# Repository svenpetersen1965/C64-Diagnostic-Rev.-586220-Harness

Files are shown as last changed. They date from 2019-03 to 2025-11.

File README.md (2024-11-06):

# C64-Diagnostic-Rev.-586220-Harness
The Diagnostic Rev. 586220 is a widely accepted test tool for the Commodore C64. It tests the RAM, ROMs and 
the peripheral chips (VIC, SID, CIA). To test all interfaces, a feedback is required. This is provided by this harness.

Find more information about the cable making involved <a href="http://tech.guitarsite.de/cable_making.html">on my website</a>

# Rev. 0
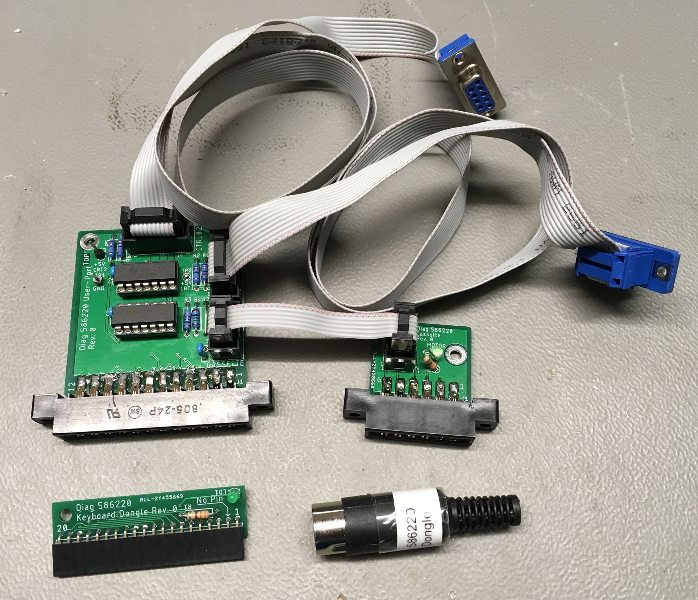
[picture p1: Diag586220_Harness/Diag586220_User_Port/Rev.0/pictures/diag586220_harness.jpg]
Diagnostic Harness

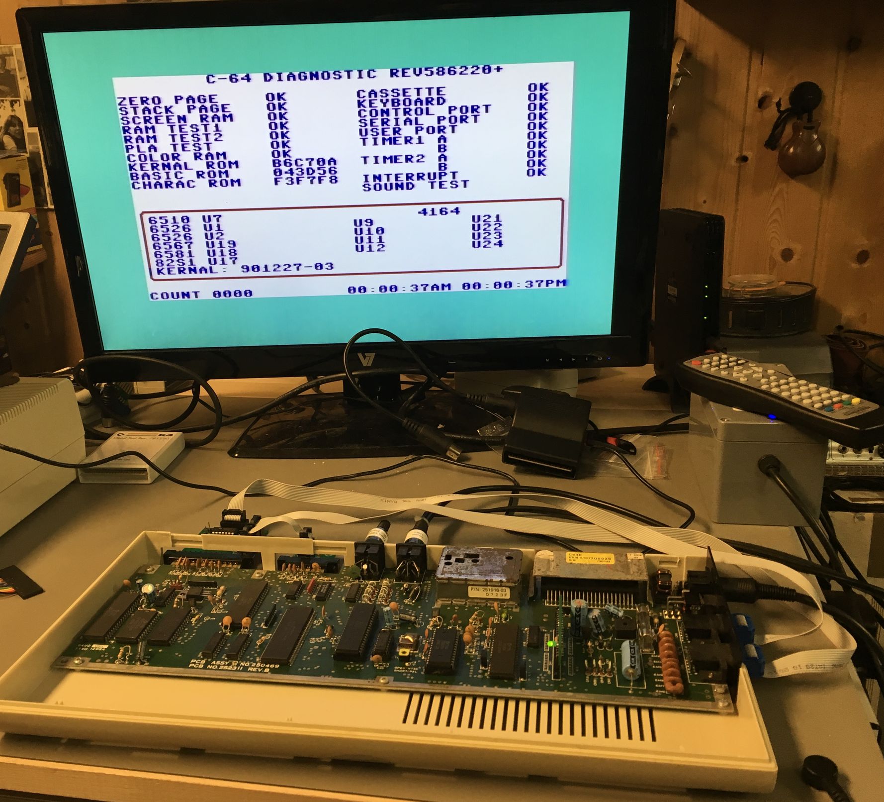
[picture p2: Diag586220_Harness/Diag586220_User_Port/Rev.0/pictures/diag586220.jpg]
Diagnostic 586220 running on a C64


This repository contains all eagle files, gerber files, BOM, descriptions and cable drawings. The main documentation is contained in the User Port section.

Depending on where the parts and pcbs are purchased, the price for the complete harness is less than 20€ (2019).

Now, a 3D printed case for the user port and the cassette donge is designed and the stl files etc. are available here. 

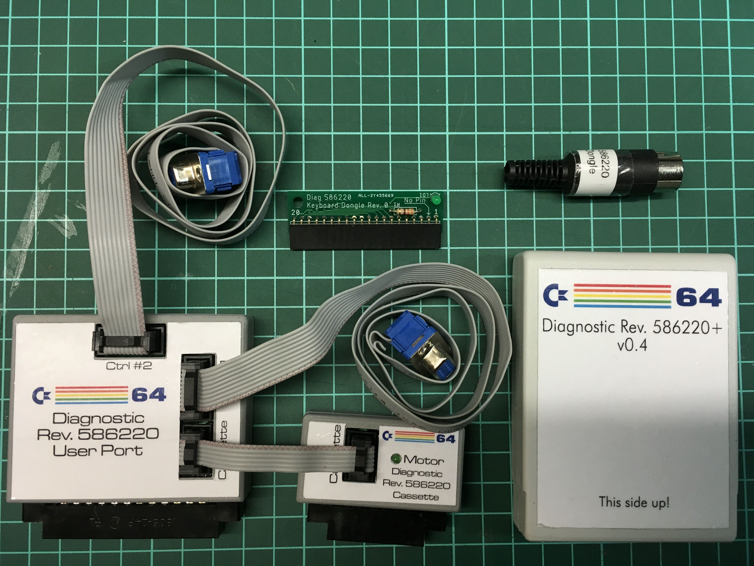
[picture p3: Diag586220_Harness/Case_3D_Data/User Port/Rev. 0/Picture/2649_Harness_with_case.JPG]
Diagnostic Harness with cases


# Rev. 1
Revision 1 is released now. It fixes the "False OK" of the Control Port test, while the keyboard dongle is inserted. This is a phenomenon, that applies to all sorts of harnesses for Diagnostic Rev. 586220. Please refer to <a src="http://tech.guitarsite.de/c64_diag_harness.html">my website</a>

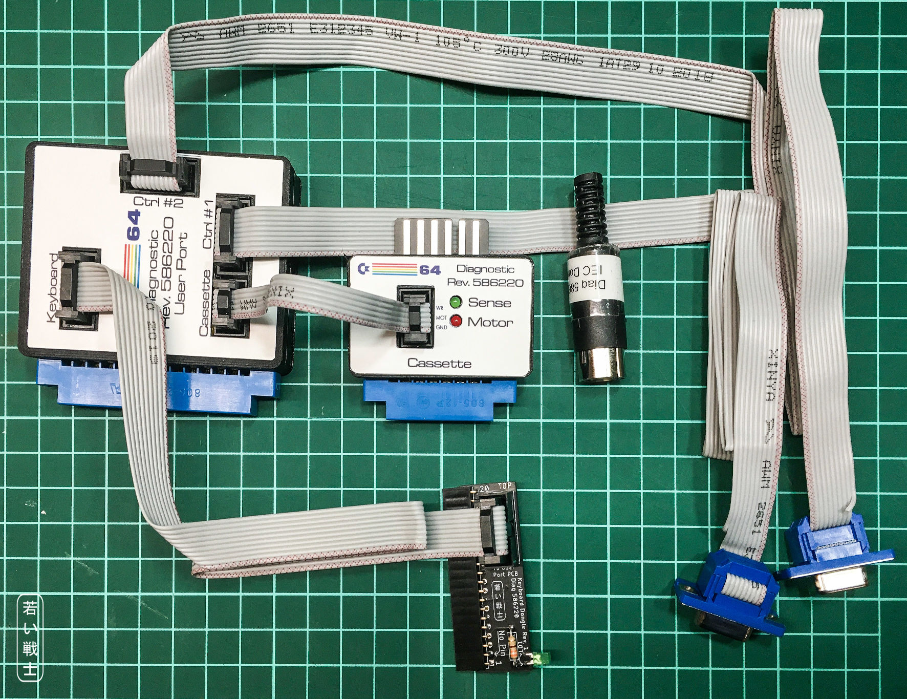
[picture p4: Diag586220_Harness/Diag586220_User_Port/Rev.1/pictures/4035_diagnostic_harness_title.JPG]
Diagnostic Harness Rev. 1


# Extended Keyboard Dongle (do not build, unless you are sure, what it is required for)
A fix for existing harnesses is the <b>extended</b> Keyboard Dongle. It can be combined with Rev. 0 of this harness and all other Harnesses. It only requires a connection to the Cassette Port Dongle. It is not required with Rev. 1 of the harness or later. 

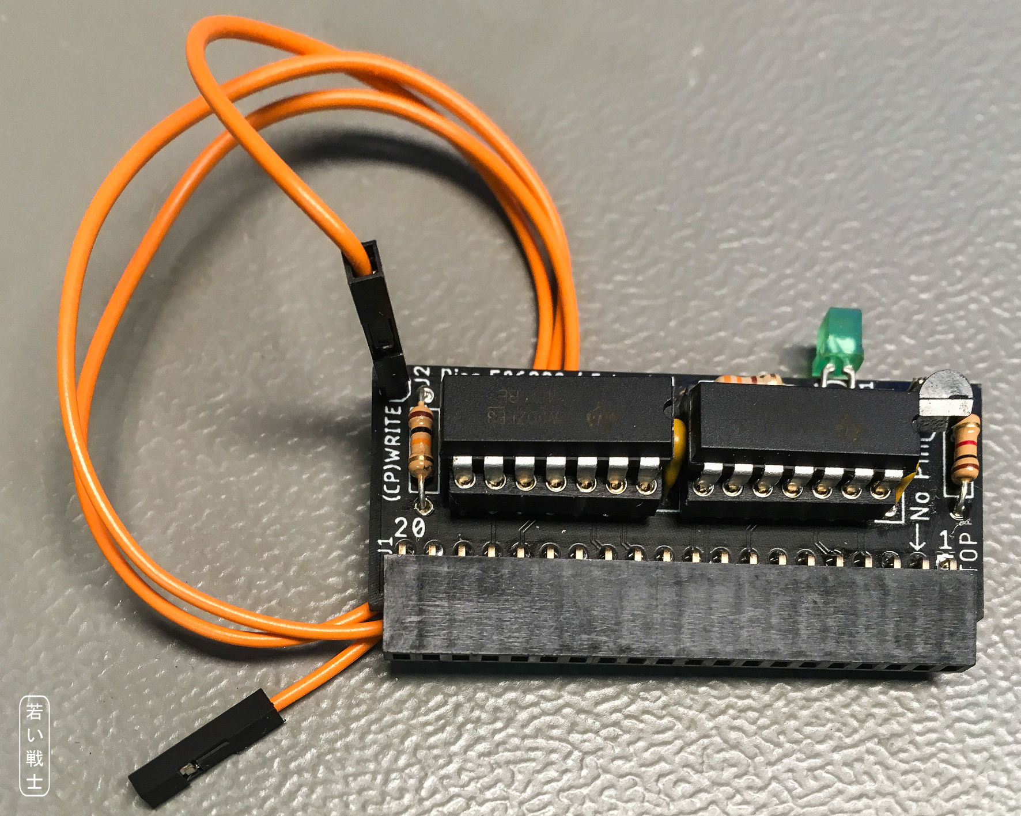
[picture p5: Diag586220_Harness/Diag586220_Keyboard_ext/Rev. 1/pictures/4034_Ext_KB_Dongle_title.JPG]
Extended keyboard Dongle


# Keyboard dongle with 90° header
Some people want to test the C64 mainboard while being mounted. The keyboard cable connector is conflicting here. Some leave out the strain relief. This is not a great solution. A 90° boc pin header can be used insted of the vertical one. This swapps the pins, due to a different orientation. Since the symmetrical pinning of the header and the non-directional properties of the analog switches, this does not matter and is working fine. I only build this kind of KB dongle now.

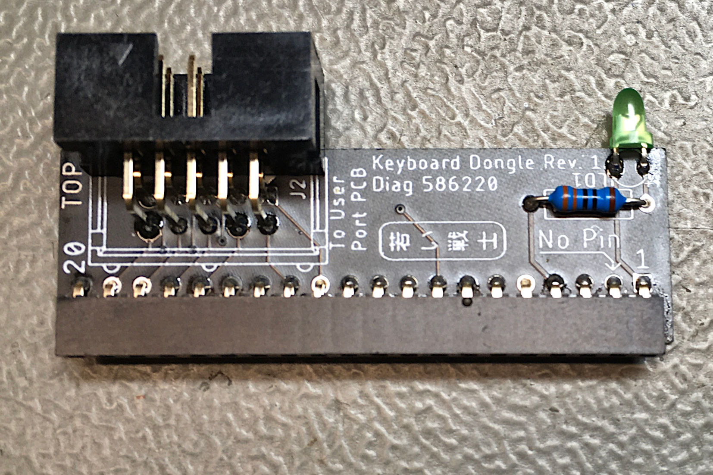
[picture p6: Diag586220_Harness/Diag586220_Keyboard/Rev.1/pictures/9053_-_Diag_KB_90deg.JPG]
Keyboard Dongle with 90° pin header


# The SMD Version
This version has no functional updates compared to Rev. 2 of the UP PCB and Rev. 1 of the Cassette SMD. Some prefer building SMD assemblies (me included). It is now fully tested.

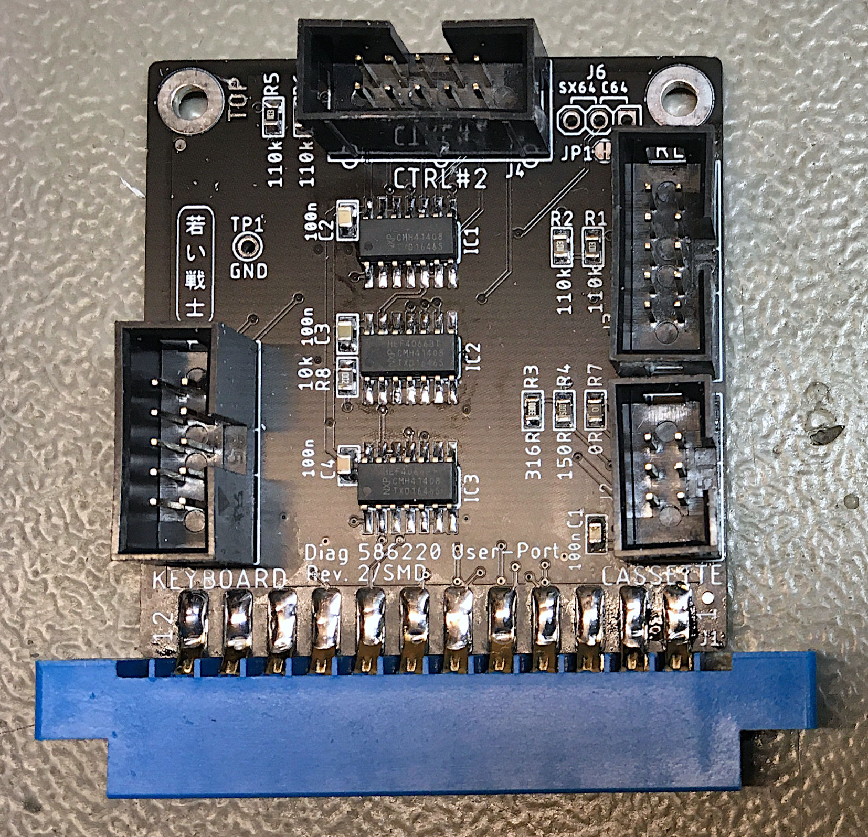
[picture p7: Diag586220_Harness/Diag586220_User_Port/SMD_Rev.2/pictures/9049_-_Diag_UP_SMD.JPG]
UP PCB R1v. 2/SMD
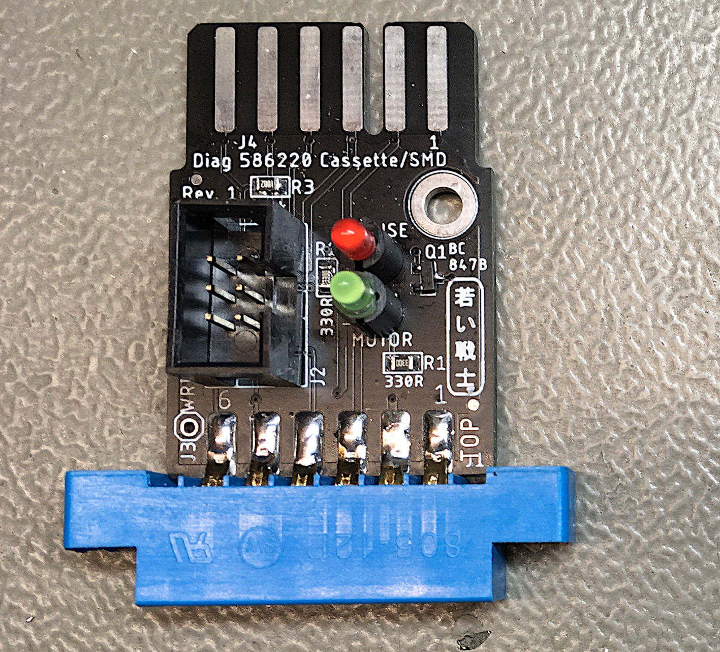
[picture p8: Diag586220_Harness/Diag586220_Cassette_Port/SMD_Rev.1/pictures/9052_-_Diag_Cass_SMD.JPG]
CP PCB Rev. 1/SMD
   

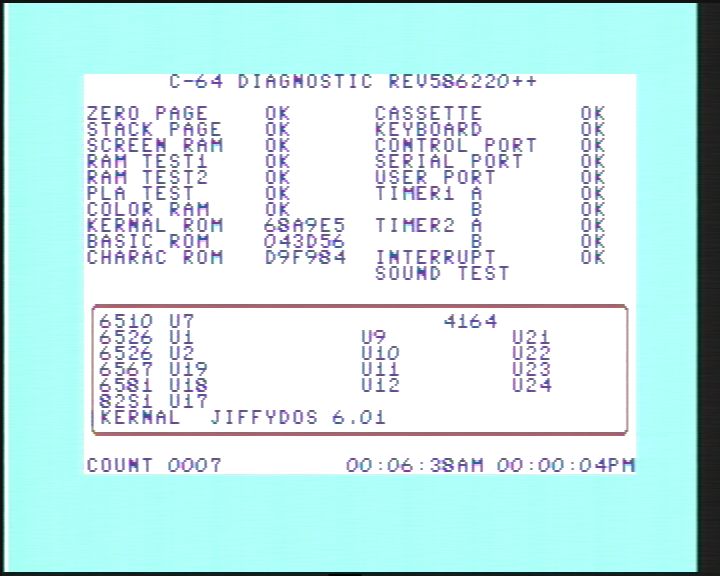
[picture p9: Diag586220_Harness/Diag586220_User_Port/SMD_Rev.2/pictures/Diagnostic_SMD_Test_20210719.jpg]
Diagnostic test


# Recommended Screws
* For the case, I have used 2.9mm x 9.5mm (self taping) screws for sheet metal (C 2,9x9,5H, DIN 7981).  
* For mounting the optional slide switch: DIN 7985, M2x6
* For mounting the optional voltmeter: 2.2mm x 4.5mm (self taping) screws for sheet metal (C 2,2x4,5H, DIN 7981). 

# C128 diagnostics
They keyboard PCB for the C128 is released now and included in this repository. 

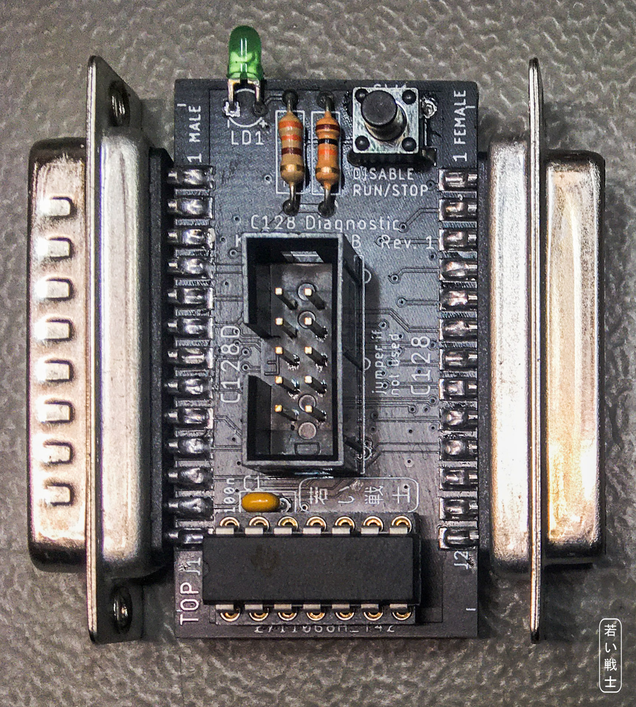
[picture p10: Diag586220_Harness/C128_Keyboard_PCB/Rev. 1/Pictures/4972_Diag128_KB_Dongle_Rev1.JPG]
C128 KB Dongle


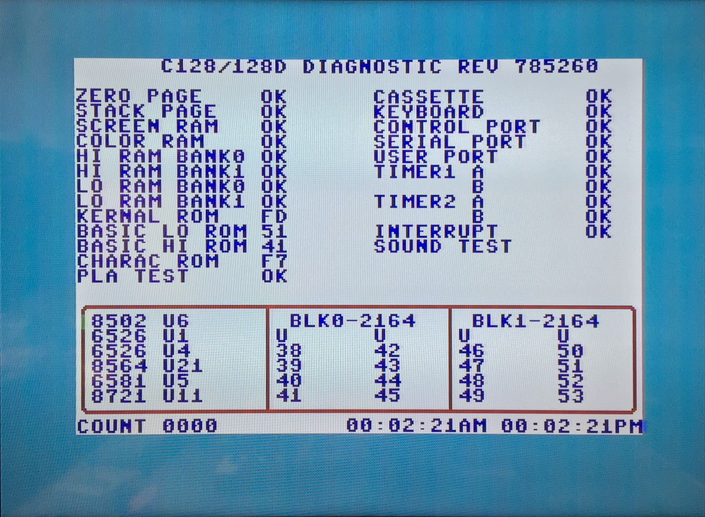
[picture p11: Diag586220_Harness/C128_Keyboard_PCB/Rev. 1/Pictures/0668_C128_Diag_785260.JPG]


A cartridge with the Diagnostic Rev. 785260 software is required. I recommend using the <a href="https://github.com/bwack/Versa64Cart">Versa64cart</a> for this purpose. Other 8k generic cartridges might also be working. /EXROM and /GAME have to be HIGH/open.

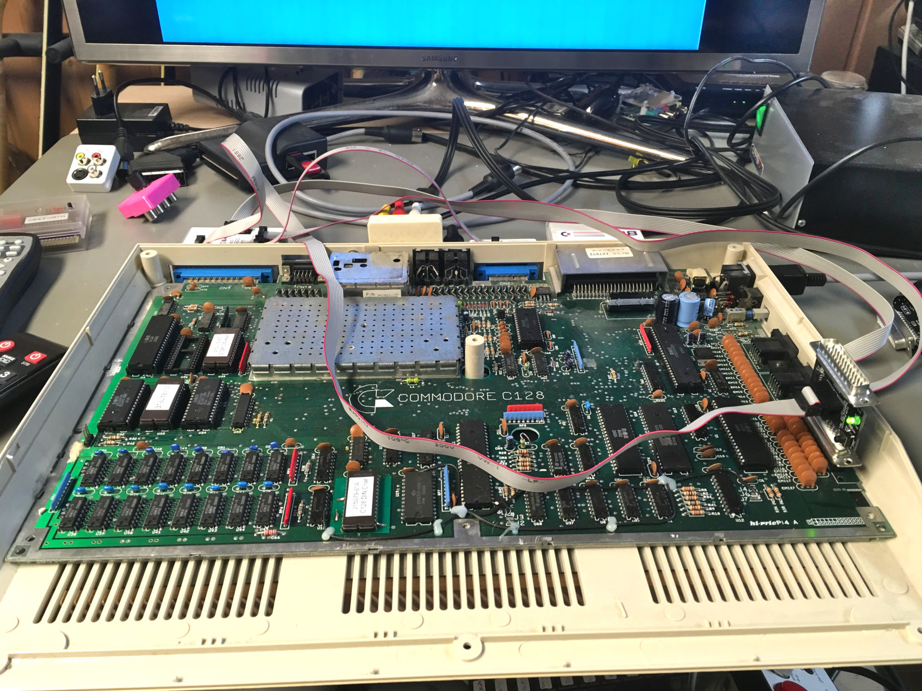
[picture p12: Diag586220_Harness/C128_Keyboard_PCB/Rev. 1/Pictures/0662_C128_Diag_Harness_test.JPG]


The <b>C128D and C128D-CR</b> require a longer cable (1m) between the user port PCB and the Cassette port dongle. Both work with the <b>C128D Diagnostic Rev. 785260</b>.  The keyboard ribbon cable should be 90cm for the C128D.

The cassette port ribbon cable requires to be 25cm long for the C128 and 70cm long for the C128D/DCR.

The <b>C128D-CR</b> does not provide +5V at the keyboard D-Sub jack. The keyboard dongle <b>does not work</b> here. A solution needs to be developed.  

I have noticed, that not all female D-Sub connectors provide a proper contact with the pin header on the C128 mainboard. Please keep this in mind. The recommended type is Amphenol/FCI DB25S064TLF (Digikey 609-1519-ND, more sources in the BOM v1.1 or later). 

You might want to check out the 3D printed dongle case from <a href="https://www.thingiverse.com/thing:4602956">retrorewind.ca</a>.

# SX-64 Diagnostics
Diagnosing an SX/64 requires disconnecting the internal disk drive. A cassette port dongle cannot be used, so the analog switches for testing the control ports need to be switched manually. This is an option with teh User Port PCB Rev. 2.

Also the Keyboard can be tested with the C128 KB dongle and a gender changer.

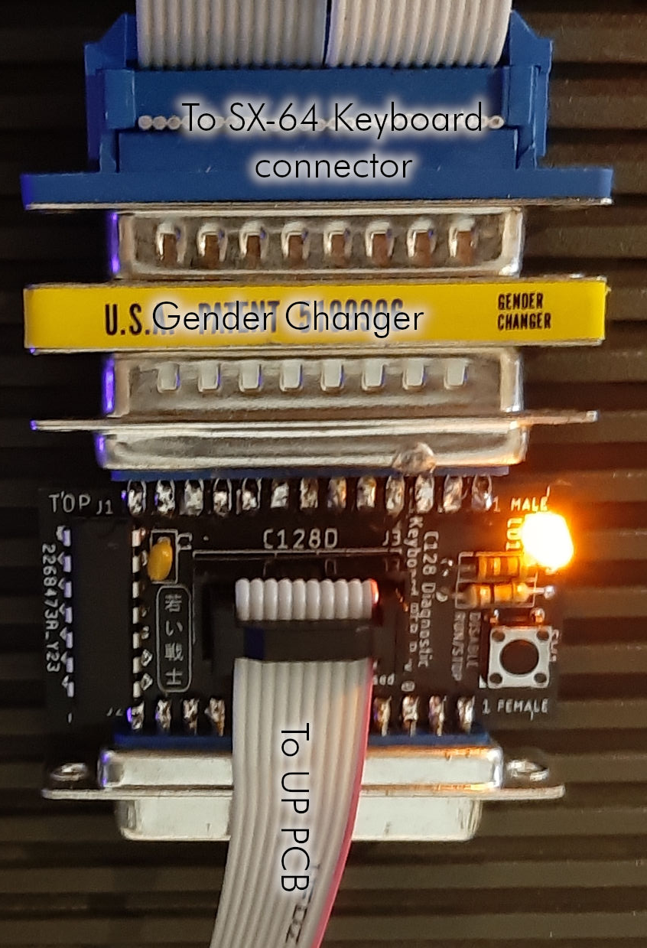
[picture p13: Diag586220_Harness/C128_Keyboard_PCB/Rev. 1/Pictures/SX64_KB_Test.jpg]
SX-64


The Diagnostic Rev. 586220++ is capable of detecting the SX-64 Kernal and then skip testing the cassette port.

# Other
you might want to check Jeff Birt's <a href="https://github.com/Jeff-Birt/COREi64_Dual_Diag_Cart_Case/tree/master">case</a> for the harness, too.

Find additional info about the harness on my <a href="http://tech.guitarsite.de/c64_diag_harness.html">website</a>.

Jeff Birt provided the information of the cable lengths for C128 diagnostics. This is part of the documentation now. 

# User Port PCB Rev. 2
The user Port PCB Rev. 2 fits into the User Port Case Rev. 1. It adds an option for the SX-64: Since the SX-64 has no
Cassette Port, the Feedbacks for the CVontrol Port are not switched automatically by the software. Rev. 2 allows to
switch on the feedbacks manually. A User Port Case for thei option has been made. It incorporates a cut out for a slide
switch (standard 19mm hole pitch). This switch can be connected top JP1. For this option the cutpad has to be cut open. 

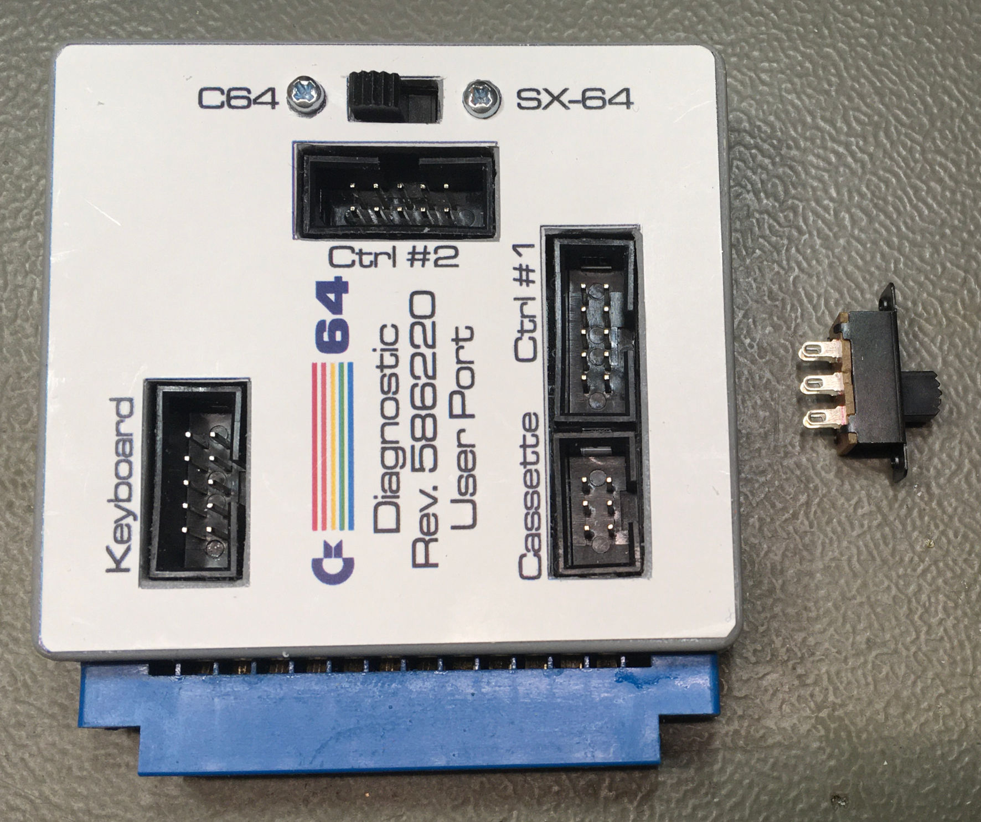
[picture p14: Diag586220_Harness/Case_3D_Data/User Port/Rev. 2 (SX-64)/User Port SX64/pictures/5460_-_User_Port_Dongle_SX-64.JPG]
User Port Case SX-64 option


# User Port PCB Rev. 3
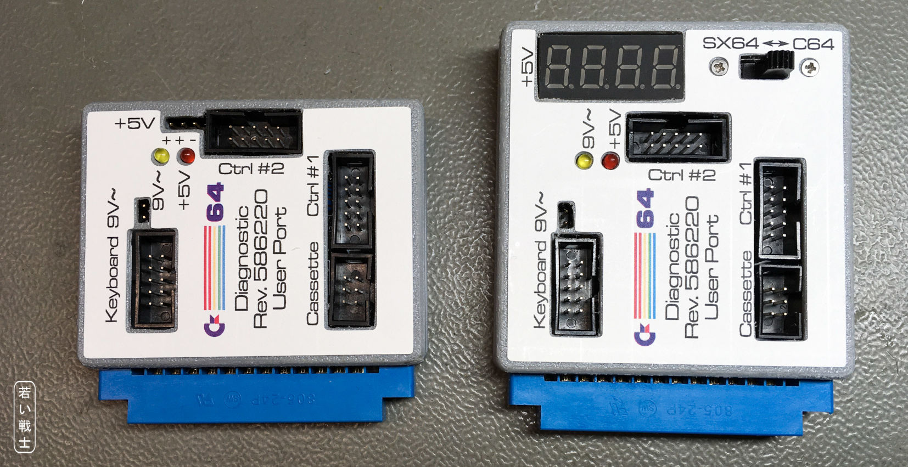
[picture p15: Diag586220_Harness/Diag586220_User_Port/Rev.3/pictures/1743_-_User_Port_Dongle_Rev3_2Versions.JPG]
User Port Rev. 3


The User Port Rev. 3 Dongle (THT and SMD versions in this repository) is providing two LED for voltage intocations (+5V and 9VAC). Further, there are pin headers for measuring those voltages at the user port. The +5V pin header allows connecting a 4 digit "precision" panel meter. I have some trust issues with those panel meters, but they are a nice light show.  

Nov. 2024: There is a new version of the case (the STLs are ending on "_noVM_SX.stl"). This version allows to measure the voltages at the pin headers with your multimeter and configure the SX64 or C64 option via jumper. That jumper should be the type with a "handle". 

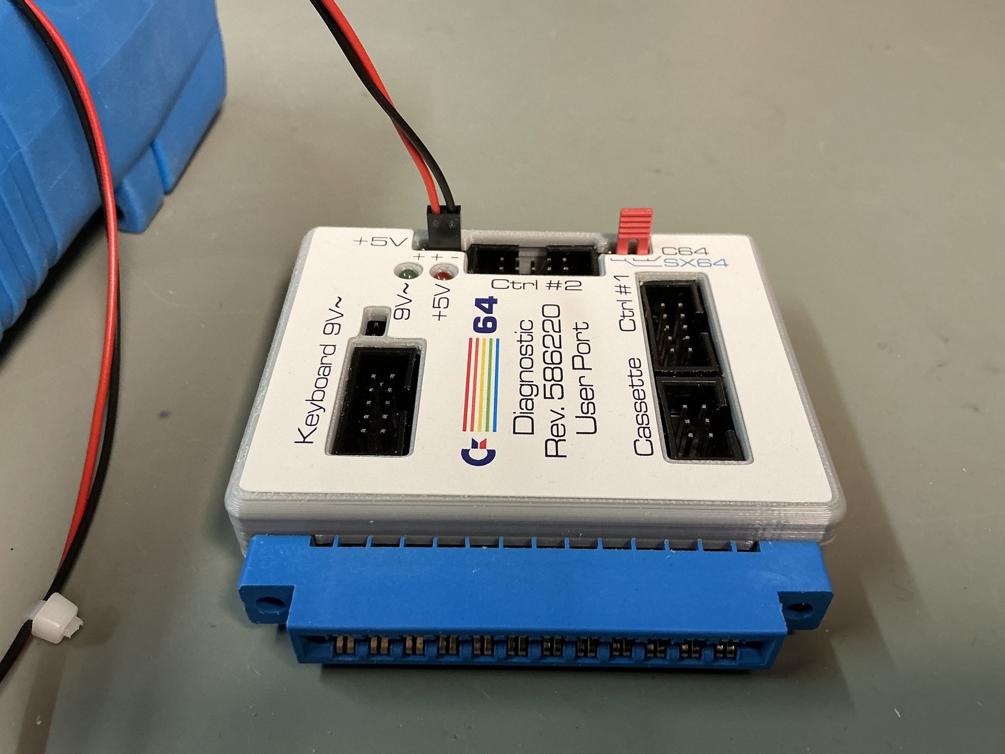
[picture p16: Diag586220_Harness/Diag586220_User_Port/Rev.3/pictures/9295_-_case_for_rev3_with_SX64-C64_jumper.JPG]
User Port Rev. 3/sx64-c64


<b>The solder bridge JP1 near the pin header J6 (which has to be placed) needs to be open!</b>

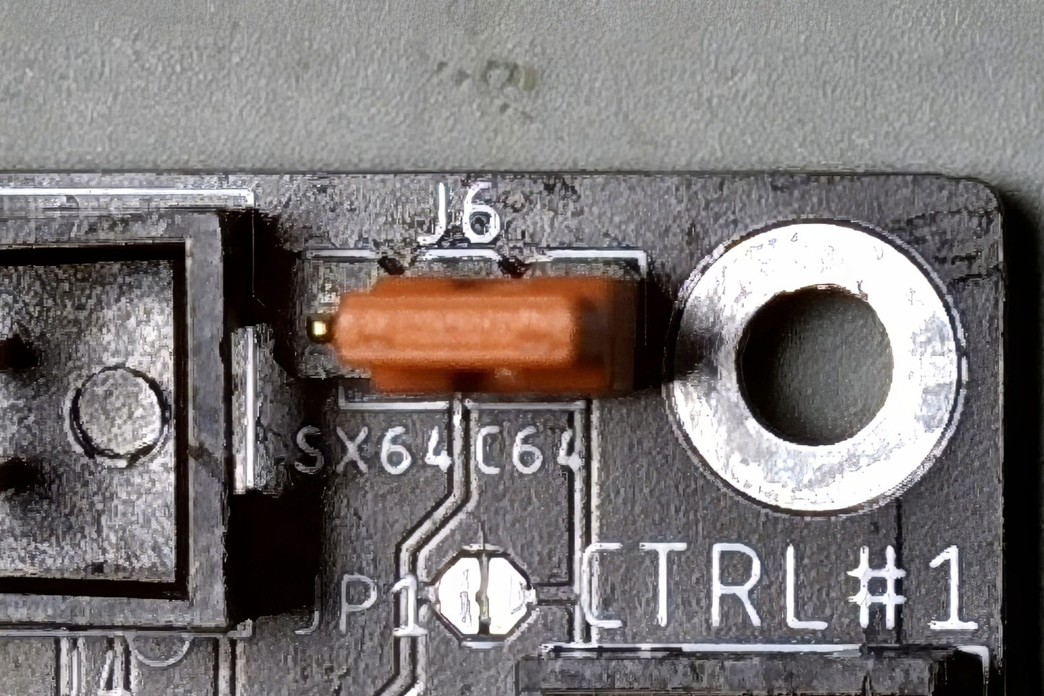
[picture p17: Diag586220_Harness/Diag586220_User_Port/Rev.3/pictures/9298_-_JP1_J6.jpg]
JP1 and J6


Therefore, it has to be cut along the gap with a scalpel or exacto knife. It is best to check the success with an ohmmeter/multimeter.

The cable for measuring the voltage (+5VDC and 9VAC) at the pin pin headers consists of two AWG24 wires, preferable in different colors, on one end is a two way Dupont connector, on the other end 4mm lab connectors. Holding them together with cable ties is maybe not such a bad idea.

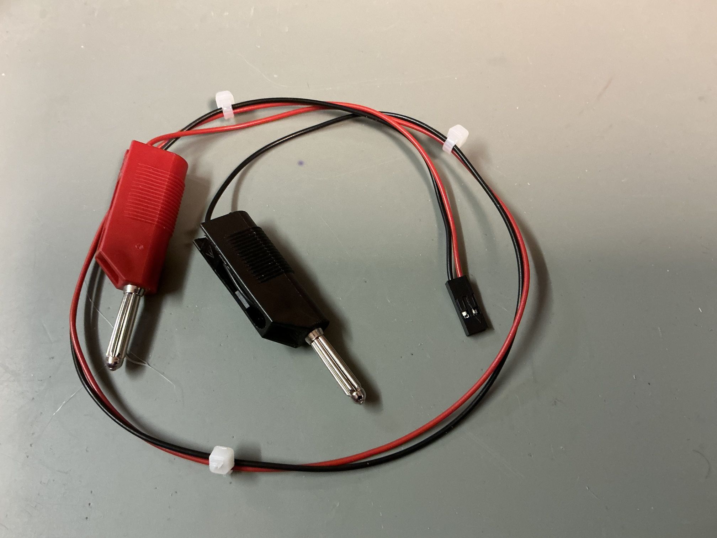
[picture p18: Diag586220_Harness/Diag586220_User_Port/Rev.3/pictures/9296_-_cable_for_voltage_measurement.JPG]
cable for multimeter


To prevent short circuit, you should plug the lab connectors in the multimeter first, there are some security multimeter connectors, too. 

# Analog Switch IC (User Port Dongle)
Originally, the analog switches are <b>4066</b>. The 74HC4066 was also tested and works perfectly.

# BOM Value
The BOM values are calculated in May 2020. The calculation is based on the item prices from reichelt.de. They might differ from distributor to distributor. The edge connector prices are based on ebay shoppings. The calculated prices do not include any shipping fees. 

* User Port PCB plus cables and IEC dongle: 13.38€
* Cassette Port Dongle: 4.99€
* Keyboard Dongle: 1.85€
* C128 Keyboard Dongle: 3.23€

The 3D printed cases and the labels are not included in the price calculation.

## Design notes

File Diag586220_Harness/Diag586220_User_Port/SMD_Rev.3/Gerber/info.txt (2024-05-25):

      
       Board: C64_Userport_Test_SMD
       Rev.:  3
  
       Files:
       ======
  
       All Gerber files are generated in extended gerber format (RS274X)
       *.TOP        : Film top copper
       *.BOT        :  -"- bottom copper
       *.STC        :  -"- top soldermask 
       *.STS        :  -"- bottom soldermask
       *.PLC        :  -"- silk screen top
       *.PLS        :  -"- silk screen bottom
       *.CRC        :  -"- cream top
       *.DK         : Drills plated Through (Excellon)
       *.NDK        : Drills not plated Through (Excellon)
       *.OUT        : Board outline

       Board Size:
       ===========
       Length     :   55.0 mm
       Width      :   53.0 mm
       Thickness  :   1.6 mm
       Material   :   FR 4
       Copper     :   35 um
       Surface    :   HASL
       
       Remarks:
       ========
       drill >= 0.35mm
       width >= 8mil
       distance >= 6mil

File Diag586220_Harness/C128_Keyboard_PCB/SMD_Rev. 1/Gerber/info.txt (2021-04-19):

      
       Board: C128_Keyb_Test_SMD
       Rev.:  1
  
       Files:
       ======
  
       All Gerber files are generated in extended gerber format (RS274X)
       *.TOP        : Film top copper
       *.BOT        :  -"- bottom copper
       *.STC        :  -"- top soldermask 
       *.STS        :  -"- bottom soldermask
       *.PLC        :  -"- silk screen top
       *.PLS        :  -"- silk screen bottom
       *.CRC        :  -"- top cream
       *.DK         : Drills plated Through (Excellon)
       *.NDK        : Drills not plated Through (Excellon)
       *.OUT        : Board outline

       Board Size:
       ===========
       Length     :   52.0 mm
       Width      :   28.0 mm
       Thickness  :   1.6 mm
       Material   :   FR 4
       Copper     :   35 um
       Surface    :   HASL
       
       Remarks:
       ========
       drill >= 0.35mm
       width >= 8mil
       distance >= 6mil

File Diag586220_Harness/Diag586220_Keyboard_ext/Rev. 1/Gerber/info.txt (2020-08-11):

      
       Board: C64_Keyb-Test-ext
       Rev.:  1
  
       Files:
       ======
  
       All Gerber files are generated in extended gerber format (RS274X)
       *.TOP        : Film top copper
       *.BOT        :  -"- bottom copper
       *.STC        :  -"- top soldermask 
       *.STS        :  -"- bottom soldermask
       *.PLC        :  -"- silk screen top
       *.PLS        :  -"- silk screen bottom 
       *.DK         : Drills plated Through (Excellon)
       *.NDK        : Drills not plated Through (Excellon)
       *.OUT        : Board outline

       Board Size:
       ===========
       Length     :   55.0 mm
       Width      :   22.0 mm
       Thickness  :   1.6 mm
       Material   :   FR 4
       Copper     :   35 um
       Surface    :   HASL
       
       Remarks:
       ========
       drills >= 0.35mm
       width >= 8mil
       distance >= 6mil

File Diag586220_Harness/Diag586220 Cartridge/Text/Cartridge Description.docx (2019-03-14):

Diagnostic Rev. 586220 Cartridge

Short description

The diagnostic cartridge can be easily built from existing parts. All information was obtained from the website “World of Jani” (http://blog.worldofjani.com/?p=164). The binary file for programming the (27C512) EPROM was generated with the cartconv tool from the VICE C64 emulator from the 586220plus v0.4 CRT file, which was also downloaded from World of Jani.

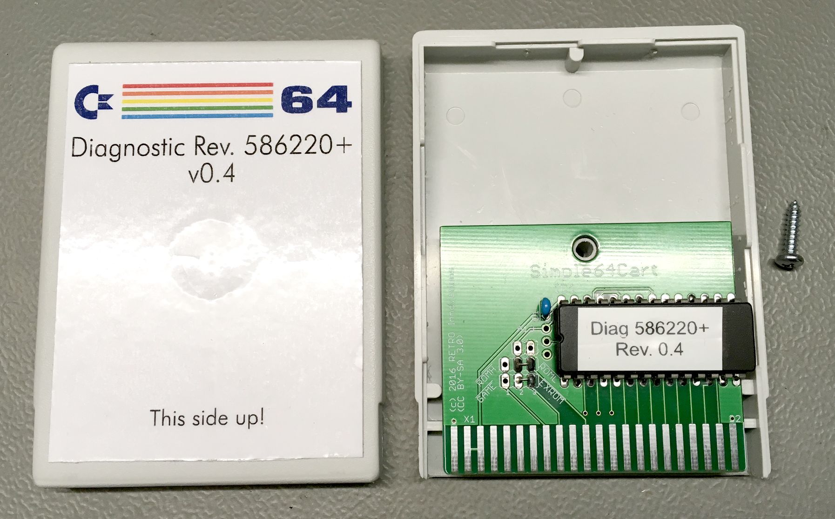
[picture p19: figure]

Figure 1: Diagnostic Cartridge with SimpleC64Cart

The cartridge can be made with a variety of existing cartridge boards. Here the SimpleC64Cart (http://www.go4retro.com/downloads/Simple64Cart/) was used.

The correct settings are /GAME=HIGH (open), /EXROM=LOW (closed jumper), and the /OE of the EPROM is connected to /ROML.

The SimpleC64Cart has a fixed setting for A13, A14 and A15 (all HIGH), so the binary file has to be loaded to Address 0xE000.

The cartridge case was purchased from retro-store.de (https://restore-store.de/home/117-modulgehaeuse-c64c128-grau-ohne-labelfeld.html). Those cases are low profile, which is the reason, why the EPROM is not socketed and the jumpers are bridged with wires.

Cartridge Description.docx 14.03.2019 09:13 Drafted by Sven Petersen Page 2 of 2 Doc.-No.: 000-6-00-00

Cartridge Description.docx 14.03.2019 09:13 Drafted by Sven Petersen Page 1 of 1

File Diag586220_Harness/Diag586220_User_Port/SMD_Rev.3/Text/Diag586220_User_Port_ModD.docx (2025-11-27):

Diagnostic Rev. 586220 Harness - User Port SMD Rev. 3

Module Description

The User Port module is the central part of the Diagnostic Rev. 586220 harness. It provides the required feedback connections for testing the C64’s CIA U2, which is connected to the user port. It also holds the analog switches, which are required to test the Control Ports and the feedback connections for testing the cassette port.

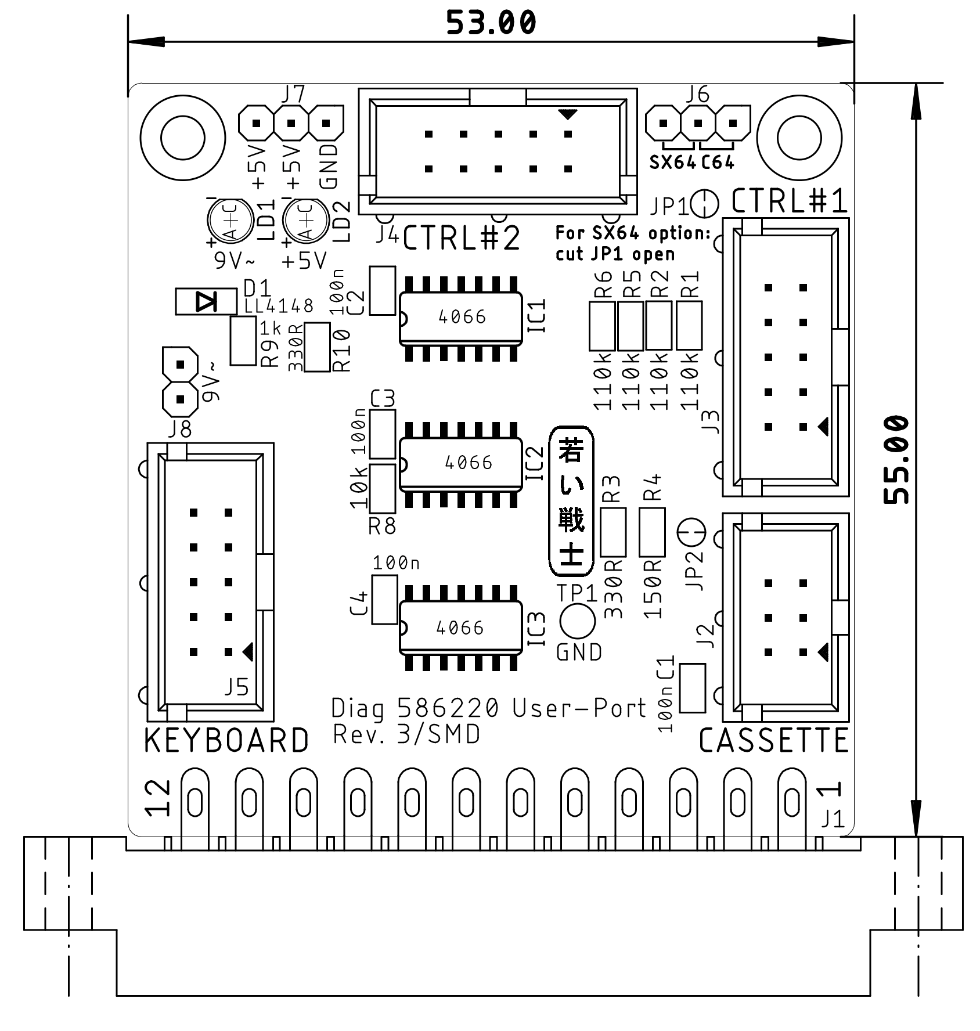
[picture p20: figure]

Figure 1: User Port SMD PCB Rev. 3

The MOTOR output signal of the cassette port has approximately a 6V level. To use it as a control signal for operating logic devices, a voltage divider consisting out of a 150Ω resistor and a 320Ω (316Ω works here, 330Ω should work as well) resistor is required, which has a ratio of about 0.7.

This way, the MOTOR signal is fed back to the WRITE pin and is also used for switching the analog switches between the joystick signals of both control ports.


Figure 2: User Port Dongle Rev. 3, without and with a panel voltmeter

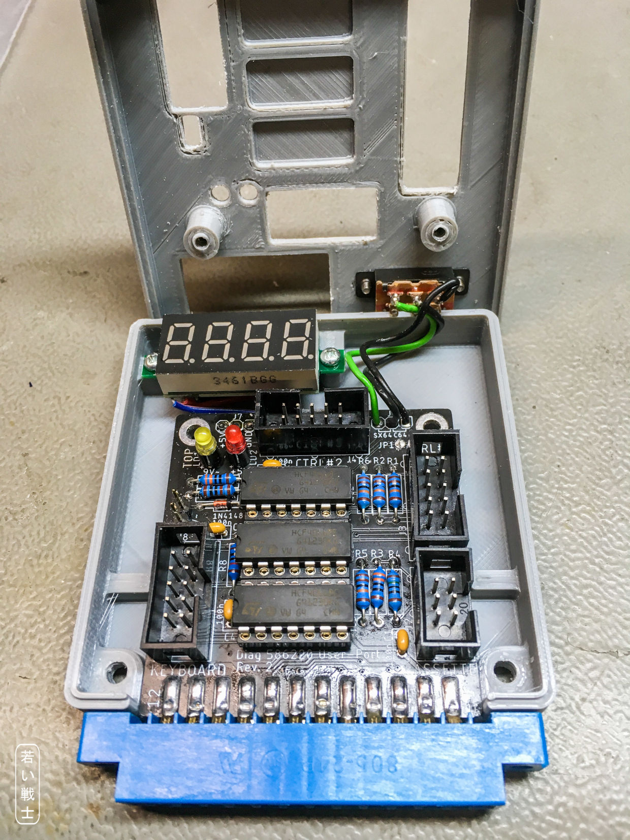
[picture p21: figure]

Figure 3: Installation of the panel voltmeter and the switch for SX/64 and C64 mode (THT Board)

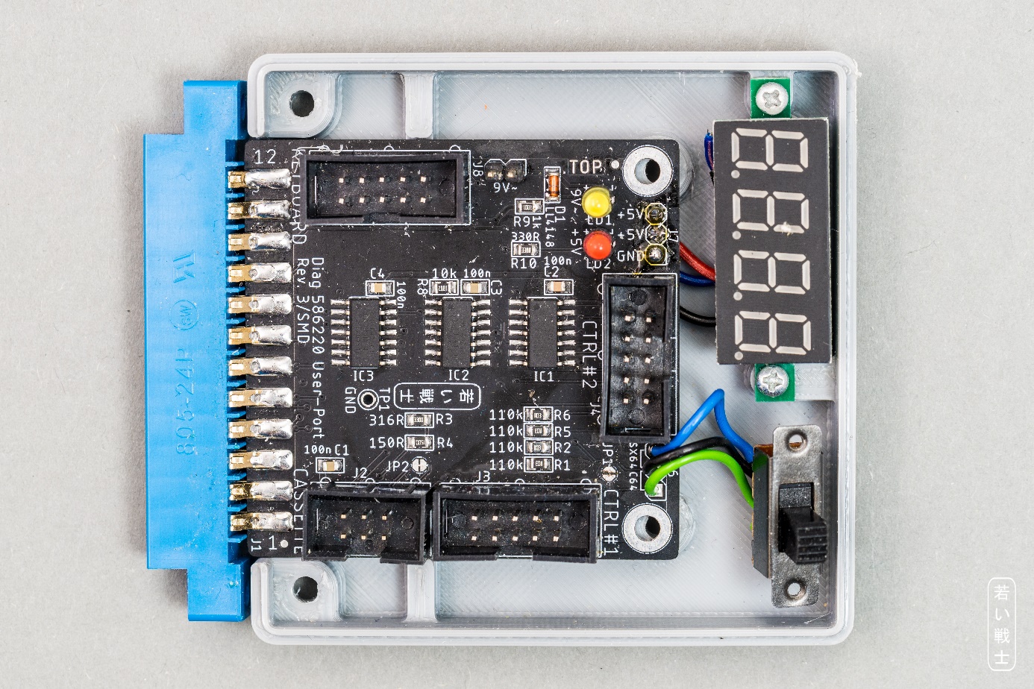
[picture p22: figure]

Figure 4: Installation without the panel voltmeter, but the pin headers for voltage measurement.

# Rev. 1

New on Rev. 1 are the analog switches for the keyboard feedbacks. This feature requires a ribbon cable to the keyboard PCB (Rev. 1). It does not connect to the Keyboard PCB Rev. 0.

The reason for this modification:

The feedbacks on keyboard dongle are identical to the feedback provided by the analog switches for the control port feedback. Since the feedbacks on the keyboard dongle are permanent, the analog switches are not effective and the control ports are not fully tested. This can lead to a false “OK”.

The new version can open the keyboard feedbacks with additional analog switches, so it is not required to remove the keyboard dongle for proper testing anymore.

# The SX-64 test feature (Rev. 2 and later)

The SX-64 does not provide a cassette port. Since the control port (and keyboard) feedbacks are switched by the cassette port MOTOR signal, J6 provides a manual switching option. It can either be jumpered or a toggle switch can be connected. Connecting J6 pin 1 and pin 2 configures the regular C64 setup (the feedbacks are controlled by MOTOR), connecting pin 3 and pin 2 configured the control port feedbacks being switched on permanently for the SX-64 option. For switching between options, the cut pad JP1 has to be opened. On default (closed) it selects the C64 option.

By default, the C64 only mode is selected, which meansJP1 is closed. Do not connect a switch to J6 without opening JP1.

The keyboard testing of the SX-64 requires the C128 keyboard PCB and a DB female-female gender changer. For complete SX-64 testing, the diagnostic software has to be run in C64 mode (control port feedbacks off, keyboard feedbacks on) at least one pass and then in SX-64 mode (control port feedbacks on, keyboard feedbacks off).

# Rev. 3: Voltage indicators and voltmeter

The purpose of the voltmeter is measuring the +5VDC inside the C64, which does make sense. A too low voltage here might indicate a bad power switch or a bad/oxidized power jack.

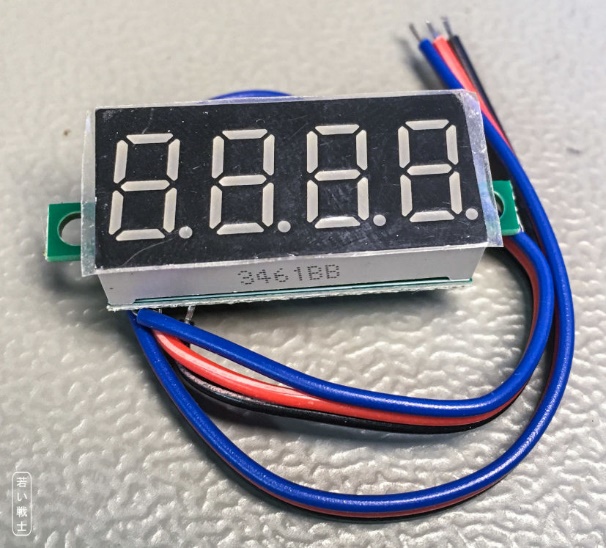
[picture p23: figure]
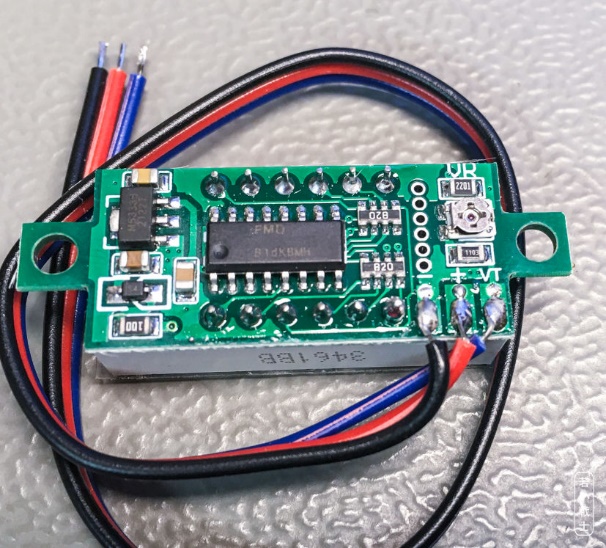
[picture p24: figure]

Figure 5: Front and back of the 0.36" 4-digit voltmeter

Previously, three-digit and four-digit models have been tested. The three-digit models are not suitable, since they showed an error of almost 100mV. The four-digit models can be adjusted on a little potentiometer. Adjustment is required and should be performed before the assembled PCB is installed in the case.

The adjustment is best performed by measuring the voltage between the GND pin and one of the +5V pins of J7, then adjusting the reading of the voltmeter at the potentiometer on the back side. This potentiometer is shown in Figure 5: Front and back of the 0.36" 4-digit voltmeter.

Note: The panel voltmeters, that I have bought for this project were sufficiently accurate, but I would not grant for all 4 digit “precision panel meters, so the recommended configuration is to install a pin header and perform the measurement with a multimeter.

# Pinouts

## User Port

J1- Edge Connector (2x12, 3.96mm pitch)

Pin | Signal | Pin | Signal
1 | GND | A | GND
2 | +5V | B | /FLAG2
3 | /RESET | C | PB0
4 | CNT1 | D | PB1
5 | SP1 | E | PB2
6 | CNT2 | F | PB3
7 | SP2 | H | PB4
8 | /PC2 | J | PB5
9 | ATN | K | PB6
10 | 9VAC(1) | L | PB7
11 | 9VAC(2) | M | PA2
12 | GND | N | GND

## Cassette Port

J2 – 2x3 pin header for a ribbon cable connected to the cassette port PCB (project number 114).

Pin | Signal | Pin | Signal
1 | GND | 2 | n.c.
3 | MOTOR | 4 | READ
5 | WRITE | 6 | SENSE

## Control Port #1

J3 – 2x5 pin header for a ribbon cable which connects via a D-SUB 9 (female) to the control port.

Pin | D-SUB | Signal | Pin | D-SUB | Signal
1 | 1 | JOYA0 (up) | 2 | 6 | FIREA
3 | 2 | JOYA1 (down) | 4 | 7 | +5VCTR1
5 | 3 | JOYA2 (left) | 6 | 8 | n.c. (GND)
7 | 4 | JOYA3 (right) | 8 | 9 | POTXA
9 | 5 | POTYA | 10 | - | n.c.

## Control Port #2

J4 – 2x5 pin header for a ribbon cable which connects via a D-SUB 9 (female) to the control port.

Pin | D-SUB | Signal | Pin | D-SUB | Signal
1 | 1 | JOYB0 (up) | 2 | 6 | FIREB
3 | 2 | JOYB1 (down) | 4 | 7 | +5VCTR2
5 | 3 | JOYB2 (left) | 6 | 8 | n.c. (GND)
7 | 4 | JOYB3 (right) | 8 | 9 | POTXB
9 | 5 | POTYB | 10 | - | n.c.

## Keyboard

J5 – 2x5 pin header for a ribbon cable which connects to the keyboard PCB.

Pin | Signal | Pin | Signal
1 | Keyboard PB0 | 2 | Keyboard PA0
3 | Keyboard PB4 | 4 | Keyboard PA4
5 | Keyboard PB3 | 6 | Keyboard PA3
7 | Keyboard PB2 | 8 | Keyboard PA2
9 | Keyboard PB1 | 10 | Keyboard PA1

SX-64 Option

J6 – 1x3 pin header (pitch 2.54mm)

Pin | Signal
1 | WRITE
2 | WRITE*
3 | +5V

To use J 6 for switching between SX-64 and C64, cut open JP1. This is the cut pad right beside J6.

Connection pin 1-2 selects the C64 option, connecting pin 2-3 selects the SX-64 option, which switches on the control port feedbacks.

## Panelmeter Connector

J7 – 1x3 pin header, 2.54mm pitch

Pin | Signal | Voltmeter
1 | GND | -
2 | +5V | +
3 | +5V | VT

## 9VAC Connector

J8 - 1x2 pin header, 2.54mm pitch

Pin | Signal
1 | 9VAC1
2 | 9VAC2

# Interconnects

## User Port

Pin | Signal | | Signal | Pin
4 | CNT1 | « | CNT2 | 6
5 | SP1 | « | SP2 | 7
8 | /PC2 | « | /FLAG2 | B
9 | ATN | « | PA2 | M
C | PB0 | « | PB4 | H
D | PB1 | « | PB5 | J
E | PB2 | « | PB6 | K
F | PB3 | « | PB7 | L

## Cassette Port

Pin | Signal | | Signal | Pin
1 | GND | | n/c | 2
3 | MOTOR | Volt.div. | WRITE | 5
4 | READ | « | SENSE | 6

## Control Ports

Signal | | Signal
FIREA | switched by MOTOR | FIREB
JOYA0 | switched by MOTOR | JOYB0
JOYA1 | switched by MOTOR | JOYB1
JOYA2 | switched by MOTOR | JOYB2
JOYA3 | switched by MOTOR | JOYB3
POTXA | via 110kΩ (R1) | +5V (CTR 1)
POTYA | via 110kΩ (R2) | +5V (CTR 1)
POTXB | via 110kΩ (R5) | +5V (CTR 2)
POTYB | via 110kΩ (R6) | +5V (CTR 2)

The digital signals of the control ports are connected by an analog switch. A HIGH level of the MOTOR signal will switch on.

The POT (paddle) signals are tested with a fix resistor of 110k, that is connected to the +5V provided by the respective control port.

# Cables

## User Port/Cassette Port Cable

One cable as shown in Doc.-No. 113-3-01-01 is required. It connects to J2. This cable needs to be longer for C128

## User Port/Control Cables

Two cables as shown in Doc.-Nr. 113-3-02-01 are required. They connect to J3 and J4.

## User Port/Keyboard PCB Cable

One cable as shown in Doc.-No. 113-3-04-01 is required. It connects to J5 and the keyboard PCB (C64 or C128). For the C128 this cable has to be longer.

## The IEC-Dongle

The IEC-Dongle is not attached to the PCB, it is an extra built.

6p. DIN plug, connect according to Doc.-No. 113-3-03-01

Pin | Signal | | Signal | Pin
1 | SRQ | « | DATA | 5
3 | ATN | « | CLK | 4

# Block diagram of the Diagnostic Harness Rev. 3

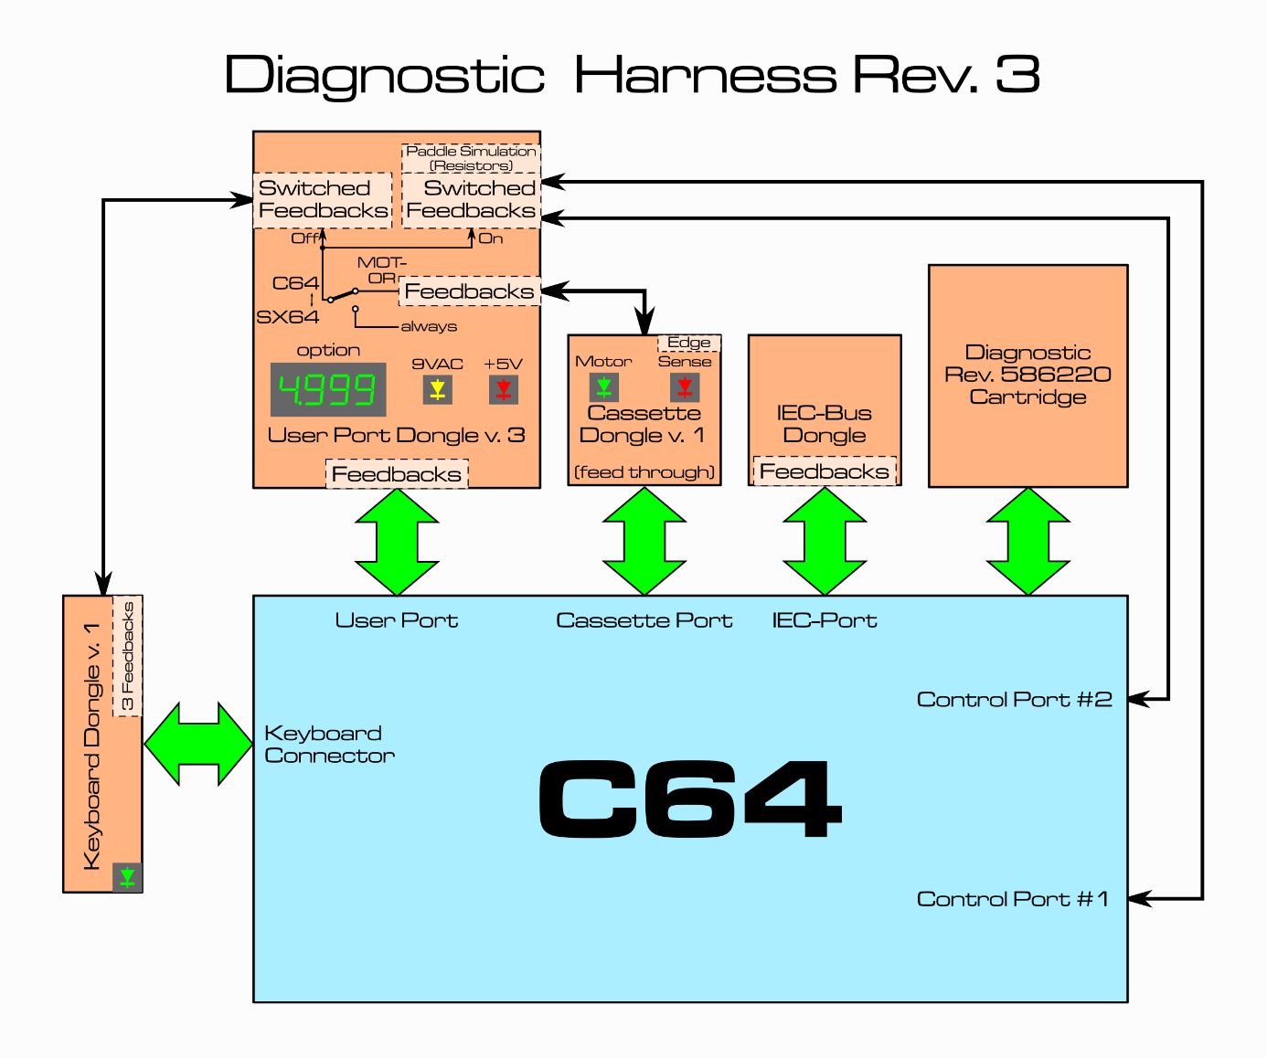
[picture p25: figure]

# Connecting the Voltmeter

The Voltmeter has three connections:
+ = positive supply voltage. It is connected to J7, Pin 2 (+5V)
- = negative supply voltage. It is connected to J7, Pin 1 (GND)
VT = measured voltage. It is connected to J7, Pin 3 (+5V)

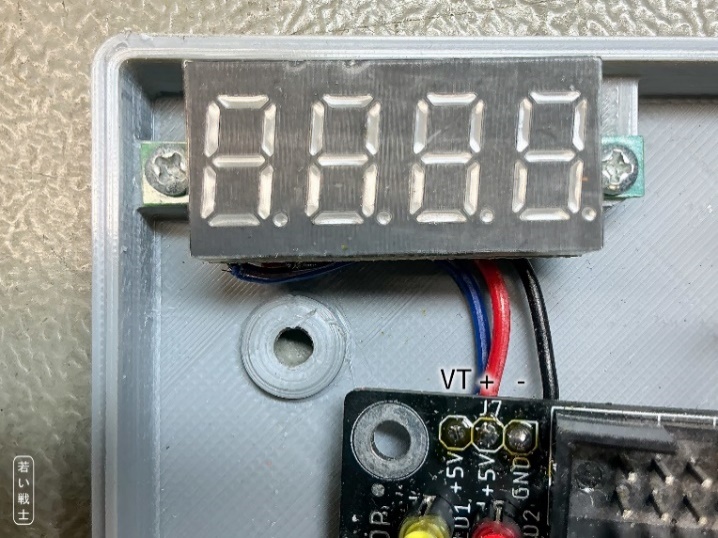
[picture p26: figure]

Figure 6: Connection of the panel voltmeter

# Revision History

## BOM v0.1 → v0.2

- Pos. 6: value 120k →110k
- Pos. 8: value 320R →316R

## Rev. 0 → Rev. 1

- This is a PCB revision
- Analog switches added (IC3)
- Pin header added (J5)
- New Ribbon Cable
- 3D printed case (Rev. 1) is required

## Rev. 1 → Rev. 2

- This is a PCB revision
- Pin header J6 and cup pad JP1 added
- It can either be installed in the Rev. 1 3D printed case, if no switch option SX64 is desired or in the User Port Case SX-64, which provides mounting holes for a toggle switch (19mm hole distance, standard switch).

## Rev. 2 → Rev. 2 SMD

- This is the Rev. 2 with SMD parts for easier fabrication. No other technical changes were done.

## Rev. 2 SMD → Rev. 3 SMD

- LEDs added for presence indication of +5V and 9VAC
- Connector for panel meter
- Connector for 9VAC
- New 3D printed cases.

Diag586220_User_Port_ModD.docx 27.11.2025 13:32 Drafted by Sven Petersen Page 2 of 2 Doc.-No.: 179-6-01-03

Diag586220_User_Port_ModD.docx 27.11.2025 13:32 Drafted by Sven Petersen Page 1 of 1 Doc.-No.: 113-6-01-01

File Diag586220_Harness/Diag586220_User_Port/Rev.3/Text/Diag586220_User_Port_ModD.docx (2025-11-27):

Diagnostic Rev. 586220 Harness - User Port Rev. 3

Module Description

# Introduction

The User Port module is the central part of the Diagnostic Rev. 586220 harness. It provides the required feedback connections for testing the C64’s CIA U2, which is connected to the user port. It also holds the analog switches, which are required to test the Control Ports and the feedback connections for testing the cassette port.

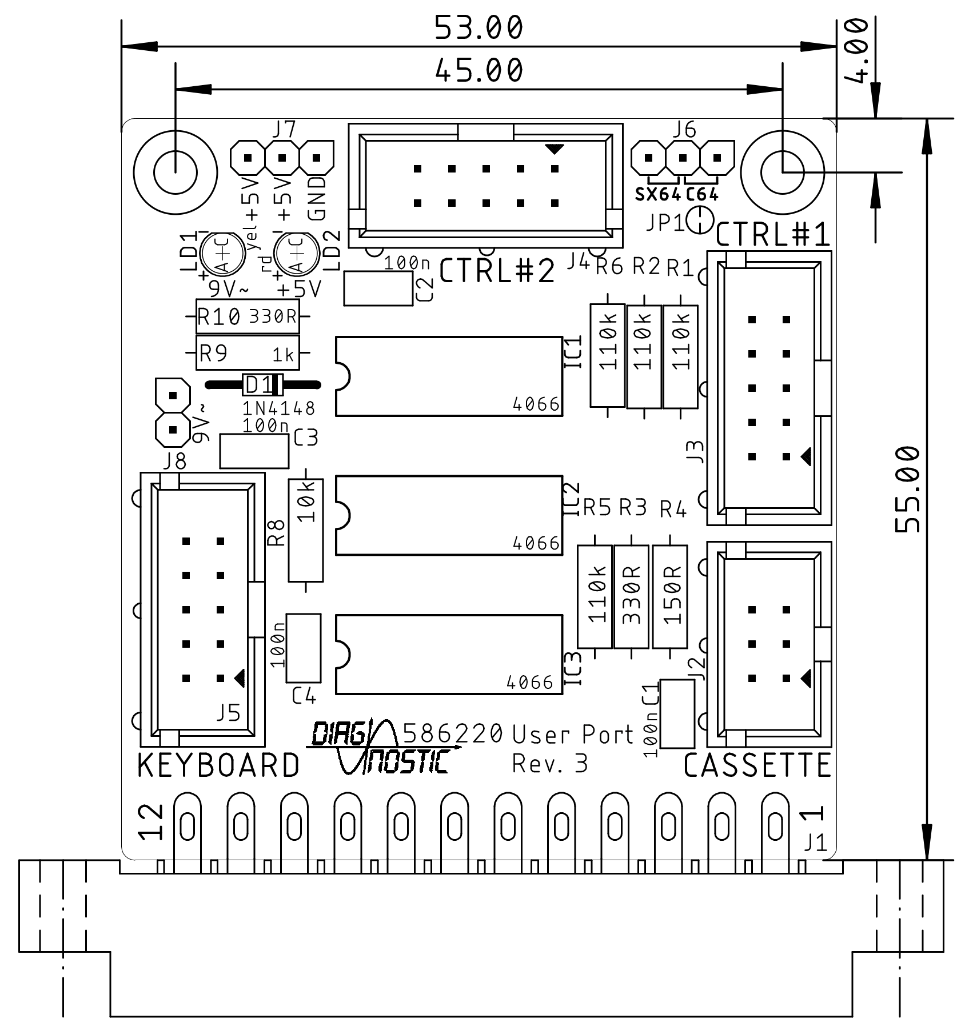
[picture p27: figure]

Figure 1: User Port PCB Rev. 3

The MOTOR output signal of the cassette port has approximately a 6V level. To use it as a control signal for operating logic devices, a voltage divider consisting out of a 150Ω resistor and a 330Ω resistor is required, which has a ratio of about 0.7.

This way, the MOTOR signal is fed back to the WRITE pin and is also used for switching the analog switches between the joystick signals of both control ports.


Figure 2: User Port Dongle Rev. 3, without and with a panel voltmeter


Figure 3: Installation of the panel voltmeter and the switch for SX/64 and C64 mode.

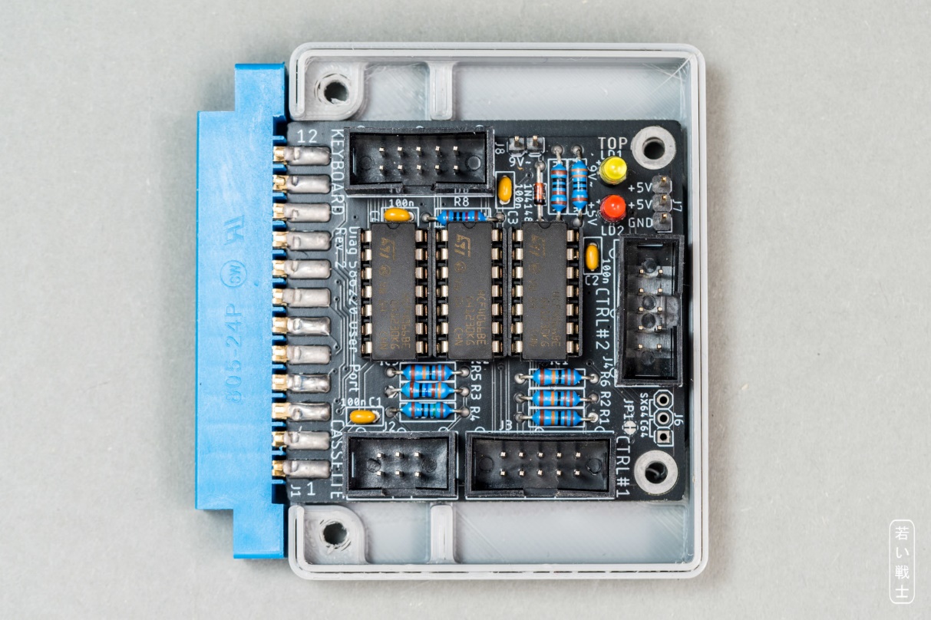
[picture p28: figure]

Figure 4: Installation without the panel voltmeter, but the pin headers for voltage measurement.

# Rev. 1

New on Rev. 1 are the analog switches for the keyboard feedbacks. This feature requires a ribbon cable to the keyboard PCB (Rev. 1). It does not connect to the Keyboard PCB Rev. 0.

The reason for this modification:

The feedbacks on keyboard dongle are identical to the feedback provided by the analog switches for the control port feedback. Since the feedbacks on the keyboard dongle are permanent, the analog switches are not effective and the control ports are not fully tested. This can lead to a false “OK”.

The new version can open the keyboard feedbacks with additional analog switches, so it is not required to remove the keyboard dongle for proper testing anymore.

# The SX-64 test feature (Rev. 2 and later)

The SX-64 does not provide a cassette port. Since the control port (and keyboard) feedbacks are switched by the cassette port MOTOR signal, J6 provides a manual switching option. It can either be jumpered or a toggle switch can be connected. Connecting J6 pin 1 and pin 2 configures the regular C64 setup (the feedbacks are controlled by MOTOR), connecting pin 3 and pin 2 configured the control port feedbacks being switched on permanently for the SX-64 option. For switching between options, the cut pad JP1 has to be opened.

By default, the C64 only mode is selected, which meansJP1 is closed. Do not connect a switch to J6 without opening JP1.

The keyboard testing of the SX-64 requires the C128 keyboard PCB and a DB female-female gender changer. For complete SX-64 testing, the diagnostic software has to be run in C64 mode (control port feedbacks off, keyboard feedbacks on) at least one pass and then in SX-64 mode (control port feedbacks on, keyboard feedbacks off).

# Rev. 3: Voltage indicators and voltmeter

The purpose of the voltmeter is measuring the +5VDC inside the C64, which does make sense. A too low voltage here might indicate a bad power switch or a bad/oxidized power jack.


Figure 5: Front and back of the 0.36" 4-digit voltmeter

Previously, three-digit and four-digit models have been tested. The three-digit models are not suitable, since they showed an error of almost 100mV. The four-digit models can be adjusted on a little potentiometer. Adjustment is required and should be performed before the assembled PCB is installed in the case.

The adjustment is best performed by measuring the voltage between the GND pin and one of the +5V pins of J7, then adjusting the reading of the voltmeter at the potentiometer on the back side. This potentiometer is shown in Figure 5: Front and back of the 0.36" 4-digit voltmeter.

Note: The panel voltmeters, that I have bought for this project were sufficiently accurate, but I would not grant for all 4 digit “precision panel meters, so the recommended configuration is to install a pin header and perform the measurement with a multimeter.

# Pinouts

## User Port

J1- Edge Connector (2x12, 3.96mm pitch)

Pin | Signal | Pin | Signal
1 | GND | A | GND
2 | +5V | B | /FLAG2
3 | /RESET | C | PB0
4 | CNT1 | D | PB1
5 | SP1 | E | PB2
6 | CNT2 | F | PB3
7 | SP2 | H | PB4
8 | /PC2 | J | PB5
9 | ATN | K | PB6
10 | 9VAC(1) | L | PB7
11 | 9VAC(2) | M | PA2
12 | GND | N | GND

## Cassette Port

J2 – 2x3 pin header for a ribbon cable connected to the cassette port PCB (project number 114).

Pin | Signal | Pin | Signal
1 | GND | 2 | n.c.
3 | MOTOR | 4 | READ
5 | WRITE | 6 | SENSE

## Control Port #1

J3 – 2x5 pin header for a ribbon cable which connects via a D-SUB 9 (female) to the control port.

Pin | D-SUB | Signal | Pin | D-SUB | Signal
1 | 1 | JOYA0 (up) | 2 | 6 | FIREA
3 | 2 | JOYA1 (down) | 4 | 7 | +5VCTR1
5 | 3 | JOYA2 (left) | 6 | 8 | n.c. (GND)
7 | 4 | JOYA3 (right) | 8 | 9 | POTXA
9 | 5 | POTYA | 10 | - | n.c.

## Control Port #2

J4 – 2x5 pin header for a ribbon cable which connects via a D-SUB 9 (female) to the control port.

Pin | D-SUB | Signal | Pin | D-SUB | Signal
1 | 1 | JOYB0 (up) | 2 | 6 | FIREB
3 | 2 | JOYB1 (down) | 4 | 7 | +5VCTR2
5 | 3 | JOYB2 (left) | 6 | 8 | n.c. (GND)
7 | 4 | JOYB3 (right) | 8 | 9 | POTXB
9 | 5 | POTYB | 10 | - | n.c.

## Keyboard

J5 – 2x5 pin header for a ribbon cable which connects to the keyboard PCB.

Pin | Signal | Pin | Signal
1 | Keyboard PB0 | 2 | Keyboard PA0
3 | Keyboard PB4 | 4 | Keyboard PA4
5 | Keyboard PB3 | 6 | Keyboard PA3
7 | Keyboard PB2 | 8 | Keyboard PA2
9 | Keyboard PB1 | 10 | Keyboard PA1

SX-64 Option

J6 – 1x3 pin header (pitch 2.54mm)

Pin | Signal
1 | WRITE
2 | WRITE*
3 | +5V

To use J 6 for switching between SX-64 and C64, cut open JP1. This is the cut pad right beside J6.

Connection pin 1-2 selects the C64 option, connecting pin 2-3 selects the SX-64 option, which switches on the control port feedbacks.

## Panelmeter Connector

J7 – 1x3 pin header, 2.54mm pitch

Pin | Signal | Voltmeter
1 | GND | -
2 | +5V | +
3 | +5V | VT

## 9VAC Connector

J8 - 1x2 pin header, 2.54mm pitch

Pin | Signal
1 | 9VAC1
2 | 9VAC2

# Interconnects

## User Port

Pin | Signal | | Signal | Pin
4 | CNT1 | « | CNT2 | 6
5 | SP1 | « | SP2 | 7
8 | /PC2 | « | /FLAG2 | B
9 | ATN | « | PA2 | M
C | PB0 | « | PB4 | H
D | PB1 | « | PB5 | J
E | PB2 | « | PB6 | K
F | PB3 | « | PB7 | L

## Cassette Port

Pin | Signal | | Signal | Pin
1 | GND | | n/c | 2
3 | MOTOR | Volt.div. | WRITE | 5
4 | READ | « | SENSE | 6

## Control Ports

Signal | | Signal
FIREA | switched by MOTOR | FIREB
JOYA0 | switched by MOTOR | JOYB0
JOYA1 | switched by MOTOR | JOYB1
JOYA2 | switched by MOTOR | JOYB2
JOYA3 | switched by MOTOR | JOYB3
POTXA | via 110kΩ (R1) | +5V (CTR 1)
POTYA | via 110kΩ (R2) | +5V (CTR 1)
POTXB | via 110kΩ (R5) | +5V (CTR 2)
POTYB | via 110kΩ (R6) | +5V (CTR 2)

The digital signals of the control ports are connected by an analog switch. A HIGH level of the MOTOR signal will switch on.

The POT (paddle) signals are tested with a fix resistor of 110k, that is connected to the +5V provided by the respective control port.

# Cables

## User Port/Cassette Port Cable

One cable as shown in Doc.-No. 113-3-01-01 is required. It connects to J2. This cable needs to be longer for C128

## User Port/Control Cables

Two cables as shown in Doc.-Nr. 113-3-02-01 are required. They connect to J3 and J4.

## User Port/Keyboard PCB Cable

One cable as shown in Doc.-No. 113-3-04-01 is required. It connects to J5 and the keyboard PCB (C64 or C128). For the C128 this cable has to be longer.

## The IEC-Dongle

The IEC-Dongle is not attached to the PCB, it is an extra built.

6p. DIN plug, connect according to Doc.-No. 113-3-03-01

Pin | Signal | | Signal | Pin
1 | SRQ | « | DATA | 5
3 | ATN | « | CLK | 4

# Block diagram of the Diagnostic Harness Rev. 3


# Connecting the Voltmeter

The Voltmeter has three connections:
+ = positive supply voltage. It is connected to J7, Pin 2 (+5V)
- = negative supply voltage. It is connected to J7, Pin 1 (GND)
VT = measured voltage. It is connected to J7, Pin 3 (+5V)

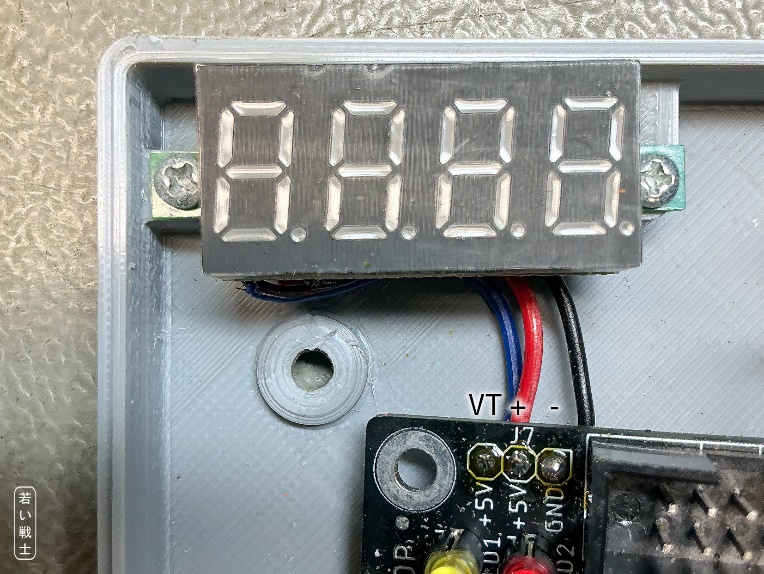
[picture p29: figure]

Figure 6: Connection of the panel voltmeter

# Revision History

## BOM v0.1 → v0.2

- Pos. 6: value 120k →110k
- Pos. 8: value 320R →316R

## Rev. 0 → Rev. 1

- This is a PCB revision
- Analog switches added (IC3)
- Pin header added (J5)
- New Ribbon Cable
- 3D printed case (Rev. 1) is required

## Rev. 1 → Rev. 2

- This is a PCB revision
- Pin header J6 and cup pad JP1 added
- It can either be installed in the Rev. 1 3D printed case, if no switch option SX64 is desired or in the User Port Case SX-64, which provides mounting holes for a toggle switch (19mm hole distance, standard switch).

## Rev. 2 → Rev. 3

- LEDs added for presence indication of +5V and 9VAC
- Connector for panel meter
- Connector for 9VAC
- New 3D printed cases.

Diag586220_User_Port_ModD.docx 27.11.2025 13:22 Drafted by Sven Petersen Page 2 of 2 Doc.-No.: 113-6-01-03

Diag586220_User_Port_ModD.docx 27.11.2025 13:22 Drafted by Sven Petersen Page 1 of 1 Doc.-No.: 113-6-01-01

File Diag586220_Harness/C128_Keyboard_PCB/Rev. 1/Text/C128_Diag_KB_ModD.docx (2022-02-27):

C128 Diagnostic – Keyboard PCB Rev. 1

Module Description

# Introduction

This is the keyboard Dongle (PCB) for the Commodore C128 Diagnostic Rev. 588121. The required harness is identical to the C64 Diagnostic Rev. 586220 harness, except the keyboard PCB. The C64 harness can be found here:

https://github.com/svenpetersen1965/C64-Diagnostic-Rev.-586220-Harness

The C128DCR does not provide +5V at the keyboard connector. Thus, this C128 keyboard dongle does not work, since the IC requires supply voltage.

A part of the keyboard scan signals are shared with the control ports. To prevent a false “OK” while testing these, the feedbacks can be opened. The required analog switches are implemented on the user port PCB (Rev. 1) of the said C64 harness. The connection to the user port PCB is provided by a ribbon cable, which can be connected to the box pin header J3.

In case this feature is not desired or the user port PCB is of an earlier revision, the adjacent pins of J3 can be jumpered with standard jumpers (1-2, 3-4, 5-6, 7-8 and 9-10).

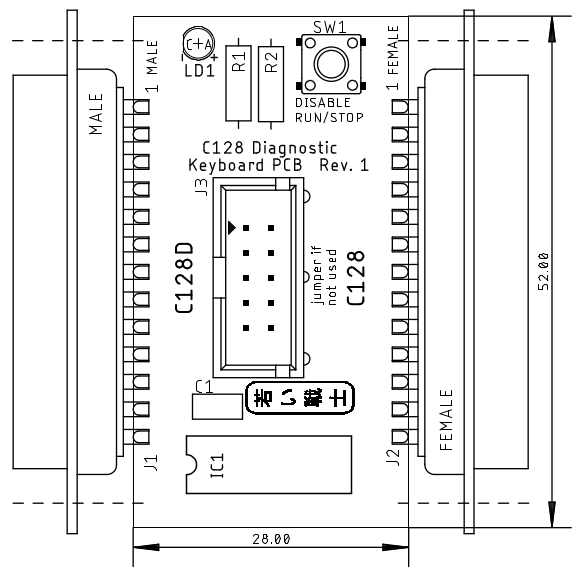
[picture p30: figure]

Figure 1: Dimensions of the C128 Diagnostic Keyboard PCB

The footprint of the keyboard connector on the C128 mainboard is for a 90° female DSub-25 connector (for the C128D). A special pin header is populated on the mainboard. It fits a female DSub-25 connector (J2). The pin numbering is in the opposite direction of a normal male DSub-25, though. This results in a discrepancy of the pin numbering of J2, which is correct.

The regular feedbacks are COL0 to ROW0, COL1 to ROW1, … COL7 to ROW7.

The feedback COL7 to ROW7 mimics a RUN/STOP while power up. This causes the C128 to boot into the monitor program, which is not desired. This can be circumvented by pressing the disable button on this PCB. This causes the analog switch (IC1) to open, which is responsible for this feedback.

# Connectors

Signal | J1 (C128D) | J2 (C128)
GND | 1 | 13
(no pin) | 2 | 12
RESTORE | 3 | 11
+5V | 4 | 10
ROW3 | 5 | 9
ROW6 | 6 | 8
ROW5 | 7 | 7
ROW4 | 8 | 6
ROW7 | 9 | 5
ROW2 | 10 | 4
ROW1 | 11 | 3
ROW0 | 12 | 2
COL0 | 13 | 1
COL6 | 14 | 25
COL5 | 15 | 24
COL4 | 16 | 23
COL3 | 17 | 22
COL2 | 18 | 21
COL1 | 19 | 20
COL7 | 20 | 19
K0 | 21 | 18
K1 | 22 | 17
K2 | 23 | 16
40/80 | 24 | 15
CAPS LOCK | 25 | 14

J3 – box pin header 2x5 circuits

Signal | Pin | Pin | Signal
COL4 | 1 | 2 | ROW4
COL3 | 3 | 4 | ROW3
COL2 | 5 | 6 | ROW2
COL1 | 7 | 8 | ROW1
COL0 | 9 | 10 | ROW0

# Links

This PCB is designed based on the following information:

- http://blog.worldofjani.com/?p=164
- http://personalpages.tds.net/~rcarlsen/cbm/c128/SCHEMATICS/
- https://commons.wikimedia.org/wiki/File:C128mobo.jpg?uselang=de

# Revision History

## Rev. 0

- Prototype

## Rev. 1

- PCB Revision: board is now 28mm wide

C128_Diag_KB_ModD.docx 27.02.2022 12:15 Drafted by Sven Petersen Page 2 of 2 Doc.-No.: 145-6-01-01

C128_Diag_KB_ModD.docx 27.02.2022 12:15 Drafted by Sven Petersen Page 1 of 1 Doc.-No.: 000-6-00-00

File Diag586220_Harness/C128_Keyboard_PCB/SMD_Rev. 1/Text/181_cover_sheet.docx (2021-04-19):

Project Documentation

C128 Diagnostic – Keyboard PCB/SMD

Project number: 181

Revision: 1

Date: 19.04.2021

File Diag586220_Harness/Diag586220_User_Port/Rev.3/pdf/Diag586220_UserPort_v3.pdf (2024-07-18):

# Project Documentation

## Diagnostic Rev. 586220 Harness - User Port

## Project number: 113

## Revision: 3

## Date: 04.03.2022

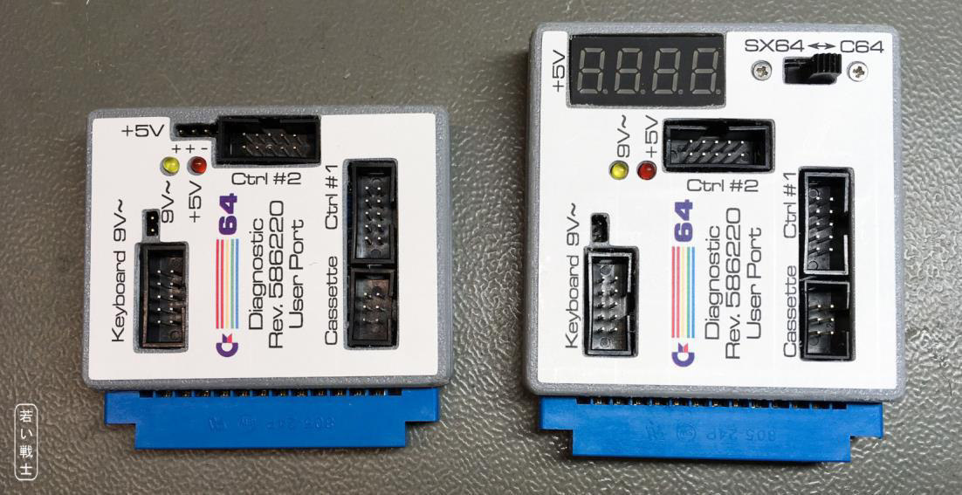
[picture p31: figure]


Diag586220_User_Port_ModD.docx | | 25.05.2024 21:12
Drafted by Sven Petersen | Page 1 of 9 | Doc.-No.: 113-6-01-03

### Diagnostic Rev. 586220 Harness - User Port Rev. 3

### Module Description

## Introduction

The User Port module is the central part of the Diagnostic Rev. 586220 harness. It provides the
required feedback connections for testing the C64’s CIA U2, which is connected to the user
port. It also holds the analog switches, which are required to test the Control Ports and the feedback connections for testing the cassette port.

Figure 1: User Port PCB Rev. 3

The MOTOR output signal of the cassette port has approximately a 6V level. To use it as a
control signal for operating logic devices, a voltage divider consisting out of a 150Ω resistor
and a 330Ω resistor is required, which has a ratio of about 0.7.

This way, the MOTOR signal is fed back to the WRITE pin and is also used for switching the analog switches between the joystick signals of both control ports.

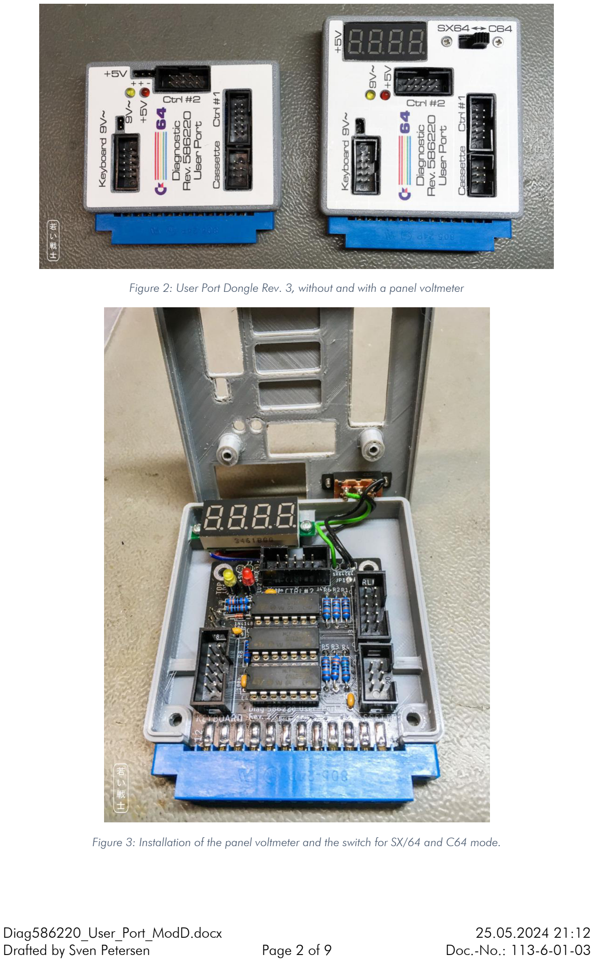
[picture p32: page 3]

Diag586220_User_Port_ModD.docx | | 25.05.2024 21:12
Drafted by Sven Petersen | Page 2 of 9 | Doc.-No.: 113-6-01-03

Figure 2: User Port Dongle Rev. 3, without and with a panel voltmeter

Figure 3: Installation of the panel voltmeter and the switch for SX/64 and C64 mode.

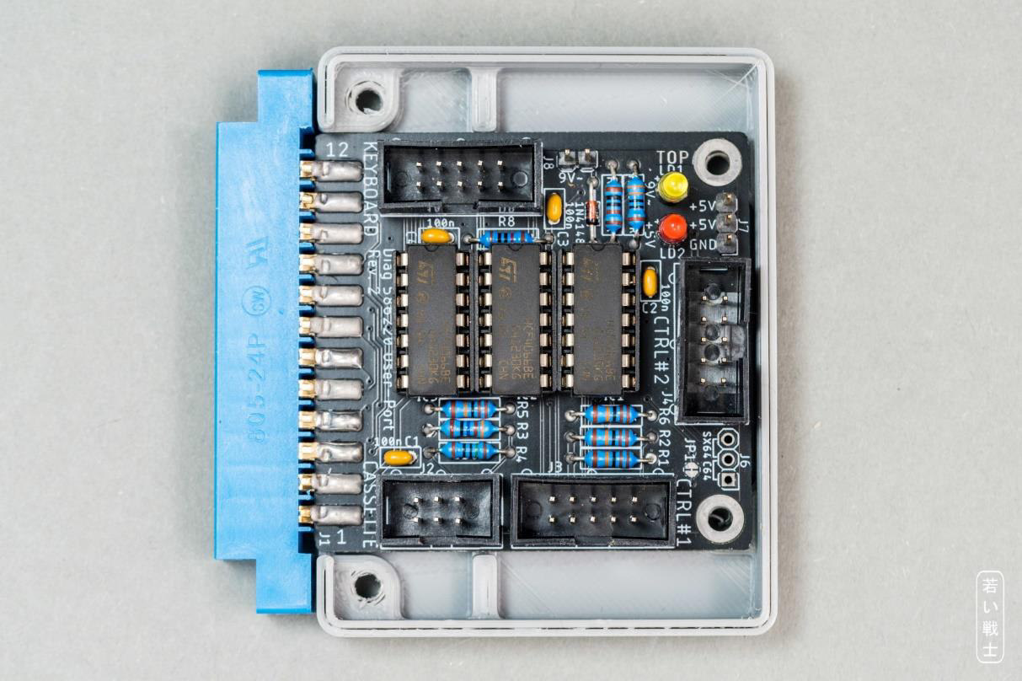
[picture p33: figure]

Diag586220_User_Port_ModD.docx | | 25.05.2024 21:12
Drafted by Sven Petersen | Page 3 of 9 | Doc.-No.: 113-6-01-03

Figure 4: Installation without the panel voltmeter, but the pin headers for voltage measurement.

## Rev. 1

New on Rev. 1 are the analog switches for the keyboard feedbacks. This feature requires a ribbon cable to the keyboard PCB (Rev. 1). It does not connect to the Keyboard PCB Rev. 0.

The reason for this modification:

The feedbacks on keyboard dongle are identical to the feedback provided by the analog switches for the control port feedback. Since the feedbacks on the keyboard dongle are permanent, the analog switches are not effective and the control ports are not fully tested. This
can lead to a false “OK”.

The new version can open the keyboard feedbacks with additional analog switches, so it is not required to remove the keyboard dongle for proper testing anymore.

## The SX-64 test feature (Rev. 2 and later)

The SX-64 does not provide a cassette port. Since the control port (and keyboard) feedbacks are switched by the cassette port MOTOR signal, J6 provides a manual switching option. It can either be jumpered or a toggle switch can be connected. Connecting J6 pin 1 and pin 2 configures the regular C64 setup (the feedbacks are controlled by MOTOR), connecting pin 3 and pin 2 configured the control port feedbacks being switched on permanently for the SX-64 option. For switching between options, the cut pad JP1 has to be opened.

By default, the C64 only mode is selected, which meansJP1 is closed. Do not connect a switch to J6 without opening JP1.

The keyboard testing of the SX-64 requires the C128 keyboard PCB and a DB female-female gender changer. For complete SX-64 testing, the diagnostic software has to be run in C64 mode (control port feedbacks off, keyboard feedbacks on) at least one pass and then in SX-64 mode (control port feedbacks on, keyboard feedbacks off).

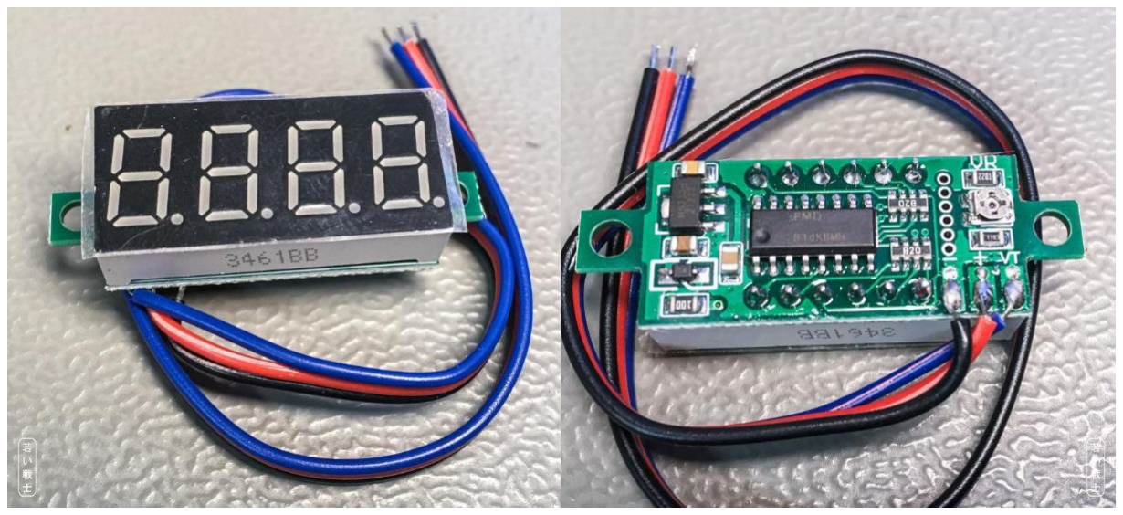
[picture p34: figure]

Diag586220_User_Port_ModD.docx | | 25.05.2024 21:12
Drafted by Sven Petersen | Page 4 of 9 | Doc.-No.: 113-6-01-03

## Rev. 3: Voltage indicators and voltmeter

The purpose of the voltmeter is measuring the +5VDC inside the C64, which does make sense. A too low voltage here might indicate a bad power switch or a bad/oxidized power jack.

Figure 5: Front and back of the 0.36" 4-digit voltmeter

Previously, three-digit and four-digit models have been tested. The three-digit models are not suitable, since they showed an error of almost 100mV. The four-digit models can be adjusted on a little potentiometer. Adjustment is required and should be performed before the assembled PCB is installed in the case.

The adjustment is best performed by measuring the voltage between the GND pin and one of the +5V pins of J7, then adjusting the reading of the voltmeter at the potentiometer on the back side. This potentiometer is shown in Figure 5: Front and back of the 0.36" 4-digit voltmeter.

Note: The panel voltmeters, that I have bought for this project were sufficiently accurate, but I
would not grant for all 4 digit “precision panel meters, so the recommended configuration is to
install a pin header and perform the measurement with a multimeter.

## Pinouts

### User Port

J1- Edge Connector (2x12, 3.96mm pitch)

Pin Signal | Pin Signal
1 | GND | A | GND
2 | +5V | B | /FLAG2
3 | /RESET | C | PB0
4 | CNT1 | D | PB1
5 | SP1 | E | PB2
6 | CNT2 | F | PB3
7 | SP2 | H | PB4
8 | /PC2 | J | PB5
9 | ATN | K | PB6
10 | 9VAC(1) | L | PB7
11 | 9VAC(2) | M | PA2
12 | GND | N | GND

Diag586220_User_Port_ModD.docx | | 25.05.2024 21:12
Drafted by Sven Petersen | Page 5 of 9 | Doc.-No.: 113-6-01-03

### Cassette Port

J2 – 2x3 pin header for a ribbon cable connected to the cassette port PCB (project number 114).

Pin Signal | Pin Signal
1 | GND | 2 | n.c.
3 | MOTOR | 4 | READ
5 | WRITE | 6 | SENSE

### Control Port #1

J3 – 2x5 pin header for a ribbon cable which connects via a D-SUB 9 (female) to the control port.

Pin D-SUB Signal | Pin D-SUB Signal
1 | 1 | JOYA0 (up) | 2 | 6 | FIREA
3 | 2 | JOYA1 (down) | 4 | 7 | +5VCTR1
5 | 3 | JOYA2 (left) | 6 | 8 | n.c. (GND)
7 | 4 | JOYA3 (right) | 8 | 9 | POTXA
9 | 5 | POTYA | 10 | - | n.c.

### Control Port #2

J4 – 2x5 pin header for a ribbon cable which connects via a D-SUB 9 (female) to the control port.

Pin D-SUB Signal | Pin D-SUB Signal
1 | 1 | JOYB0 (up) | 2 | 6 | FIREB
3 | 2 | JOYB1 (down) | 4 | 7 | +5VCTR2
5 | 3 | JOYB2 (left) | 6 | 8 | n.c. (GND)
7 | 4 | JOYB3 (right) | 8 | 9 | POTXB
9 | 5 | POTYB | 10 | - | n.c.

### Keyboard

J5 – 2x5 pin header for a ribbon cable which connects to the keyboard PCB.

Pin Signal | Pin Signal
1 | Keyboard PB0 | 2 | Keyboard PA0
3 | Keyboard PB4 | 4 | Keyboard PA4
5 | Keyboard PB3 | 6 | Keyboard PA3
7 | Keyboard PB2 | 8 | Keyboard PA2
9 | Keyboard PB1 | 10 | Keyboard PA1

SX-64 Option

J6 – 1x3 pin header (pitch 2.54mm)

Pin Signal
1 WRITE
2 WRITE*
3 +5V

To use J 6 for switching between SX-64 and C64, cut open JP1. This is the cut pad right beside J6.

Diag586220_User_Port_ModD.docx | | 25.05.2024 21:12
Drafted by Sven Petersen | Page 6 of 9 | Doc.-No.: 113-6-01-03

Connection pin 1-2 selects the C64 option, connecting pin 2-3 selects the SX-64 option, which switches on the control port feedbacks.

### Panelmeter Connector

J7 – 1x3 pin header, 2.54mm pitch

Pin Signal
1 GND
2 +5V
3 +5V

### 9VAC Connector

J8 - 1x2 pin header, 2.54mm pitch

Pin Signal
1 9VAC1
2 9VAC2

## Interconnects

### User Port

Pin | Signal | Signal | Pin
4 | CNT1 | « | CNT2 | 6
5 | SP1 | « | SP2 | 7
8 | /PC2 | « | /FLAG2 | B
9 | ATN | « | PA2 | M
C | PB0 | « | PB4 | H
D | PB1 | « | PB5 | J
E | PB2 | « | PB6 | K
F | PB3 | « | PB7 | L

### Cassette Port

Pin | Signal | Signal Pin
1 | GND | | n/c | 2
3 | MOTOR | Volt.div. | WRITE | 5
4 | READ | « | SENSE | 6

### Control Ports

Signal | Signal
FIREA | switched by MOTOR | FIREB
JOYA0 | switched by MOTOR | JOYB0
JOYA1 | switched by MOTOR | JOYB1
JOYA2 | switched by MOTOR | JOYB2
JOYA3 | switched by MOTOR | JOYB3
POTXA | via 110kΩ (R1) | +5V (CTR 1)
POTYA | via 110kΩ (R2) | +5V (CTR 1)
POTXB | via 110kΩ (R5) | +5V (CTR 2)
POTYB | via 110kΩ (R6) | +5V (CTR 2)

Diag586220_User_Port_ModD.docx | | 25.05.2024 21:12
Drafted by Sven Petersen | Page 7 of 9 | Doc.-No.: 113-6-01-03

The digital signals of the control ports are connected by an analog switch. A HIGH level of the MOTOR signal will switch on.

The POT (paddle) signals are tested with a fix resistor of 110k, that is connected to the +5V provided by the respective control port.

## Cables

### User Port/Cassette Port Cable

One cable as shown in Doc.-No. 113-3-01-01 is required. It connects to J2. This cable needs to be longer for C128

### User Port/Control Cables

Two cables as shown in Doc.-Nr. 113-3-02-01 are required. They connect to J3 and J4.

### User Port/Keyboard PCB Cable

One cable as shown in Doc.-No. 113-3-04-01 is required. It connects to J5 and the keyboard PCB (C64 or C128). For the C128 this cable has to be longer.

### The IEC-Dongle

The IEC-Dongle is not attached to the PCB, it is an extra built.

6p. DIN plug, connect according to Doc.-No. 113-3-03-01

Pin | Signal | Signal Pin
1 | SRQ | « | DATA | 5
3 | ATN | « | CLK | 4

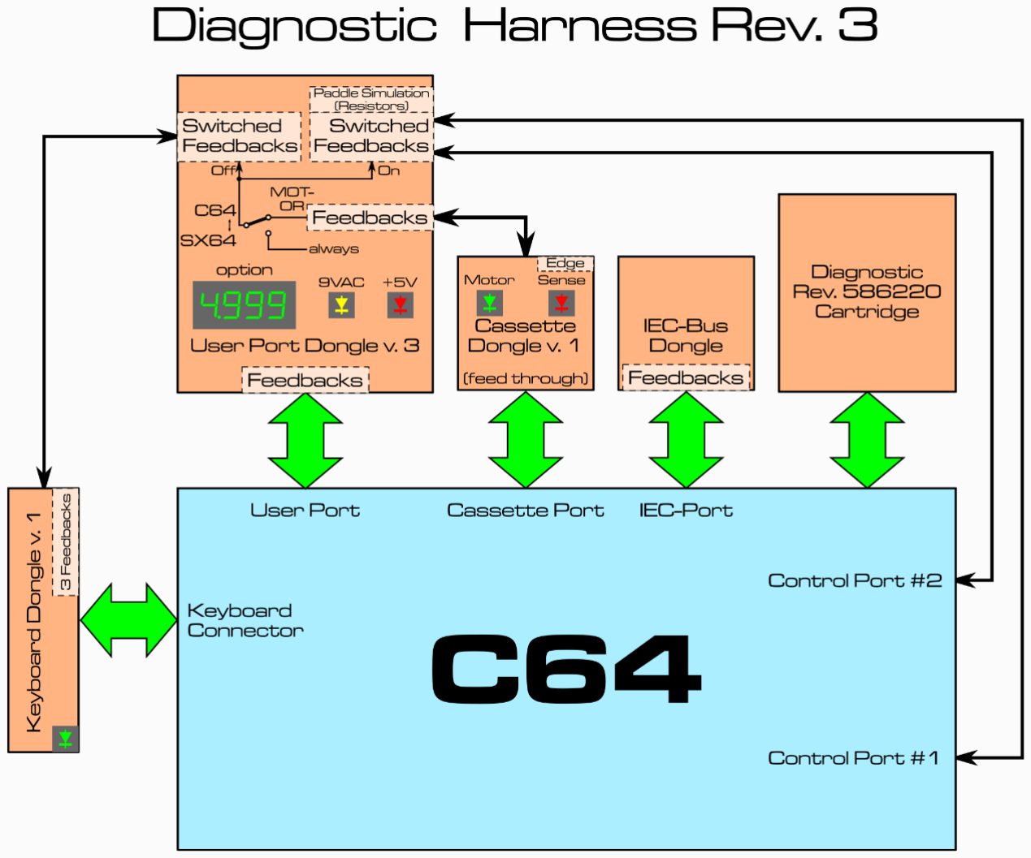
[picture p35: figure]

Diag586220_User_Port_ModD.docx | | 25.05.2024 21:12
Drafted by Sven Petersen | Page 8 of 9 | Doc.-No.: 113-6-01-03

## Block diagram of the Diagnostic Harness Rev. 3

Diag586220_User_Port_ModD.docx | | 25.05.2024 21:12
Drafted by Sven Petersen | Page 9 of 9 | Doc.-No.: 113-6-01-03

## Revision History

### BOM v0.1 → v0.2

- Pos. 6: value 120k →110k
- Pos. 8: value 320R →316R

### Rev. 0 → Rev. 1

- This is a PCB revision
- Analog switches added (IC3)
- Pin header added (J5)
- New Ribbon Cable
- 3D printed case (Rev. 1) is required

### Rev. 1 → Rev. 2

- This is a PCB revision
- Pin header J6 and cup pad JP1 added
- It can either be installed in the Rev. 1 3D printed case, if no switch option SX64 is desired or in the User Port Case SX-64, which provides mounting holes for a toggle switch (19mm hole distance, standard switch).

### Rev. 2 → Rev. 3

- LEDs added for presence indication of +5V and 9VAC
- Connector for panel meter
- Connector for 9VAC
- New 3D printed cases.

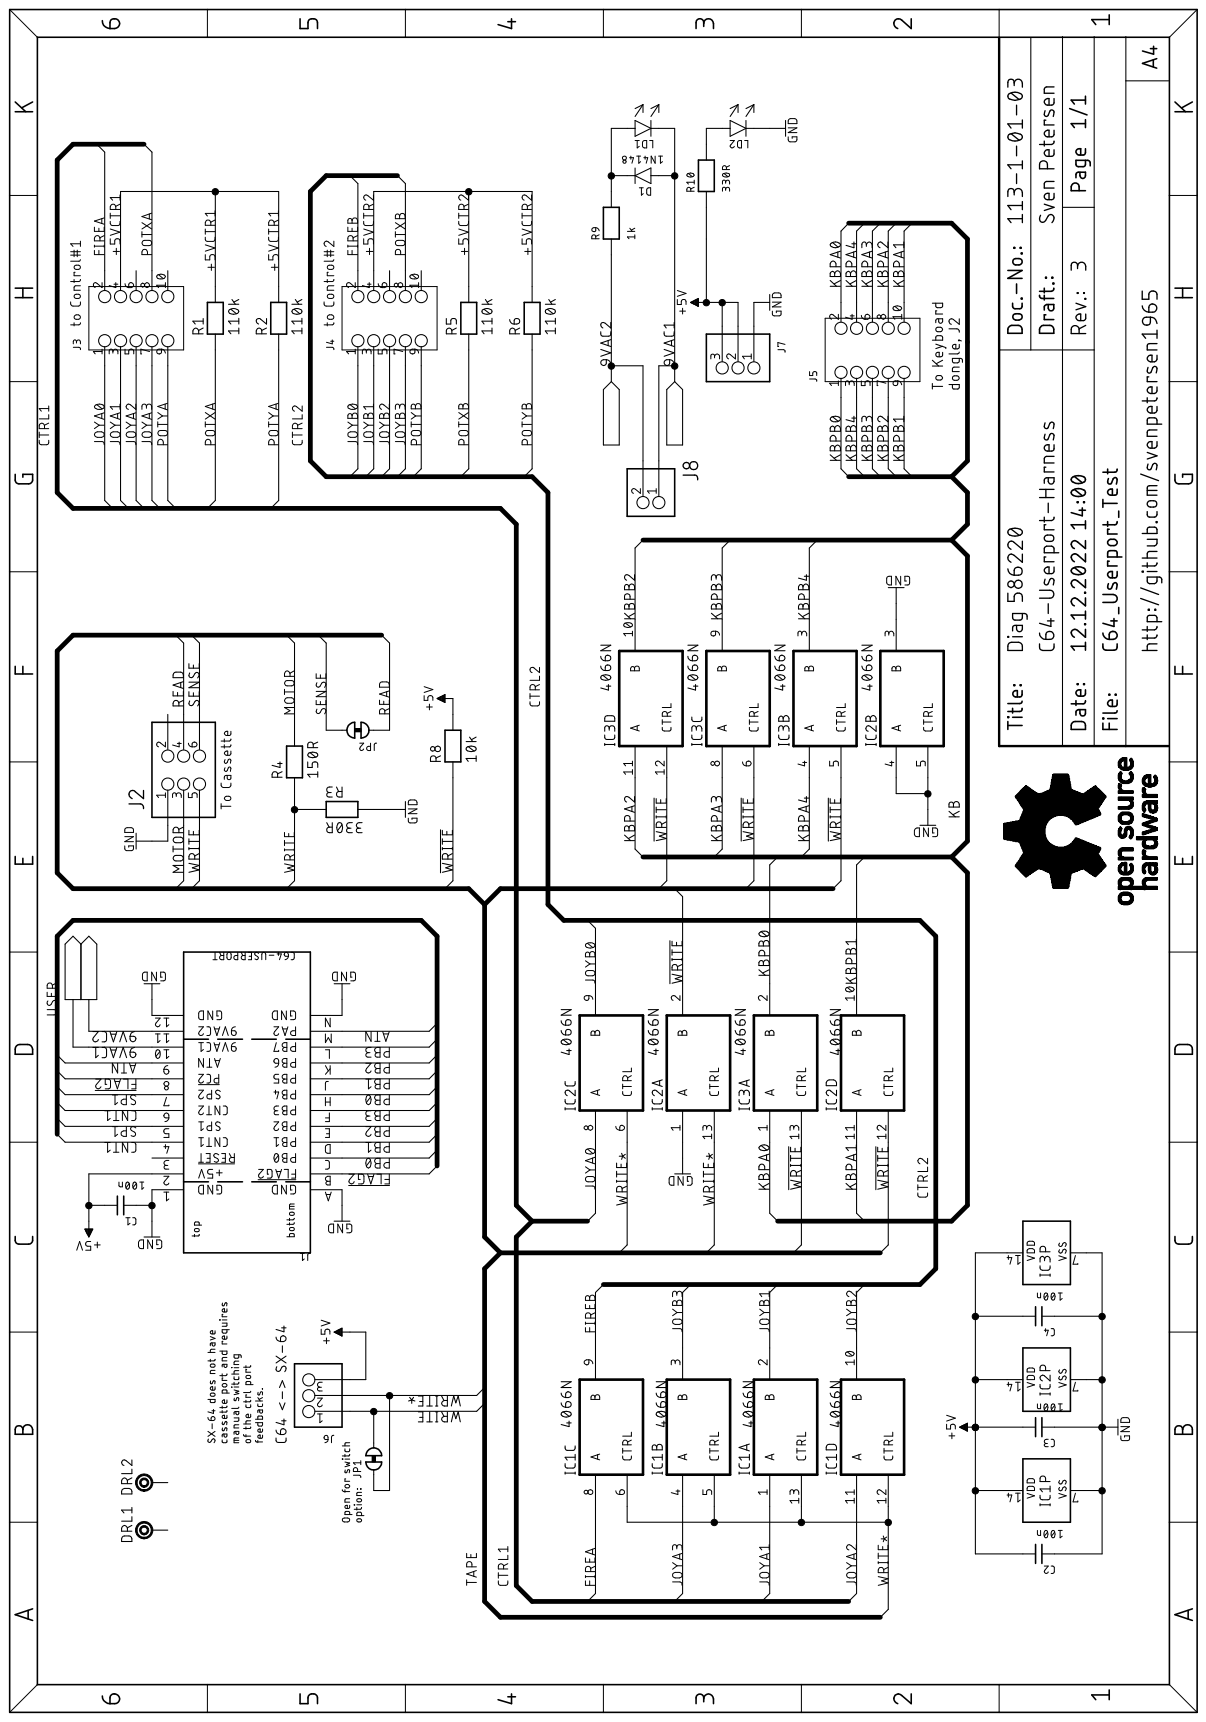
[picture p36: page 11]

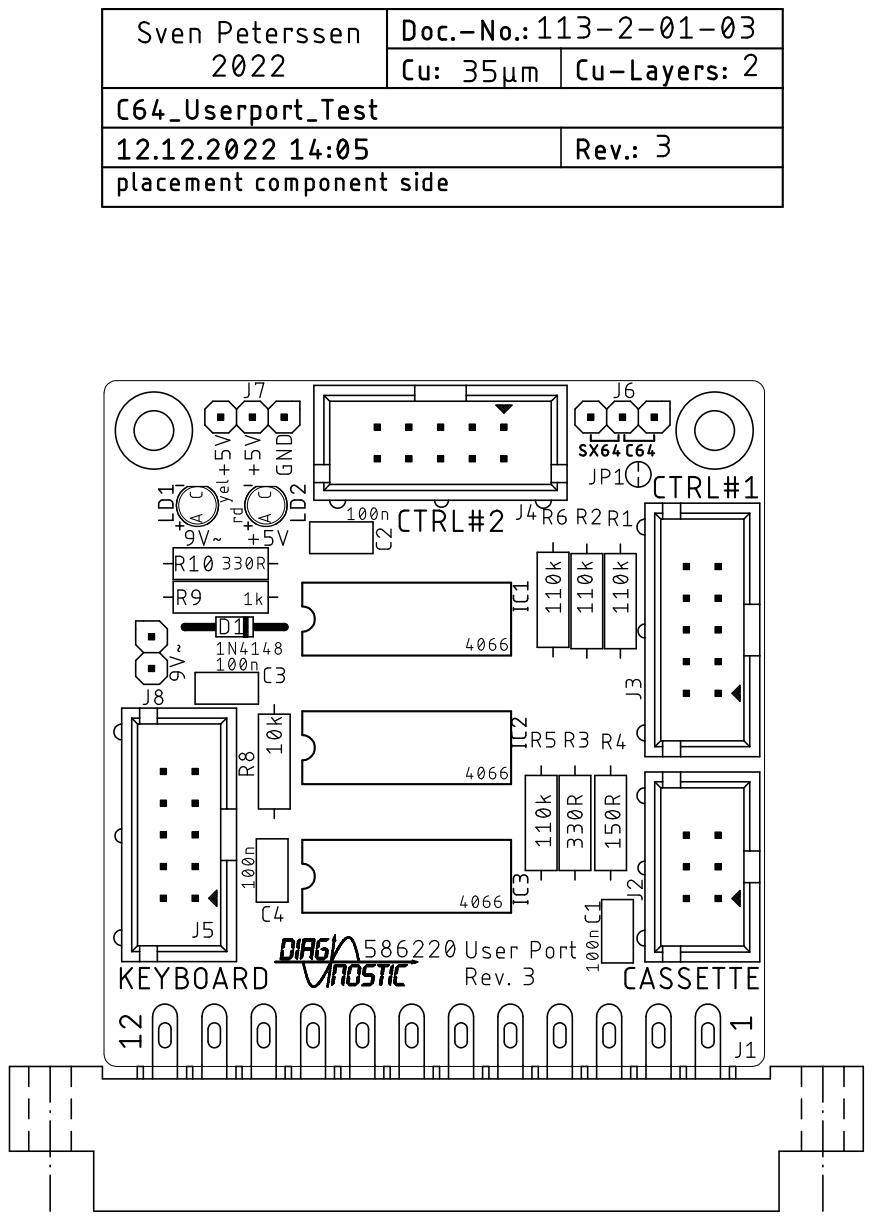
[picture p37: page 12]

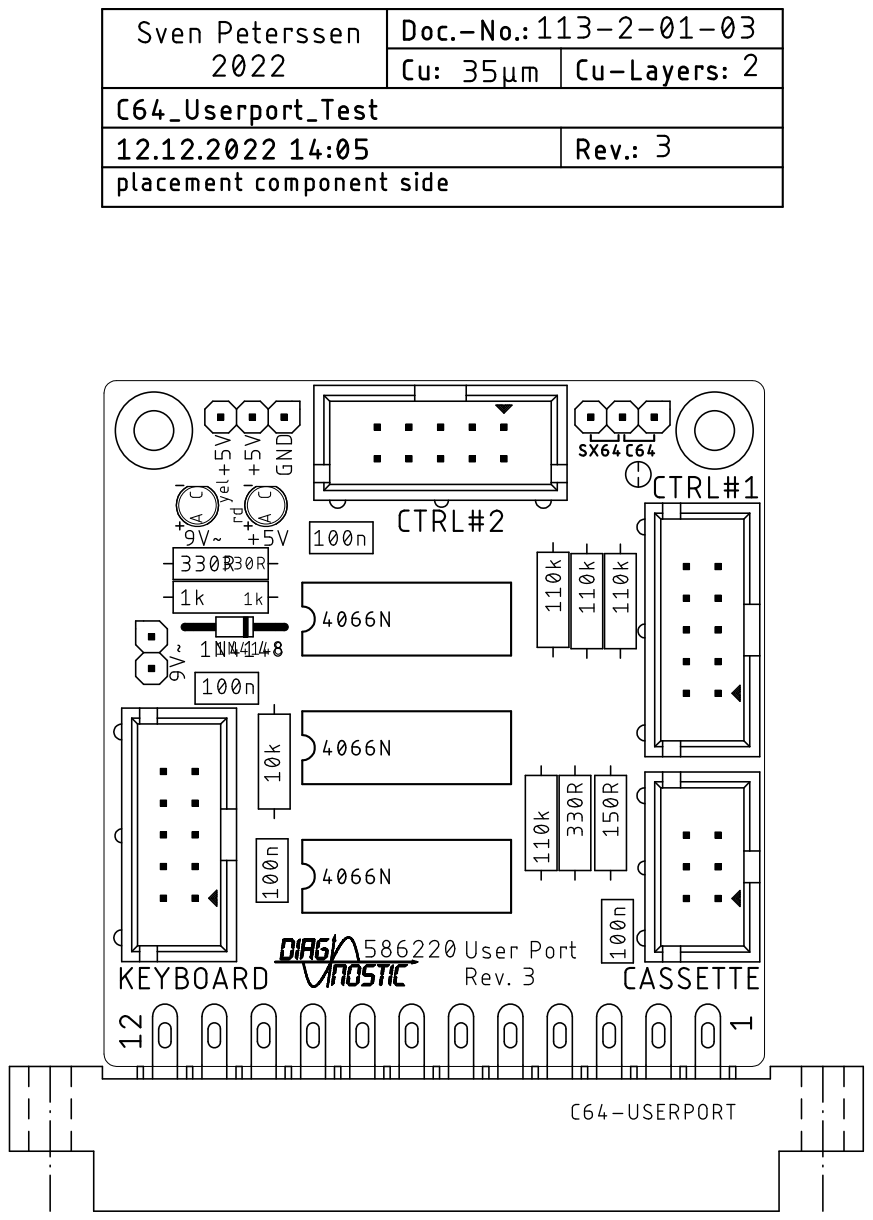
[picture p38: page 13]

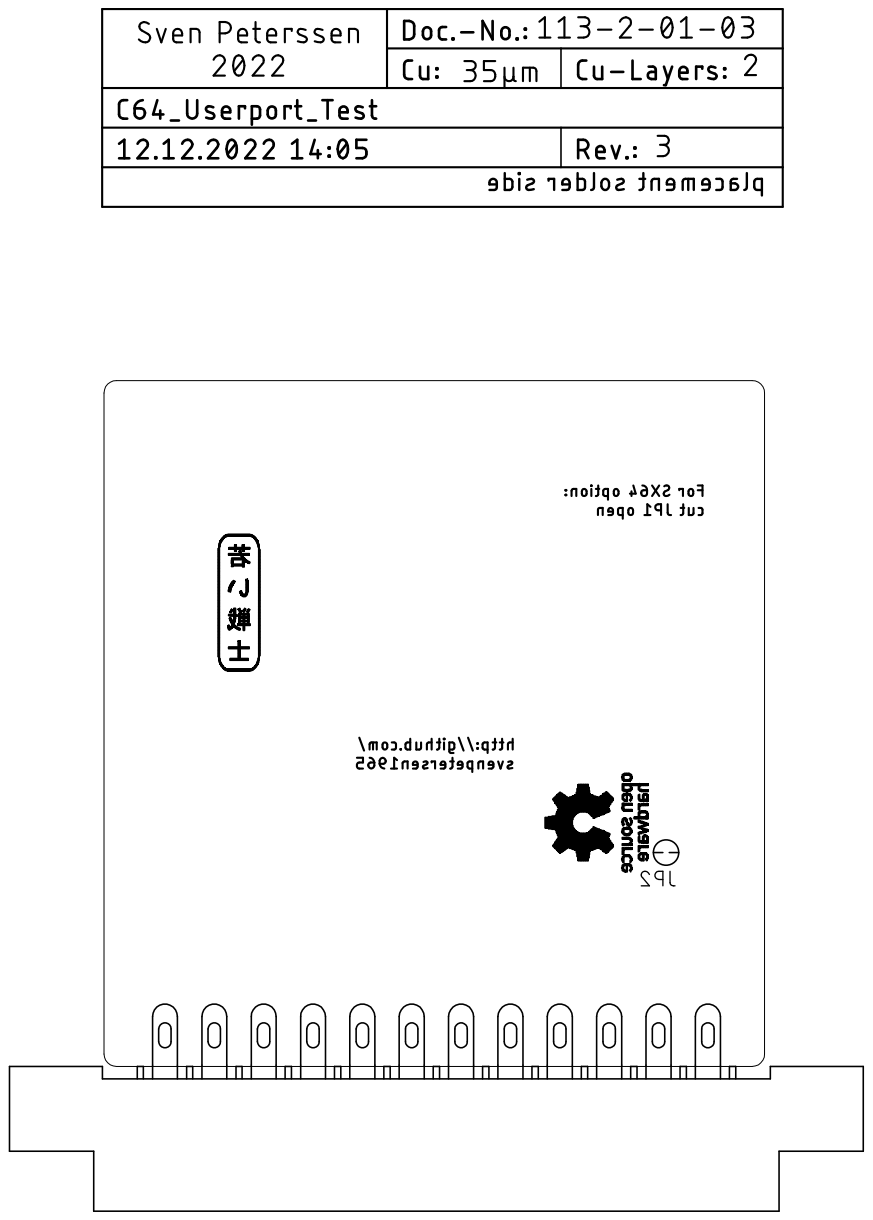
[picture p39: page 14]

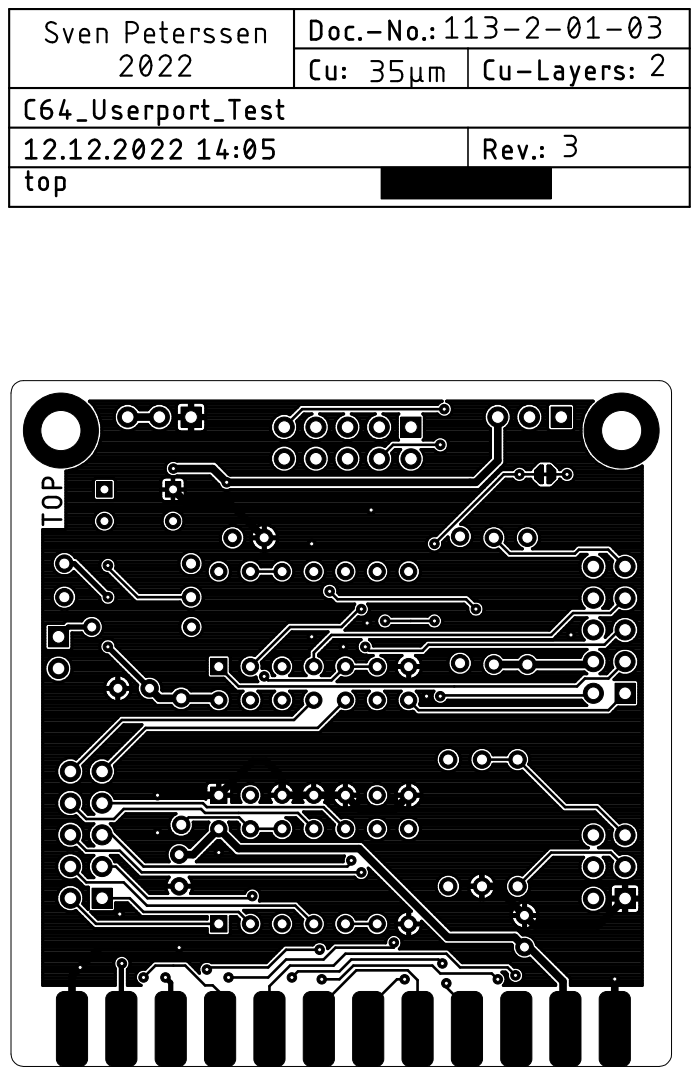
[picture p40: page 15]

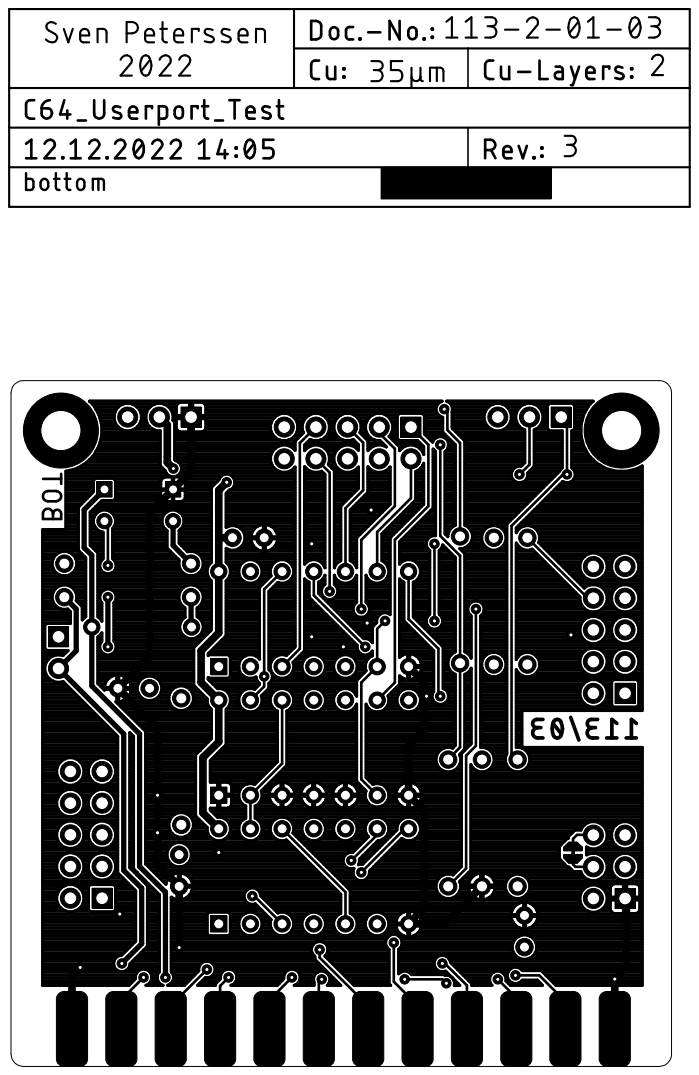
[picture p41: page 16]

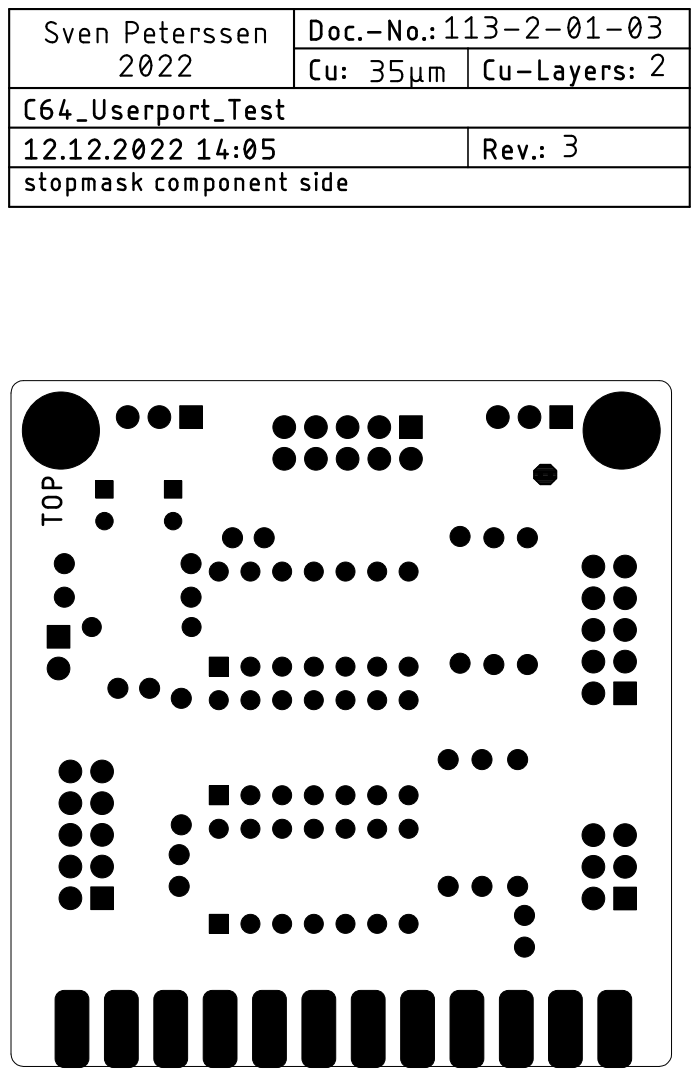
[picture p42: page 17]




Diag586220_User_Port_Test.docx | | 25.05.2024 22:11
Drafted by Sven Petersen | Page 1 of 2 | Doc.-No.: 113-6-02-03

### Diagnostic Rev. 586220 Harness - User Port Rev. 3

### Testing

This document describes the testing procedure of the complete Rev. 1 diagnostic harness. A Rev. 0/1/2/3 Harness was connected to a known working C64 (ASSY250469). The dongles were introduced one by one.

Figure 1: Harness Rev. 1 while being tested

First, the keyboard dongle Rev. 1 was connected, J2 was bridged with jumpers (the feedback connections were made permanent this way).

The Diagnostic Rev. 586220 cartridge was installed and the diagnostic test was run. It was
completed successfully, all components were reported “OK”.

Next was the Cassette Dongle Rev. 1 being connected for the test. The diagnostic test was

### passed, all components were reported “OK”. The SENSE LED changed the status several times

while the test, the MOTOR LED was off and only switched on for the cassette port test and the control port test.

The User Port Dongle Rev. 1 was then connected and a ribbon cable between J5 and the
keyboard dongle Rev. 1. The diagnostic test was passed, all components were reported “OK”.

To simulate a failing control port connection, IC1 was extracted from the socket. The diagnostic
test reported the control ports “BAD”. IC1 was installed again.

To simulate a failing keyboard connection, the ribbon cable to the keyboard dongle was
removed. The diagnostic test reported the keyboard “BAD”.

The keyboard dongle was removed from the setup completely. The diagnostic test reported the
keyboard “OPEN”.

Diag586220_User_Port_Test.docx | | 25.05.2024 22:11
Drafted by Sven Petersen | Page 2 of 2 | Doc.-No.: 113-6-02-03

The test harness was completely removed, except the Cassette Dongle. The Diagnostic Cartridge was disconnected from the C64. A Datassette with a tape was connected to the Cassette Dongle. The purpose of this test is to prove the breakout board properties of the Cassette Dongle.

The software on the tape could be loaded successfully.

A short program was written to (another) tape. It could be verified successfully.

Conclusion:

- The Diagnostic Harness Rev. 1 is fully functional.
- Rev. 2 is fully functional
- Rev. 3 is tested and working.

File:; Titel:; Doc.-No.: 113-3-01-01; Date: 08.06.2020 13:05; Diagnostic 586220; Harness; Rev.: 1; Port Cable; e.g. Reichelt RND 205-00680

Draft.: Sven Petersen

UP-CASP.SKF

User Port - Cassette

11 cm Ribbon cable 6p, AWG28, 1,27mm pitch

For C128 diagnostics: 250mm ribbon cable required.

IDC Ribbon Cable Socket 6P

File:; Titel:; Doc.-No.: 113-3-02-01; Date: 08.06.2020 13:08; Diagnostic 586220; Harness; Rev.: 1; e.g. Reichelt RND 205-00682; The 10th wire; here.

1 UP-CTRLP.SKF

Draft.: Sven Petersen

D-SUB-jack, 9p f. ribbon cable

e.g. Reichelt D-SUB BU 09FB

User Port - Control

Port Cable 1 1 64cm Ribbon cable 10p, AWG28, 1,27mm pitch

is clipped off

IDC Ribbon Cable Socket 10P

File:; Titel:; Doc.-No.: 113-3-03-00; Date: 01.03.2019 18:15; Diagnostic 586220; Harness; Rev.: 0; 1 IEC.SKF; IEC-Dongle; 1 (SRQ) 5 (DATA); 3 (ATN); 4 (CLK); side.

Draft.: Sven Petersen

Assembled IEC-Dongle

6p DIN plug, e.g. Reichelt MAS 60

shown from the solder

The open DIN plug,

e.g. Reichelt RND 205-00682; PCB Cable; File:; Titel:; Doc.-No.: 113-3-04-01; Date: 08.06.2020 13:06; Diagnostic 586220; Harness; Rev.: 1

Draft.: Sven Petersen

UP-KEYB.SKF

IDC Ribbon Cable Socket 10P

User Port - Keyboard

43cm Ribbon cable 10p, AWG28, 1,27mm pitch

For C128 Diagnostics: 76cm ribbon cable required

(beside the C128 Keyboard PCB)

Pos. Qty Value Footprint Ref.-No. Comment

1 1 113-2-01-03 2 Layer PCB Rev. 3 2 layer, Cu 35µ, HASL, LLL x BBB, 1.6mm FR4

2 1 2x3 box connector 2X03WV J2 e.g. Reichelt WSL 6G

3 3 2x5 box connector 2X05WV J3, J4, J5 e.g. Reichelt WSL 10G

4 0 0R R-10 R7 removed in Rev. 3

5 4 100n/50V C-2,5 C1, C2, C3, C4 cer. cap, 2.5mm pitch

6 4 110k R-10 R1, R2, R5, R6 1/4W, 1%
7 1 150R R-10 R4 1/4W, 5%

8 1 330R R-10 R3 1/4W, 5%

9 3 HCF4066B DIL14 IC1, IC2, IC3 ST Micro or equivalent

10 3 DIL 14 DIL14 (IC1), (IC2), (IC3) DIL IC sockets

11 1 2x12, 3.96mm pitch USERPORT J1 edge connector, C64 user port

12 1 TP 1pin 1,2MM_R TP1 optional, Pin Header, e.g. Reichelt RND 205-00622

13 182cm 10p/AWG28/1,27mm Doc-No. 113-3-02-01,

Doc.-No. 113-3-01-01,
Doc.-No. 113-3-04-01

Ribbon Cable

14 2 6p IDC receptacle,

2,54mm

Doc.-No. 113-2-01-01 e.g. Reichelt RND 205-00680

15 4 10p IDC receptacle,

2,54mm

Doc.-No. 113-3-02-01,
Doc.-No. 113-3-04-01

e.g. Reichelt RND 205-00682
16 2 9p D-SUB (female), IDC Doc.-No. 113-3-02-01 e.g. Reichelt D-SUB BU 09FB

17 1 DIN-plug 6p Doc.-No. 113-3-03-01 e.g. Reichelt MAS 60
18 4cm Wire 0,25mm², red Doc.-No. 113-3-03-01 wire, color what ever

19 1 10k R-10 R8 1/4W, 5%

20 1 3x1pin, 2.54mm J6 optional pin header, 2.54mm pitch

21 1 jumper, 2.54mm (J6) option. Toggle Switch can be connected alternatively

22 1 cut pad JP1 not part, it is on the PCB. Closed by default for C64. For

switching, cut open

23 1 1x3p., 2.54mm 1x03 J7 solderpads for voltmeter (see discription)

24 1 1x2p., 2.54mm 1x02 J8 do not place (see discription)

## Diagnostic Rev. 586220 Harness - User Port Rev. 3

## Bill of Material Rev. 3.0

Diag586220_UserPort_BOM_v3_0.xlsx

Drafted by Sven Petersen Page 1 of 3

18.07.2024 21:07
Doc.No.: 113-5-01-03.0

Pos. Qty Value Footprint Ref.-No. Comment

## Diagnostic Rev. 586220 Harness - User Port Rev. 3

## Bill of Material Rev. 3.0

25 2 3mm, green LED 3mm LD1, LD2 standard LED

26 1 1N4148 DO-35 D1 diode

27 1 1k R-10 R9 1/4W, 5%

28 1 330R R-10 R10 1/4W, 5%

### Rev. 0.1 → 0.2

Pos 6 now 110k

### 8 now 316R

### Rev. 0.2 → 1.0

Pos. 1 Board Revision

Pos. 3 J5 is new

Pos. 5 C4 is new

Pos. 9 IC3 is new
Pos. 10 IC3 is new

Pos. 12 TP2 and TP3 removed

Pos. 13 additional length

Pos. 15 2 more for additional cable

Pos. 19 R8 is new

### Rev. 1.0 → 2.0

Pos. 1 PCB revision

Pos. 20 new

Pos. 21 new

Pos. 22 new

Diag586220_UserPort_BOM_v3_0.xlsx

Drafted by Sven Petersen Page 2 of 3

18.07.2024 21:07
Doc.No.: 113-5-01-03.0

Pos. Qty Value Footprint Ref.-No. Comment

## Diagnostic Rev. 586220 Harness - User Port Rev. 3

## Bill of Material Rev. 3.0

### Rev. 2.0 → 3.0

Pos. 1 PCB Rev. 3

Pos. 4 0R resistor R7 removed

Pos. 23 new

Pos. 24 new

Pos. 25 new

Pos. 26 new

Pos. 27 new

Pos. 28 new

Diag586220_UserPort_BOM_v3_0.xlsx

Drafted by Sven Petersen Page 3 of 3

18.07.2024 21:07
Doc.No.: 113-5-01-03.0

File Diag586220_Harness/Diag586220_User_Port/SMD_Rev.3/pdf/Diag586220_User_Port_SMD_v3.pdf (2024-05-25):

# Project Documentation

## Diagnostic Rev. 586220 Harness - User Port (SMD)

## Project number: 179

## Revision: 3

## Date: 08.06.2023



Diag586220_User_Port_ModD.docx | | 25.05.2024 22:55
Drafted by Sven Petersen | Page 1 of 9 | Doc.-No.: 179-6-01-03

### Diagnostic Rev. 586220 Harness - User Port SMD Rev. 3

### Module Description

The User Port module is the central part of the Diagnostic Rev. 586220 harness. It provides

### the required feedback connections for testing the C64’s CIA U2, which is connected to the

user port. It also holds the analog switches, which are required to test the Control Ports and the feedback connections for testing the cassette port.

Figure 1: User Port SMD PCB Rev. 3

The MOTOR output signal of the cassette port has approximately a 6V level. To use it as a
control signal for operating logic devices, a voltage divider consisting out of a 150Ω resistor
and a 320Ω (316Ω works here, 330Ω should work as well) resistor is required, which has a ratio of about 0.7.

This way, the MOTOR signal is fed back to the WRITE pin and is also used for switching the analog switches between the joystick signals of both control ports.


Diag586220_User_Port_ModD.docx | | 25.05.2024 22:55
Drafted by Sven Petersen | Page 2 of 9 | Doc.-No.: 179-6-01-03

Figure 2: User Port Dongle Rev. 3, without and with a panel voltmeter

Figure 3: Installation of the panel voltmeter and the switch for SX/64 and C64 mode (THT Board)


Diag586220_User_Port_ModD.docx | | 25.05.2024 22:55
Drafted by Sven Petersen | Page 3 of 9 | Doc.-No.: 179-6-01-03

Figure 4: Installation without the panel voltmeter, but the pin headers for voltage measurement.

## Rev. 1

New on Rev. 1 are the analog switches for the keyboard feedbacks. This feature requires a ribbon cable to the keyboard PCB (Rev. 1). It does not connect to the Keyboard PCB Rev. 0.

The reason for this modification:

The feedbacks on keyboard dongle are identical to the feedback provided by the analog switches for the control port feedback. Since the feedbacks on the keyboard dongle are permanent, the analog switches are not effective and the control ports are not fully tested.
This can lead to a false “OK”.

The new version can open the keyboard feedbacks with additional analog switches, so it is not required to remove the keyboard dongle for proper testing anymore.

## The SX-64 test feature (Rev. 2 and later)

The SX-64 does not provide a cassette port. Since the control port (and keyboard) feedbacks are switched by the cassette port MOTOR signal, J6 provides a manual switching option. It can either be jumpered or a toggle switch can be connected. Connecting J6 pin 1 and pin 2 configures the regular C64 setup (the feedbacks are controlled by MOTOR), connecting pin 3 and pin 2 configured the control port feedbacks being switched on permanently for the SX-64 option. For switching between options, the cut pad JP1 has to be opened. On default (closed) it selects the C64 option.

By default, the C64 only mode is selected, which meansJP1 is closed. Do not connect a switch to J6 without opening JP1.


Diag586220_User_Port_ModD.docx | | 25.05.2024 22:55
Drafted by Sven Petersen | Page 4 of 9 | Doc.-No.: 179-6-01-03

The keyboard testing of the SX-64 requires the C128 keyboard PCB and a DB female-female gender changer. For complete SX-64 testing, the diagnostic software has to be run in C64 mode (control port feedbacks off, keyboard feedbacks on) at least one pass and then in SX-64 mode (control port feedbacks on, keyboard feedbacks off).

## Rev. 3: Voltage indicators and voltmeter

The purpose of the voltmeter is measuring the +5VDC inside the C64, which does make sense. A too low voltage here might indicate a bad power switch or a bad/oxidized power jack.

Figure 5: Front and back of the 0.36" 4-digit voltmeter

Previously, three-digit and four-digit models have been tested. The three-digit models are not suitable, since they showed an error of almost 100mV. The four-digit models can be adjusted on a little potentiometer. Adjustment is required and should be performed before the assembled PCB is installed in the case.

The adjustment is best performed by measuring the voltage between the GND pin and one of the +5V pins of J7, then adjusting the reading of the voltmeter at the potentiometer on the back side. This potentiometer is shown in Figure 5: Front and back of the 0.36" 4-digit voltmeter.

Note: The panel voltmeters, that I have bought for this project were sufficiently accurate, but I
would not grant for all 4 digit “precision panel meters, so the recommended configuration is to
install a pin header and perform the measurement with a multimeter.

Diag586220_User_Port_ModD.docx | | 25.05.2024 22:55
Drafted by Sven Petersen | Page 5 of 9 | Doc.-No.: 179-6-01-03

## Pinouts

### User Port

J1- Edge Connector (2x12, 3.96mm pitch)

Pin Signal | Pin Signal
1 | GND | A | GND
2 | +5V | B | /FLAG2
3 | /RESET | C | PB0
4 | CNT1 | D | PB1
5 | SP1 | E | PB2
6 | CNT2 | F | PB3
7 | SP2 | H | PB4
8 | /PC2 | J | PB5
9 | ATN | K | PB6
10 | 9VAC(1) | L | PB7
11 | 9VAC(2) | M | PA2
12 | GND | N | GND

### Cassette Port

J2 – 2x3 pin header for a ribbon cable connected to the cassette port PCB (project number 114).

Pin Signal | Pin Signal
1 | GND | 2 | n.c.
3 | MOTOR | 4 | READ
5 | WRITE | 6 | SENSE

### Control Port #1

J3 – 2x5 pin header for a ribbon cable which connects via a D-SUB 9 (female) to the control port.

Pin D-SUB Signal | Pin D-SUB Signal
1 | 1 | JOYA0 (up) | 2 | 6 | FIREA
3 | 2 | JOYA1 (down) | 4 | 7 | +5VCTR1
5 | 3 | JOYA2 (left) | 6 | 8 | n.c. (GND)
7 | 4 | JOYA3 (right) | 8 | 9 | POTXA
9 | 5 | POTYA | 10 | - | n.c.

### Control Port #2

J4 – 2x5 pin header for a ribbon cable which connects via a D-SUB 9 (female) to the control port.

Pin D-SUB Signal | Pin D-SUB Signal
1 | 1 | JOYB0 (up) | 2 | 6 | FIREB
3 | 2 | JOYB1 (down) | 4 | 7 | +5VCTR2
5 | 3 | JOYB2 (left) | 6 | 8 | n.c. (GND)
7 | 4 | JOYB3 (right) | 8 | 9 | POTXB
9 | 5 | POTYB | 10 | - | n.c.

### Keyboard

J5 – 2x5 pin header for a ribbon cable which connects to the keyboard PCB.

Diag586220_User_Port_ModD.docx | | 25.05.2024 22:55
Drafted by Sven Petersen | Page 6 of 9 | Doc.-No.: 179-6-01-03
Pin Signal | Pin Signal
1 | Keyboard PB0 | 2 | Keyboard PA0
3 | Keyboard PB4 | 4 | Keyboard PA4
5 | Keyboard PB3 | 6 | Keyboard PA3
7 | Keyboard PB2 | 8 | Keyboard PA2
9 | Keyboard PB1 | 10 | Keyboard PA1

SX-64 Option

J6 – 1x3 pin header (pitch 2.54mm)

Pin | Signal
1 | WRITE
2 | WRITE*
3 | +5V

To use J 6 for switching between SX-64 and C64, cut open JP1. This is the cut pad right beside J6.

Connection pin 1-2 selects the C64 option, connecting pin 2-3 selects the SX-64 option, which switches on the control port feedbacks.

### Panelmeter Connector

J7 – 1x3 pin header, 2.54mm pitch

Pin | Signal
1 | GND
2 | +5V
3 | +5V

### 9VAC Connector

J8 - 1x2 pin header, 2.54mm pitch

Pin | Signal
1 | 9VAC1
2 | 9VAC2

## Interconnects

### User Port

Pin | Signal | Signal | Pin
4 | CNT1 | « | CNT2 | 6
5 | SP1 | « | SP2 | 7
8 | /PC2 | « | /FLAG2 | B
9 | ATN | « | PA2 | M
C | PB0 | « | PB4 | H
D | PB1 | « | PB5 | J
E | PB2 | « | PB6 | K
F | PB3 | « | PB7 | L

Diag586220_User_Port_ModD.docx | | 25.05.2024 22:55
Drafted by Sven Petersen | Page 7 of 9 | Doc.-No.: 179-6-01-03

### Cassette Port

Pin | Signal | Signal Pin
1 | GND | | n/c | 2
3 | MOTOR | Volt.div. | WRITE | 5
4 | READ | « | SENSE | 6

### Control Ports

Signal | Signal
FIREA | switched by MOTOR | FIREB
JOYA0 | switched by MOTOR | JOYB0
JOYA1 | switched by MOTOR | JOYB1
JOYA2 | switched by MOTOR | JOYB2
JOYA3 | switched by MOTOR | JOYB3
POTXA | via 110kΩ (R1) | +5V (CTR 1)
POTYA | via 110kΩ (R2) | +5V (CTR 1)
POTXB | via 110kΩ (R5) | +5V (CTR 2)
POTYB | via 110kΩ (R6) | +5V (CTR 2)

The digital signals of the control ports are connected by an analog switch. A HIGH level of the MOTOR signal will switch on.

The POT (paddle) signals are tested with a fix resistor of 110k, that is connected to the +5V provided by the respective control port.

## Cables

### User Port/Cassette Port Cable

One cable as shown in Doc.-No. 113-3-01-01 is required. It connects to J2. This cable needs to be longer for C128

### User Port/Control Cables

Two cables as shown in Doc.-Nr. 113-3-02-01 are required. They connect to J3 and J4.

### User Port/Keyboard PCB Cable

One cable as shown in Doc.-No. 113-3-04-01 is required. It connects to J5 and the keyboard PCB (C64 or C128). For the C128 this cable has to be longer.

### The IEC-Dongle

The IEC-Dongle is not attached to the PCB, it is an extra built.

6p. DIN plug, connect according to Doc.-No. 113-3-03-01

Pin | Signal | Signal Pin
1 | SRQ | « | DATA | 5
3 | ATN | « | CLK | 4


Diag586220_User_Port_ModD.docx | | 25.05.2024 22:55
Drafted by Sven Petersen | Page 8 of 9 | Doc.-No.: 179-6-01-03

## Block diagram of the Diagnostic Harness Rev. 3

Diag586220_User_Port_ModD.docx | | 25.05.2024 22:55
Drafted by Sven Petersen | Page 9 of 9 | Doc.-No.: 179-6-01-03

## Revision History

### BOM v0.1 → v0.2

- Pos. 6: value 120k →110k
- Pos. 8: value 320R →316R

### Rev. 0 → Rev. 1

- This is a PCB revision
- Analog switches added (IC3)
- Pin header added (J5)
- New Ribbon Cable
- 3D printed case (Rev. 1) is required

### Rev. 1 → Rev. 2

- This is a PCB revision
- Pin header J6 and cup pad JP1 added
- It can either be installed in the Rev. 1 3D printed case, if no switch option SX64 is desired or in the User Port Case SX-64, which provides mounting holes for a toggle switch (19mm hole distance, standard switch).

### Rev. 2 → Rev. 2 SMD

- This is the Rev. 2 with SMD parts for easier fabrication. No other technical changes were done.

### Rev. 2 SMD → Rev. 3 SMD

- LEDs added for presence indication of +5V and 9VAC
- Connector for panel meter
- Connector for 9VAC
- New 3D printed cases.











Diag586220_User_Port_Test.docx | | 25.05.2024 22:44
Drafted by Sven Petersen | Page 1 of 2 | Doc.-No.: 179-6-02-03

### Diagnostic Rev. 586220 Harness - User Port SMD Rev. 3

### Testing

This document describes the testing procedure of the complete Rev. 1 diagnostic harness. A Rev. 0/1/2/3 Harness was connected to a known working C64 (ASSY250469). The dongles were introduced one by one.

Figure 1: Harness Rev. 1 while being tested

First, the keyboard dongle Rev. 1 was connected, J2 was bridged with jumpers (the feedback connections were made permanent this way).

The Diagnostic Rev. 586220 cartridge was installed and the diagnostic test was run. It was
completed successfully, all components were reported “OK”.

Next was the Cassette Dongle Rev. 1 being connected for the test. The diagnostic test was

### passed, all components were reported “OK”. The SENSE LED changed the status several times

while the test, the MOTOR LED was off and only switched on for the cassette port test and the control port test.

The User Port Dongle Rev. 1 was then connected and a ribbon cable between J5 and the
keyboard dongle Rev. 1. The diagnostic test was passed, all components were reported “OK”.

To simulate a failing control port connection, IC1 was extracted from the socket. The
diagnostic test reported the control ports “BAD”. IC1 was installed again.

To simulate a failing keyboard connection, the ribbon cable to the keyboard dongle was
removed. The diagnostic test reported the keyboard “BAD”.

The keyboard dongle was removed from the setup completely. The diagnostic test reported
the keyboard “OPEN”.

Diag586220_User_Port_Test.docx | | 25.05.2024 22:44
Drafted by Sven Petersen | Page 2 of 2 | Doc.-No.: 179-6-02-03

The test harness was completely removed, except the Cassette Dongle. The Diagnostic Cartridge was disconnected from the C64. A Datassette with a tape was connected to the Cassette Dongle. The purpose of this test is to prove the breakout board properties of the Cassette Dongle.

The software on the tape could be loaded successfully.

A short program was written to (another) tape. It could be verified successfully.

Conclusion:

- The Diagnostic Harness Rev. 1 is fully functional.
- Rev. 2 SMD is fully functional
- Rev. 3 SMD is tested and working.

File:; Titel:; Doc.-No.: 113-3-01-01; Date: 08.06.2020 13:05; Diagnostic 586220; Harness; Rev.: 1; Port Cable; e.g. Reichelt RND 205-00680

Draft.: Sven Petersen

UP-CASP.SKF

User Port - Cassette

11 cm Ribbon cable 6p, AWG28, 1,27mm pitch

For C128 diagnostics: 250mm ribbon cable required.

IDC Ribbon Cable Socket 6P

File:; Titel:; Doc.-No.: 113-3-02-01; Date: 08.06.2020 13:08; Diagnostic 586220; Harness; Rev.: 1; e.g. Reichelt RND 205-00682; The 10th wire; here.

1 UP-CTRLP.SKF

Draft.: Sven Petersen

D-SUB-jack, 9p f. ribbon cable

e.g. Reichelt D-SUB BU 09FB

User Port - Control

Port Cable 1 1 64cm Ribbon cable 10p, AWG28, 1,27mm pitch

is clipped off

IDC Ribbon Cable Socket 10P

File:; Titel:; Doc.-No.: 113-3-03-00; Date: 01.03.2019 18:15; Diagnostic 586220; Harness; Rev.: 0; 1 IEC.SKF; IEC-Dongle; 1 (SRQ) 5 (DATA); 3 (ATN); 4 (CLK); side.

Draft.: Sven Petersen

Assembled IEC-Dongle

6p DIN plug, e.g. Reichelt MAS 60

shown from the solder

The open DIN plug,

e.g. Reichelt RND 205-00682; PCB Cable; File:; Titel:; Doc.-No.: 113-3-04-01; Date: 08.06.2020 13:06; Diagnostic 586220; Harness; Rev.: 1

Draft.: Sven Petersen

UP-KEYB.SKF

IDC Ribbon Cable Socket 10P

User Port - Keyboard

43cm Ribbon cable 10p, AWG28, 1,27mm pitch

For C128 Diagnostics: 76cm ribbon cable required

(beside the C128 Keyboard PCB)

Pos. Qty Value Footprint Ref.-No. Comment

1 1 3113-2-01-02 2 Layer PCB Rev. 3 2 layer, Cu 35µ, HASL, LLL x BBB, 1.6mm FR4

2 1 2x3 box connector 2X03WV J2 e.g. Reichelt WSL 6G

3 3 2x5 box connector 2X05WV J3, J4, J5 e.g. Reichelt WSL 10G
4 0 0R 0805 R7 Removed in Rev. 3

5 4 100n/50V 0805 C1, C2, C3, C4 cer. cap, 2.5mm pitch

6 4 110k 0805 R1, R2, R5, R6 1/4W, 1%
7 1 150R 0805 R4 1/4W, 5%

8 2 330R 0805 R3, R10 1/4W, 5%

9 3 HCF4066B SO14 IC1, IC2, IC3 ST Micro or equivalent

10 1 2x12, 3.96mm pitch USERPORT J1 edge connector, C64 user port

11 1 TP 1pin 1,2MM_R TP1 optional, Pin Header, e.g. Reichelt RND 205-00622

12 182cm 10p/AWG28/1,27mm Doc-No. 113-3-02-01,

Doc.-No. 113-3-01-01,
Doc.-No. 113-3-04-01

Ribbon Cable

13 2 6p IDC receptable,

2,54mm

Doc.-No. 113-2-01-01 e.g. Reichelt RND 205-00680

14 4 10p IDC receptable,

2,54mm

Doc.-No. 113-3-02-01,
Doc.-No. 113-3-04-01

e.g. Reichelt RND 205-00682
15 2 9p D-SUB (female), IDC Doc.-No. 113-3-02-01 e.g. Reichelt D-SUB BU 09FB

16 1 DIN-plug 6p Doc.-No. 113-3-03-01 e.g. Reichelt MAS 60
17 4cm Wire 0,25mm², red Doc.-No. 113-3-03-01 wire, color what ever

18 1 10k 0805 R8 1/4W, 5%

19 1 3x1pin, 2.54mm J6 optional pin header, 2.54mm pitch

20 1 jumper, 2.54mm (J6) option. Toggle Switch can be connected alternatively

21 1 cut pad JP1 not part, it is on the PCB. Closed by default for C64. For

switching, cut open

22 1 1x3p., 2.54mm 1x03 J7 solderpads for voltmeter (see discription)

23 1 1x2p., 2.54mm 1x02 J8 do not place (see discription)

24 2 3mm, green LED 3mm LD1, LD2 standard LED

## Diagnostic Rev. 586220 Harness - User Port SMD Rev. 3

## Bill of Material Rev. 3.0

Diag586220_UserPort_SMD_BOM_v3_0.xlsx

Drafted by Sven Petersen Page 1 of 2

05.03.2022 17:27
Doc.No.: 179-5-01-02.0

Pos. Qty Value Footprint Ref.-No. Comment

## Diagnostic Rev. 586220 Harness - User Port SMD Rev. 3

## Bill of Material Rev. 3.0

25 1 LL4148 MiniMELF D1 diode

26 1 1k R-10 R9 1/4W, 5%

### Rev. 2.0 → SMD 2.0

Pos. 4-9 SMD

Pos. 18 SMD

### Rev. SMD 2.0 → 3.0

Pos. 1 PCB Rev. 3

Pos. 4 0R resistor R7 removed

Pos. 8 2 each (R10 new)

Pos. 22 new

Pos. 23 new

Pos. 24 new

Pos. 25 new

Pos. 26 new

Diag586220_UserPort_SMD_BOM_v3_0.xlsx

Drafted by Sven Petersen Page 2 of 2

05.03.2022 17:27
Doc.No.: 179-5-01-02.0

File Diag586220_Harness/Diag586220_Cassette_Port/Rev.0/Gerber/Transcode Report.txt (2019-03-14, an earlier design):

   ---- Transcoding 'X:\Projekte\_Eigene\Diag586220_Harness\Diag586220_Cassette_Port\Rev.0\Gerber\gerber_Diag_586220_Cassette.out' ----   Sat Mar 02 12:09:53 2019

D13   --> D100
-----------------------------------------------------------------

   ---- Transcoding 'X:\Projekte\_Eigene\Diag586220_Harness\Diag586220_Cassette_Port\Rev.0\Gerber\gerber_Diag_586220_Cassette.plc' ----   Sat Mar 02 12:09:53 2019

D11   --> D101
D12   --> D102
D13   --> D103
D14   --> D104
D15   --> D105
D16   --> D106
-----------------------------------------------------------------

   ---- Transcoding 'X:\Projekte\_Eigene\Diag586220_Harness\Diag586220_Cassette_Port\Rev.0\Gerber\gerber_Diag_586220_Cassette.stc' ----   Sat Mar 02 12:09:53 2019

D12   --> D107
D13   --> D108
D14   --> D109
D15   --> D110
D16   --> D111
D17   --> D112
D18   --> D113
D19   --> D114
D20   --> D115
D21   --> D116
-----------------------------------------------------------------

   ---- Transcoding 'X:\Projekte\_Eigene\Diag586220_Harness\Diag586220_Cassette_Port\Rev.0\Gerber\gerber_Diag_586220_Cassette.sts' ----   Sat Mar 02 12:09:53 2019

D12   --> D117
D13   --> D118
D14   --> D119
D15   --> D120
D16   --> D121
D17   --> D122
D18   --> D123
D19   --> D124
D20   --> D125
D21   --> D126
-----------------------------------------------------------------

   ---- Transcoding 'X:\Projekte\_Eigene\Diag586220_Harness\Diag586220_Cassette_Port\Rev.0\Gerber\gerber_Diag_586220_Cassette.top' ----   Sat Mar 02 12:09:53 2019

D12   --> D127
D13   --> D128
D14   --> D129
D15   --> D130
D23   --> D131
D24   --> D132
-----------------------------------------------------------------

   ---- Transcoding 'X:\Projekte\_Eigene\Diag586220_Harness\Diag586220_Cassette_Port\Rev.0\Gerber\gerber_Diag_586220_Cassette.out' ----   Sat Mar 02 12:12:16 2019

D13   --> D100
-----------------------------------------------------------------

   ---- Transcoding 'X:\Projekte\_Eigene\Diag586220_Harness\Diag586220_Cassette_Port\Rev.0\Gerber\gerber_Diag_586220_Cassette.plc' ----   Sat Mar 02 12:12:16 2019

D11   --> D101
D12   --> D102
D13   --> D103
D14   --> D104
D15   --> D105
D16   --> D106
-----------------------------------------------------------------

   ---- Transcoding 'X:\Projekte\_Eigene\Diag586220_Harness\Diag586220_Cassette_Port\Rev.0\Gerber\gerber_Diag_586220_Cassette.stc' ----   Sat Mar 02 12:12:16 2019

D12   --> D107
D13   --> D108
D14   --> D109
D15   --> D110
D16   --> D111
D17   --> D112
D18   --> D113
D19   --> D114
D20   --> D115
D21   --> D116
-----------------------------------------------------------------

   ---- Transcoding 'X:\Projekte\_Eigene\Diag586220_Harness\Diag586220_Cassette_Port\Rev.0\Gerber\gerber_Diag_586220_Cassette.sts' ----   Sat Mar 02 12:12:16 2019

D12   --> D117
D13   --> D118
D14   --> D119
D15   --> D120
D16   --> D121
D17   --> D122
D18   --> D123
D19   --> D124
D20   --> D125
D21   --> D126
-----------------------------------------------------------------

   ---- Transcoding 'X:\Projekte\_Eigene\Diag586220_Harness\Diag586220_Cassette_Port\Rev.0\Gerber\gerber_Diag_586220_Cassette.top' ----   Sat Mar 02 12:12:16 2019

D12   --> D127
D13   --> D128
D14   --> D129
D15   --> D130
D23   --> D131
D24   --> D132
-----------------------------------------------------------------

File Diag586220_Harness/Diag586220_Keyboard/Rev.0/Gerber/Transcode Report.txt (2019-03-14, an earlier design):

   ---- Transcoding 'X:\Projekte\_Eigene\Diag586220_Harness\Diag586220_Keyboard\Rev.0\Gerber\gerber_C64_Keyb-Test.out' ----   Sat Mar 02 12:16:59 2019

D11   --> D100
D12   --> D101
D13   --> D102
-----------------------------------------------------------------

   ---- Transcoding 'X:\Projekte\_Eigene\Diag586220_Harness\Diag586220_Keyboard\Rev.0\Gerber\gerber_C64_Keyb-Test.plc' ----   Sat Mar 02 12:16:59 2019

D11   --> D103
D13   --> D104
D14   --> D105
D15   --> D106
D16   --> D107
D17   --> D108
-----------------------------------------------------------------

   ---- Transcoding 'X:\Projekte\_Eigene\Diag586220_Harness\Diag586220_Keyboard\Rev.0\Gerber\gerber_C64_Keyb-Test.stc' ----   Sat Mar 02 12:16:59 2019

D11   --> D109
D13   --> D110
D14   --> D111
D15   --> D112
D16   --> D113
D17   --> D114
D19   --> D115
D20   --> D116
-----------------------------------------------------------------

   ---- Transcoding 'X:\Projekte\_Eigene\Diag586220_Harness\Diag586220_Keyboard\Rev.0\Gerber\gerber_C64_Keyb-Test.sts' ----   Sat Mar 02 12:16:59 2019

D11   --> D117
D13   --> D118
D14   --> D119
D15   --> D120
D16   --> D121
D17   --> D122
D19   --> D123
D20   --> D124
-----------------------------------------------------------------

   ---- Transcoding 'X:\Projekte\_Eigene\Diag586220_Harness\Diag586220_Keyboard\Rev.0\Gerber\gerber_C64_Keyb-Test.top' ----   Sat Mar 02 12:17:00 2019

D11   --> D125
D12   --> D126
D13   --> D127
D14   --> D128
D15   --> D129
D16   --> D130
D17   --> D131
D18   --> D132
D19   --> D133
D20   --> D134
D21   --> D135
D22   --> D136
D23   --> D137
-----------------------------------------------------------------

   ---- Transcoding 'X:\Projekte\_Eigene\Diag586220_Harness\Diag586220_Keyboard\Rev.0\Gerber\excellon_C64_Keyb-Test.ndk' ----   Sat Mar 02 12:17:18 2019

T1   --> T5
-----------------------------------------------------------------

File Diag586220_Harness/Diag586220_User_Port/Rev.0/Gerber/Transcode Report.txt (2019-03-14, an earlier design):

   ---- Transcoding 'X:\Projekte\_Eigene\Diag586220_Harness\Diag586220_User_Port\Rev.0\Gerber\gerber_C64_Userport_Test.out' ----   Sat Mar 02 12:18:55 2019

D11   --> D100
D12   --> D101
D13   --> D102
-----------------------------------------------------------------

   ---- Transcoding 'X:\Projekte\_Eigene\Diag586220_Harness\Diag586220_User_Port\Rev.0\Gerber\gerber_C64_Userport_Test.plc' ----   Sat Mar 02 12:18:55 2019

D11   --> D103
D12   --> D104
D13   --> D105
D14   --> D106
D15   --> D107
-----------------------------------------------------------------

   ---- Transcoding 'X:\Projekte\_Eigene\Diag586220_Harness\Diag586220_User_Port\Rev.0\Gerber\gerber_C64_Userport_Test.stc' ----   Sat Mar 02 12:18:55 2019

D11   --> D108
D12   --> D109
D13   --> D110
D14   --> D111
D15   --> D112
D16   --> D113
D17   --> D114
D18   --> D115
D19   --> D116
D20   --> D117
D21   --> D118
D22   --> D119
-----------------------------------------------------------------

   ---- Transcoding 'X:\Projekte\_Eigene\Diag586220_Harness\Diag586220_User_Port\Rev.0\Gerber\gerber_C64_Userport_Test.sts' ----   Sat Mar 02 12:18:55 2019

D11   --> D120
D12   --> D121
D13   --> D122
D14   --> D123
D15   --> D124
D16   --> D125
D17   --> D126
D18   --> D127
D19   --> D128
D20   --> D129
D21   --> D130
D22   --> D131
-----------------------------------------------------------------

   ---- Transcoding 'X:\Projekte\_Eigene\Diag586220_Harness\Diag586220_User_Port\Rev.0\Gerber\gerber_C64_Userport_Test.top' ----   Sat Mar 02 12:18:55 2019

D11   --> D132
D12   --> D133
D13   --> D134
D14   --> D135
D15   --> D136
D16   --> D137
D17   --> D138
D18   --> D139
D19   --> D140
D20   --> D141
D21   --> D142
D22   --> D143
D23   --> D144
D24   --> D145
D25   --> D146
D26   --> D147
-----------------------------------------------------------------

   ---- Transcoding 'X:\Projekte\_Eigene\Diag586220_Harness\Diag586220_User_Port\Rev.0\Gerber\gerber_C64_Userport_Test.out' ----   Sat Mar 02 12:19:21 2019

D11   --> D100
D12   --> D101
D13   --> D102
-----------------------------------------------------------------

   ---- Transcoding 'X:\Projekte\_Eigene\Diag586220_Harness\Diag586220_User_Port\Rev.0\Gerber\gerber_C64_Userport_Test.plc' ----   Sat Mar 02 12:19:21 2019

D11   --> D103
D12   --> D104
D13   --> D105
D14   --> D106
D15   --> D107
-----------------------------------------------------------------

   ---- Transcoding 'X:\Projekte\_Eigene\Diag586220_Harness\Diag586220_User_Port\Rev.0\Gerber\gerber_C64_Userport_Test.stc' ----   Sat Mar 02 12:19:21 2019

D11   --> D108
D12   --> D109
D13   --> D110
D14   --> D111
D15   --> D112
D16   --> D113
D17   --> D114
D18   --> D115
D19   --> D116
D20   --> D117
D21   --> D118
D22   --> D119
-----------------------------------------------------------------

   ---- Transcoding 'X:\Projekte\_Eigene\Diag586220_Harness\Diag586220_User_Port\Rev.0\Gerber\gerber_C64_Userport_Test.sts' ----   Sat Mar 02 12:19:21 2019

D11   --> D120
D12   --> D121
D13   --> D122
D14   --> D123
D15   --> D124
D16   --> D125
D17   --> D126
D18   --> D127
D19   --> D128
D20   --> D129
D21   --> D130
D22   --> D131
-----------------------------------------------------------------

   ---- Transcoding 'X:\Projekte\_Eigene\Diag586220_Harness\Diag586220_User_Port\Rev.0\Gerber\gerber_C64_Userport_Test.top' ----   Sat Mar 02 12:19:21 2019

D11   --> D132
D12   --> D133
D13   --> D134
D14   --> D135
D15   --> D136
D16   --> D137
D17   --> D138
D18   --> D139
D19   --> D140
D20   --> D141
D21   --> D142
D22   --> D143
D23   --> D144
D24   --> D145
D25   --> D146
D26   --> D147
-----------------------------------------------------------------

   ---- Transcoding 'X:\Projekte\_Eigene\Diag586220_Harness\Diag586220_User_Port\Rev.0\Gerber\gerber_C64_Userport_Test.out' ----   Sat Mar 02 12:27:07 2019

D11   --> D100
D12   --> D101
D13   --> D102
-----------------------------------------------------------------

   ---- Transcoding 'X:\Projekte\_Eigene\Diag586220_Harness\Diag586220_User_Port\Rev.0\Gerber\gerber_C64_Userport_Test.plc' ----   Sat Mar 02 12:27:07 2019

D11   --> D103
D12   --> D104
D13   --> D105
D14   --> D106
D15   --> D107
-----------------------------------------------------------------

   ---- Transcoding 'X:\Projekte\_Eigene\Diag586220_Harness\Diag586220_User_Port\Rev.0\Gerber\gerber_C64_Userport_Test.pls' ----   Sat Mar 02 12:27:07 2019

D11   --> D108
D12   --> D109
D13   --> D110
D14   --> D111
-----------------------------------------------------------------

   ---- Transcoding 'X:\Projekte\_Eigene\Diag586220_Harness\Diag586220_User_Port\Rev.0\Gerber\gerber_C64_Userport_Test.stc' ----   Sat Mar 02 12:27:07 2019

D11   --> D112
D12   --> D113
D13   --> D114
D14   --> D115
D15   --> D116
D16   --> D117
D17   --> D118
D18   --> D119
D19   --> D120
D20   --> D121
D21   --> D122
D22   --> D123
-----------------------------------------------------------------

   ---- Transcoding 'X:\Projekte\_Eigene\Diag586220_Harness\Diag586220_User_Port\Rev.0\Gerber\gerber_C64_Userport_Test.sts' ----   Sat Mar 02 12:27:07 2019

D11   --> D124
D12   --> D125
D13   --> D126
D14   --> D127
D15   --> D128
D16   --> D129
D17   --> D130
D18   --> D131
D19   --> D132
D20   --> D133
D21   --> D134
D22   --> D135
-----------------------------------------------------------------

   ---- Transcoding 'X:\Projekte\_Eigene\Diag586220_Harness\Diag586220_User_Port\Rev.0\Gerber\gerber_C64_Userport_Test.top' ----   Sat Mar 02 12:27:08 2019

D11   --> D136
D12   --> D137
D13   --> D138
D14   --> D139
D15   --> D140
D16   --> D141
D17   --> D142
D18   --> D143
D19   --> D144
D20   --> D145
D21   --> D146
D22   --> D147
D23   --> D148
D24   --> D149
D25   --> D150
D26   --> D151
-----------------------------------------------------------------

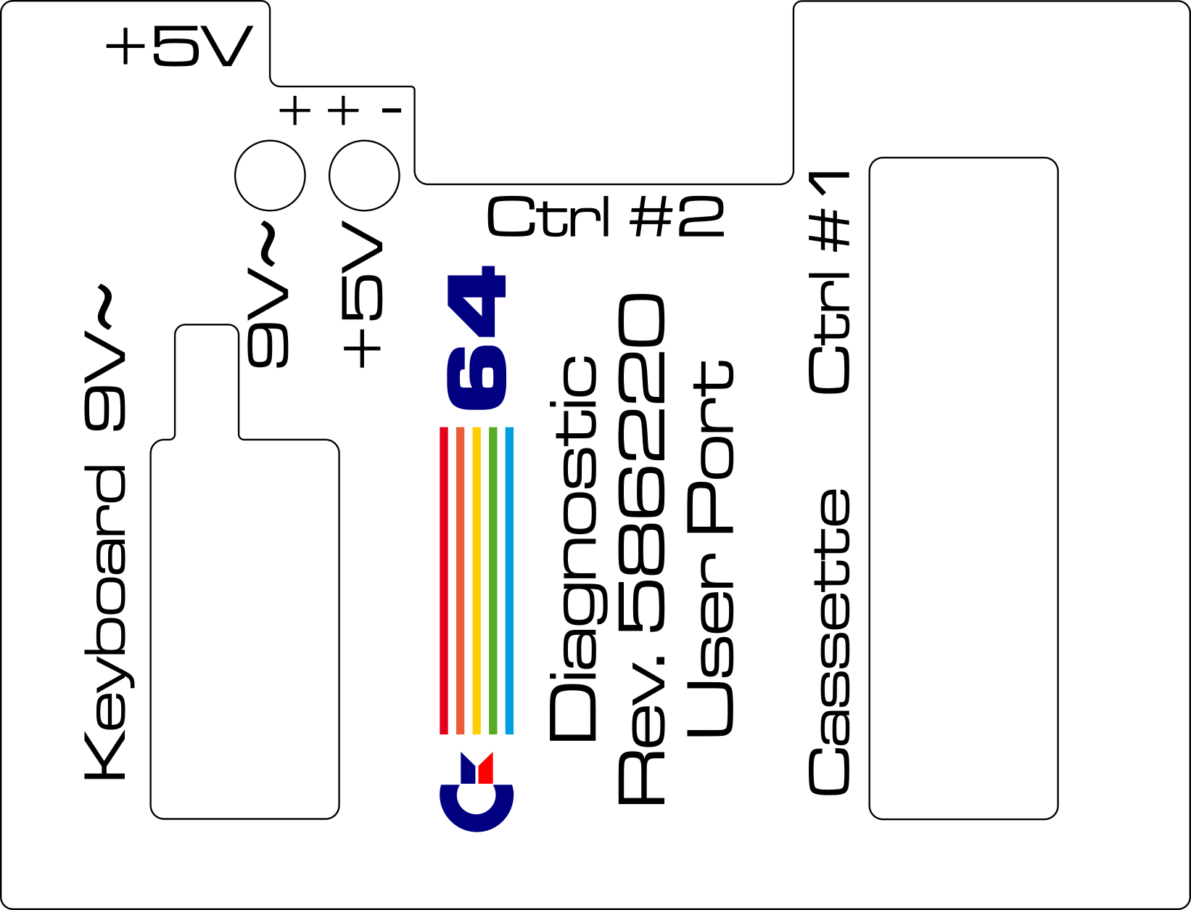
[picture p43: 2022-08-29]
Diag586220_Harness/Case_3D_Data/Label/Rev. 3/Pictures/label_woVM.png

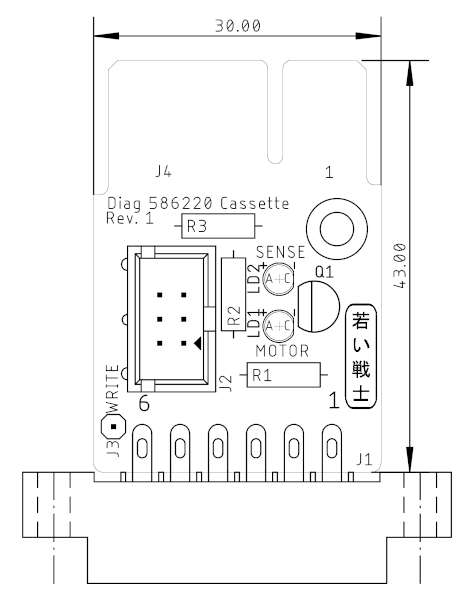
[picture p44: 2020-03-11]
Diag586220_Harness/Diag586220_Cassette_Port/Rev.1/pictures/cassette_pcb.png

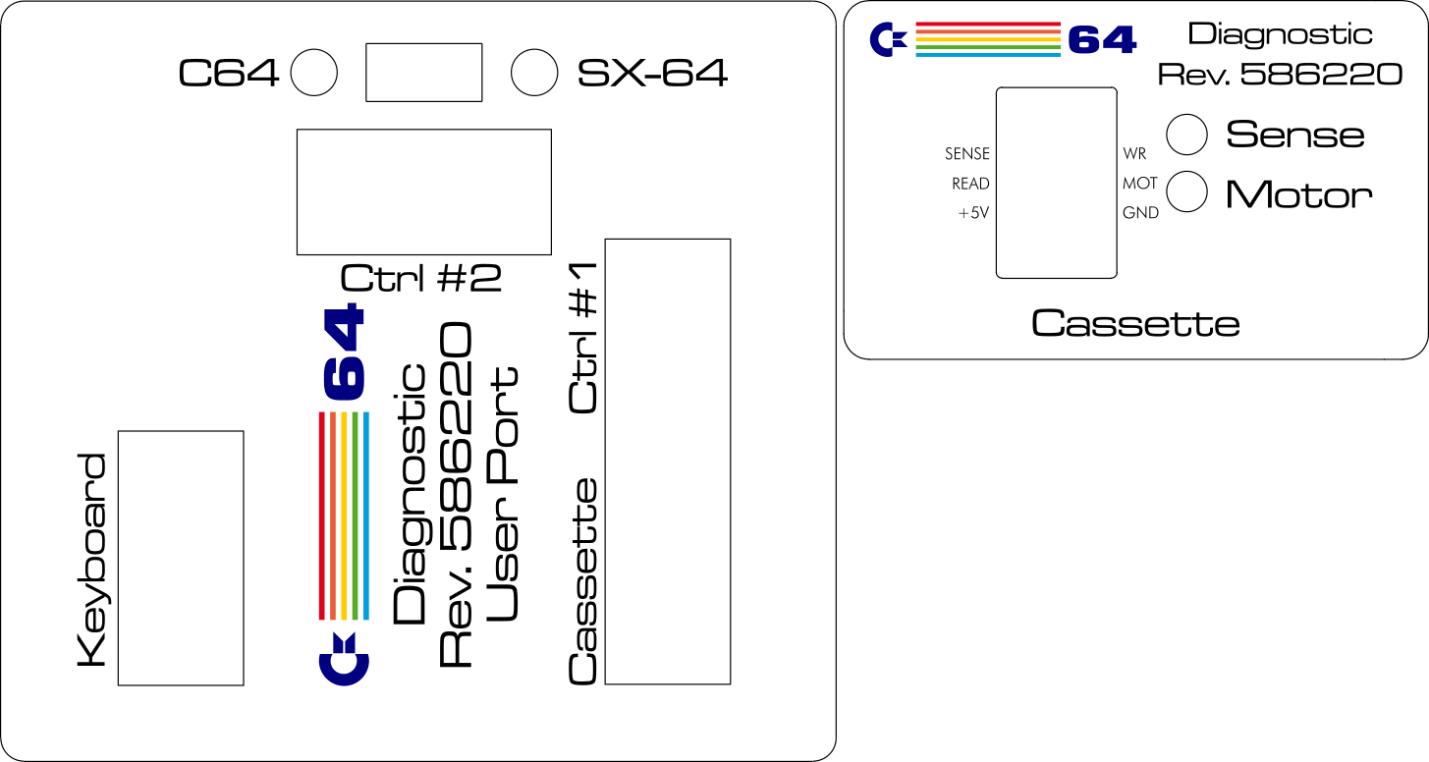
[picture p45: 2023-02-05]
Diag586220_Harness/Case_3D_Data/Label/Rev. 2 (SX-64)/pictures/case_label.png

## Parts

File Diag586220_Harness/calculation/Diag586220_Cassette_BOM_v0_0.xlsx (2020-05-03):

Diagnostic Rev. 586220 Harness - Cassette Port Rev. 0
Bill of Material Rev. 0.0
Pos. | Qty | Value | €/ea | € | Comment
1 | 1 | 114-2-01-00 | 1.00 € | 1.00 € | 2 layer, Cu 35µ, HASL, 30.0mm x 25.0mm, 1.6mm FR4
2 | 1 | 2x6, 3.96mm pitch | 3.00 € | 3.00 € | edge connector, C64 cassette port
3 | 1 | 2x3 box connector | 0.19 € | 0.19 € | e.g. Reichelt WSL 6G
4 | 1 | 3mm/green | 0.20 € | 0.20 € | LED, 3mm, green
5 | 1 | 330R | 0.10 € | 0.10 € | 1/4 Watt, 5%
 |  |  |  | 4.49 €

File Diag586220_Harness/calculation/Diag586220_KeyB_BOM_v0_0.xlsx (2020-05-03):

Diagnostic Rev. 586220 Harness - Keyboard Dongle Rev. 0
Bill of Material Rev. 0.0
Pos. | Qty | Value | €/ea | € | Comment
1 | 1 | 116-2-01-00 | 1.00 € | 1.00 € | 2 layer, Cu 35µ, HASL, 53.0mm x 14.0mm, 1.6mm FR4
2 | 1 | BL1-85AXX-20U | 0.45 € | 0.45 € | e.g. MPE Garry, Reichelt BL 1x20W8 2,54
3 | 1 | 3mm/green | 0.20 € | 0.20 € | LED
4 | 1 | 330R | 0.10 € | 0.10 € | 1/4 Watt, 5%
 |  |  |  | 1.75 €

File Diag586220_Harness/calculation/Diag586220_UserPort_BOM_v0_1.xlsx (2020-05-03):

Diagnostic Rev. 586220 Harness - User Port Rev. 0
Bill of Material Rev. 0.1
Pos. | Qty | Value | €/ea | € | Comment
1 | 1 | 113-2-01-00 | 1.00 € | 1.00 € | 2 layer, Cu 35µ, HASL, LLL x BBB, 1.6mm FR4
2 | 1 | 2x3 box connector | 0.19 € | 0.19 € | e.g. Reichelt WSL 6G
3 | 2 | 2x5 box connector | 0.10 € | 0.20 € | e.g. Reichelt WSL 10G
4 | 1 | 0R | 0.10 € | 0.10 € | 0 Ohm bridge
5 | 3 | 100n/50V | 0.20 € | 0.60 € | cer. cap, 2.5mm pitch
6 | 4 | 120k | 0.10 € | 0.40 € | 1/4W, 1%
7 | 1 | 150R | 0.10 € | 0.10 € | 1/4W, 5%
8 | 1 | 320R | 0.10 € | 0.10 € | 1/4W, 5% (316W works, 330W should work as well)
9 | 2 | HCF4066B | 0.67 € | 1.34 € | ST Micro or equivalent
10 | 2 | DIL 14 | 0.23 € | 0.46 € | DIL IC sockets
11 | 1 | 2x12, 3.96mm pitch | 3.00 € | 3.00 € | edge connector, C64 user port
12 | 3 | TP 1pin | 0.00 € | 0.00 € | Pin Header, e.g. Reichelt RND 205-00622
13 | 127 | 10p/AWG28/1,27mm | 0.01 € | 0.64 € | Ribbon Cable
14 | 2 | 6p IDC receptable, 2,54mm | 0.63 € | 1.26 € | e.g. Reichelt RND 205-00680
15 | 2 | 10p IDC receptable, 2,54mm | 0.25 € | 0.50 € | e.g. Reichelt RND 205-00682
16 | 2 | 9p D-SUB (female), IDC | 0.66 € | 1.32 € | e.g. Reichelt D-SUB BU 09FB
17 | 1 | DIN-plug 6p | 0.26 € | 0.26 € | e.g. Reichelt MAS 60
18 | 4 | Wire 0,25mm², red | 0.00 € | 0.00 € | wire, color what ever
 |  |  |  | 11.46 €

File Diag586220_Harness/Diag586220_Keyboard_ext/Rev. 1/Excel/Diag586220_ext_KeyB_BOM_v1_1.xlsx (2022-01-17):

Diagnostic Rev. 586220 Harness - Extended Keyboard Dongle Rev. 1
Bill of Material Rev. 1.1
Pos. | Qty | Value | Footprint | Ref.-No. | Comment
1 | 1 | 143-2-01-01 | 2 Layer | PCB Rev. 1 | 2 layer, Cu 35µ, HASL, 22.0mm x 55.0mm, 1.6mm FR4
2 | 1 | 3mm green | 3MM | LD1 | LED
3 | 1 | pin header 1x1p | 1X01 | J2 | standard, suitable for dupont pin
4 | 2 | 100n | C-5 | C1, C2 | ceramic cap, 2.5mm pitch
5 | 1 | n/a | R-10 | R3 | 1/4 Watt, 5%
6 | 1 | 330R | R-10 | R1 | 1/4 Watt, 5%
7 | 2 | HCF4066B | DIL14 | IC1, IC2 | ST Micro or equivalent
8 | 1 | BC547B | TO92 | Q1 | NPN Transistor
9 | 1 | BL1-85AXX-20U | BL1-85AXX-20U | J1 | e.g. MPE Garry, Reichelt BL 1x20W8 2,54
10 | 1 | 3k3 | R-10 | R2 | 1/4 Watt, 5%
11 | 1 | 10k | R-10 | R4 | inserted between the base pad and the base of Q1
12 | 1 | 10k | R-10 | R5 | 1/4 Watt, 5%
 |  | Rev. History
 |  | Rev. 0.0 ® Rev. 0.1
Pos | 10 | value of R2
Pos | 11 | R4 is new
 |  | Rev. 0.1 ® Rev. 1.0
Pos | 1 | Board Revision
Pos | 3 | n/a
Pos | 11 | integrated into layout
Pos | 12 | new
 |  | Rev. 1.0 ® Rev. 1.1
Pos | 10 | other value
Pos | 11 | other value

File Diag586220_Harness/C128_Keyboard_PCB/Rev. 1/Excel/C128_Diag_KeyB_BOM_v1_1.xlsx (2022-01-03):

C128 Diagnostic Keyboard PCB Rev. 1
Bill of Material Rev. 1.1
Pos. | Qty | Value | Footprint | Ref.-No. | Comment
1 | 1 | 145-2-01-01 | 2 Layer | PCB Rev. 1 | 2 layer, Cu 35µ, HASL, 28.0 x 48.0mm, 1.6mm FR4
2 | 1 | 2x5pin box header, 2.54mm pitch | 2X05WV | J3 | e.g. Reichelt.de: WSL 10G.
3 | 1 | LED 3mm, green | 3MM | LD1 | LED, standard
4 | 1 | 330R | R-10 | R1 | Resistor, 0.25W, 5% or better
5 | 1 | DB25F/EDGE | DB25F-EDGE | J2 | DSub 25, female, solder cups, strikly recommended type: Amphenol DB25S064TLF (Digikey 609-1519-ND, Farnell 2347730, Mouser 649-DB25S064TLF, Newark: 62K4006, Conrad.de: 1401537 - 62). Other might not connect the square pin header on the C128 mobo not well enough.
6 | 1 | DB25M/EDGE | DB25M-EDGE | J1 | DSub 25, male, solder cups, e.g. Reichelt.de: D-SUB ST 25
7 | 1 | 10k | R-10 | R1 | Resistor, 0.25W, 5% or better
8 | 1 | JTP-1130 | JTP-1130 | SW2 | Standard 6x6mm tact switch, e.g. Namae JTP-1130 or any other
9 | 1 | HCF4066B | DIL14 | IC1 | ST Micro or equivalent (4066)
10 | 1 | DIL 14 | DIL14 | (IC1) | DIL IC sockets
11 | 1 | 100n/50V | C-2,5 | C1 | cer. cap, 2.5mm pitch
 |  | Rev. History
 |  | Rev. 0.0 ® 1.0
Pos. | 1 | PCB Revision
 |  | Rev. 1.0 -> 1.1
Pos. | 5 | Recommended: Amphenol

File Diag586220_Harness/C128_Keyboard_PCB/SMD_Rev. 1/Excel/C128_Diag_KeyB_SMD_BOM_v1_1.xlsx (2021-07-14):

C128 Diagnostic Keyboard PCB/SMD Rev. 1
Bill of Material Rev. 1.1
Pos. | Qty | Value | Footprint | Ref.-No. | Comment
1 | 1 | 181-2-01-01 | 2 Layer | PCB Rev. 1 | 2 layer, Cu 35µ, HASL, 28.0 x 48.0mm, 1.6mm FR4
2 | 1 | 2x5pin box header, 2.54mm pitch | 2X05WV | J3 | e.g. Reichelt.de: WSL 10G.
3 | 1 | LED 3mm, green | 3MM | LD1 | LED, standard
4 | 1 | 330R | 0805 | R1 | Resistor, 0.25W, 5% or better
5 | 1 | DB25F/EDGE | DB25F-EDGE | J2 | DSub 25, female, solder cups, e.g. Reichelt.de: D-SUB BU 25 Recommended: Amphenol DB25S064TLF (Digikey 609-1519-ND)
6 | 1 | DB25M/EDGE | DB25M-EDGE | J1 | DSub 25, male, solder cups, e.g. Reichelt.de: D-SUB ST 25
7 | 1 | 10k | 0805 | R1 | Resistor, 0.25W, 5% or better
8 | 1 | JTP-1130 | JTP-1130 | SW2 | Standard 6x6mm tact switch, e.g. Namae JTP-1130 or any other
9 | 1 | HCF4066B | SO14 | IC1 | ST Micro or equivalent (4066)
10 | 1 | 100n/50V | 0805 | C1 | cer. Cap
 |  | Rev. History
 |  | Rev. 0.0 ® 1.0
Pos. | 1 | PCB Revision
 |  | Rev. 1.0 ® 1.0/SMD
Pos. | 1 | PCB Revision
 | 4 | SMD
 | 7 | SMD
 | 9 | SMD
 | 10 | SMD
 |  | Rev. 1.0/SMD ® 1.1
Pos. | 5 | Recommended: Amphenol

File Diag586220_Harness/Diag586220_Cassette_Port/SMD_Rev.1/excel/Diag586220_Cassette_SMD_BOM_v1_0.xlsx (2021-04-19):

Diagnostic Rev. 586220 Harness - Cassette Port SMD Rev. 1
Bill of Material Rev. 1.0
Pos. | Qty | Value | Footprint | Ref.-No. | Comment
1 | 1 | 180-2-01-01 | 2 Layer | PCB Rev. 1 | 2 layer, Cu 35µ, HASL, 30.0mm x 43.0mm, 1.6mm FR4
2 | 1 | 2x6, 3.96mm pitch | C64-TAPEPORT | J1 | edge connector, C64 cassette port
3 | 1 | 2x3 box connector | 2X03WV | J2 | e.g. Reichelt WSL 6G
4 | 1 | 3mm/green | 3MM | LD1 | LED, 3mm, green
5 | 2 | 330R | 0805 | R1, R2 | 1/4 Watt, 5%
6 | 1 | BC846B | SOT23 | Q1 | Transistor, universal NPN (or BC847 etc.)
7 | 1 | 10K | 0805 | R3 | 1/4 Watt, 5%
8 | 1 | 3mm/red | 3MM | LD2 | LED, 3mm, red
9 | 1 | pin header 1p | 1x01 | J3 | Pin header for DuPont contact/do not place
10 | 1 | C64 Tapeport M | C64-TAPEPORTM | J4 | do not place. Structure in copper/PCB

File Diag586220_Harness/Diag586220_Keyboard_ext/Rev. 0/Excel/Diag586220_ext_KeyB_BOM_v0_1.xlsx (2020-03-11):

Diagnostic Rev. 586220 Harness - Extended Keyboard Dongle Rev. 0
Bill of Material Rev. 0.1
Pos. | Qty | Value | Footprint | Ref.-No. | Comment
1 | 1 | 143-2-01-00 | 2 Layer | PCB Rev. 0 | 2 layer, Cu 35µ, HASL, 22.0mm x 55.0mm, 1.6mm FR4
2 | 1 | 3mm green | 3MM | LD1 | LED
3 | 1 | pin header 1x1p | 1X01 | J2 | standard, suitable for dupont pin
4 | 2 | 100n | C-5 | C1, C2 | ceramic cap, 2.5mm pitch
5 | 1 | 10k | R-10 | R3 | 1/4 Watt, 5%
6 | 1 | 330R | R-10 | R1 | 1/4 Watt, 5%
7 | 2 | HCF4066B | DIL14 | IC1, IC2 | ST Micro or equivalent
8 | 1 | BC547B | TO92 | Q1 | NPN Transistor
9 | 1 | BL1-85AXX-20U | BL1-85AXX-20U | J1 | e.g. MPE Garry, Reichelt BL 1x20W8 2,54
10 | 1 | 1k | R-10 | R2 | 1/4 Watt, 5%
11 | 1 | 4k7 | 0805 | R4 | inserted between the base pad and the base of Q1
 |  | Rev. History
 |  | Rev. 0.0 ® Rev. 0.1
Pos | 10 | value of R2
Pos | 11 | R4 is new

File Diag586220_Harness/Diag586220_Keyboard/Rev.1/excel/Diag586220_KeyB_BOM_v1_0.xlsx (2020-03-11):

Diagnostic Rev. 586220 Harness - Keyboard Dongle Rev. 1
Bill of Material Rev. 1.0
Pos. | Qty | Value | Footprint | Ref.-No. | Comment
1 | 1 | 116-2-01-00 | 2 Layer | PCB Rev. 1 | 2 layer, Cu 35µ, HASL, 53.0mm x 17.0mm, 1.6mm FR4
2 | 1 | BL1-85AXX-20U | BL1-85AXX-20U | J1 | e.g. MPE Garry, Reichelt BL 1x20W8 2,54
3 | 1 | 3mm/green | 3MM | LD1 | LED
4 | 1 | 330R | R-10 | R1 | 1/4 Watt, 5%
5 | 1 | boxed pin header 2x5, 2.54mm pitc | 2x05WV | J2 | e.g. Reichelt WSL 10G

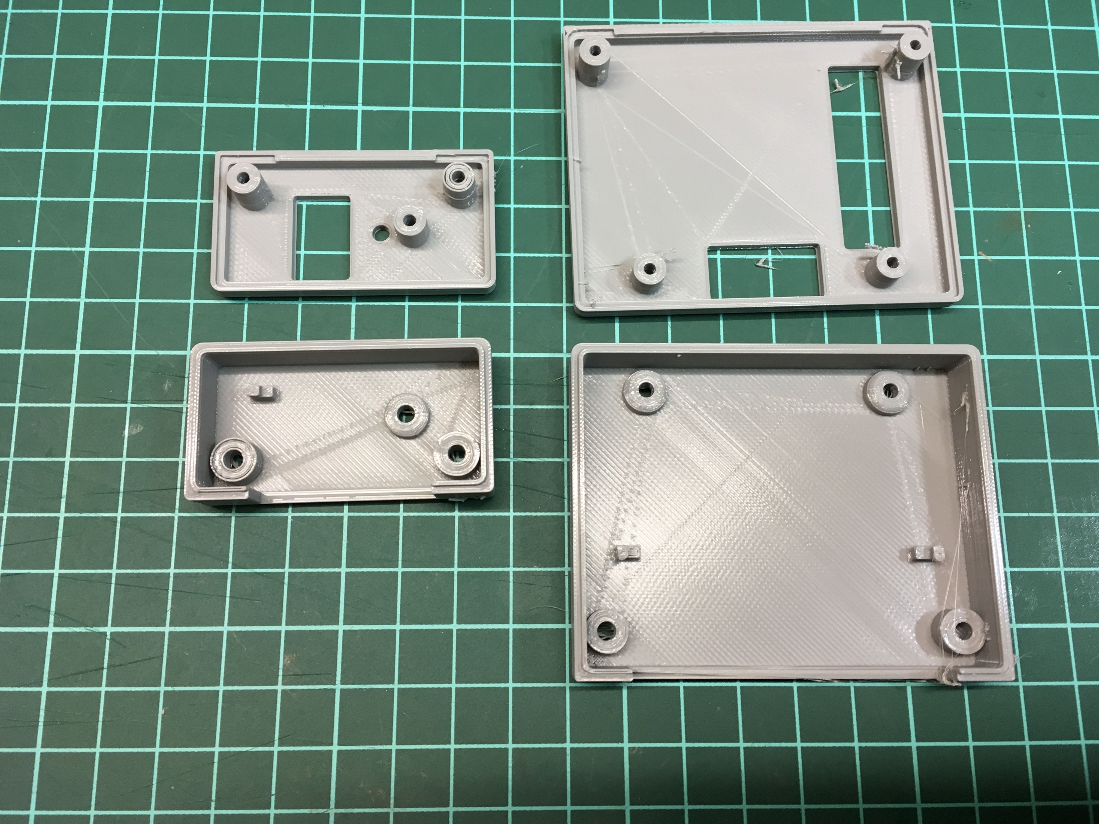
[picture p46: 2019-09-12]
Diag586220_Harness/Case_3D_Data/User Port/Rev. 0/Picture/2650_3D_printed_parts.JPG

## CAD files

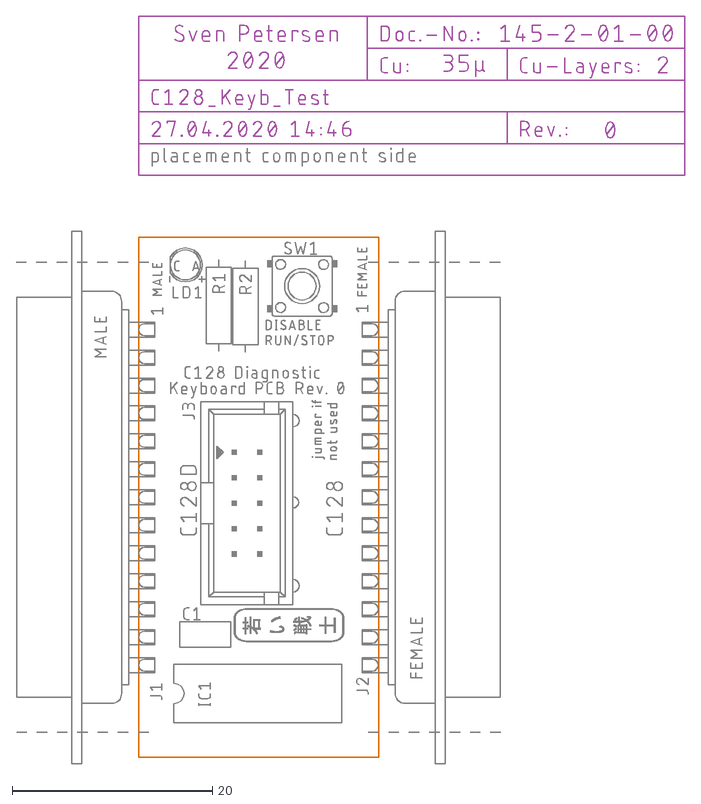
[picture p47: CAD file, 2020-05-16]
Diag586220_Harness/C128_Keyboard_PCB/Rev. 0/dxf/C128_Keyb_Test.dxf
66.9 x 74.7

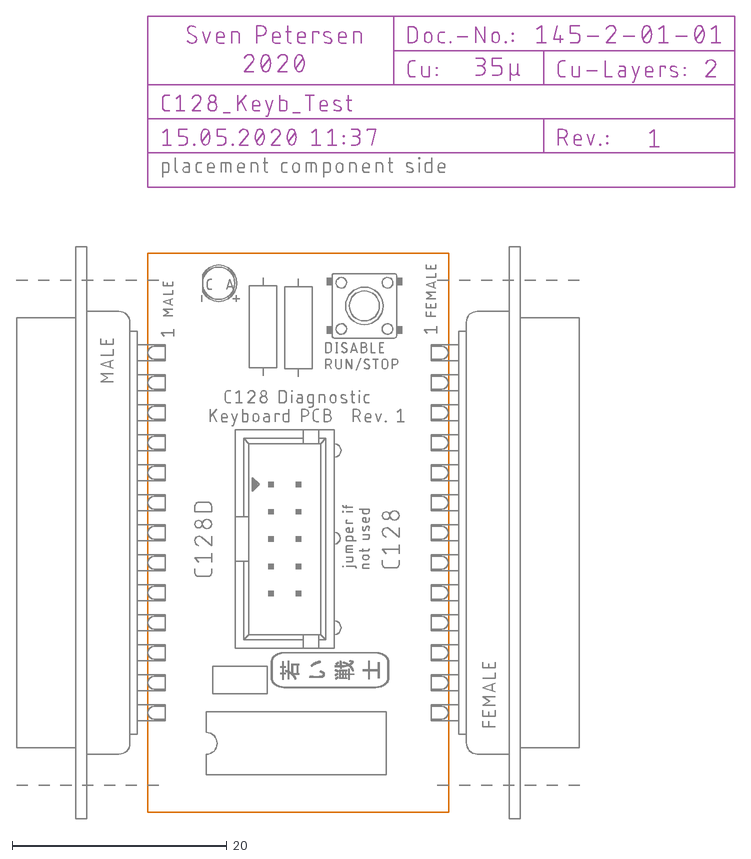
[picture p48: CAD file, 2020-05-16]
Diag586220_Harness/C128_Keyboard_PCB/Rev. 1/dxf/C128_Keyb_Test.dxf
66.9 x 74.7

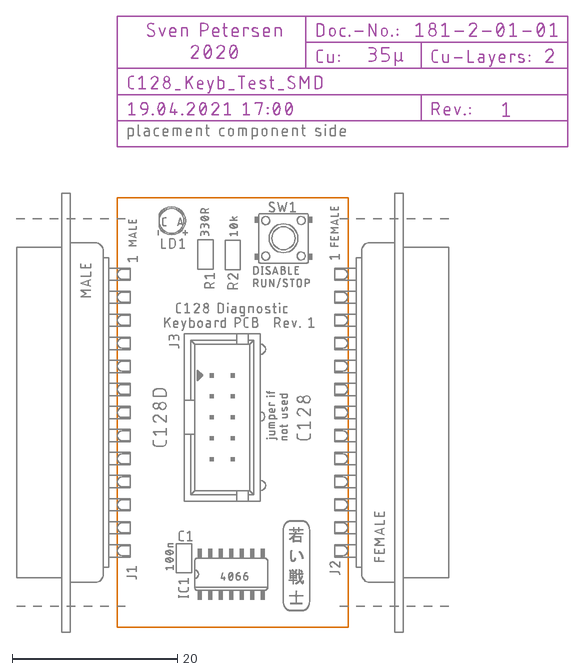
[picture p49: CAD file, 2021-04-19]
Diag586220_Harness/C128_Keyboard_PCB/SMD_Rev. 1/dxf/C128_Keyb_Test_SMD.dxf
66.9 x 74.7

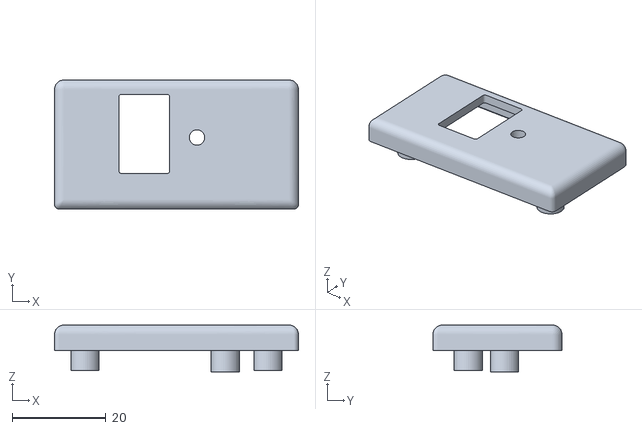
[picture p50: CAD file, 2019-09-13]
Diag586220_Harness/Case_3D_Data/Cassette Port/Rev. 0/STL/top shell CP.stl
52.0 x 27.5 x 10.0

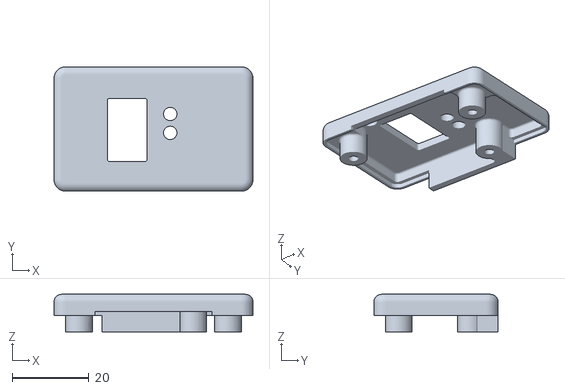
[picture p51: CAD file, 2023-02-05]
Diag586220_Harness/Case_3D_Data/Cassette Port/Rev. 1.0/STL/diag cp-top shell.stl
52.0 x 32.5 x 9.80

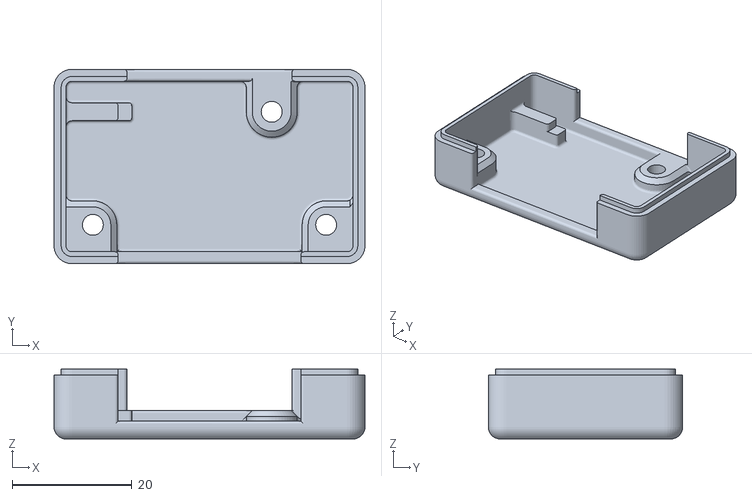
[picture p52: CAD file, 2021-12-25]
Diag586220_Harness/Case_3D_Data/Cassette Port/Rev. 1.1/stl/diag cp bottom shell.stl
52.0 x 32.5 x 11.7

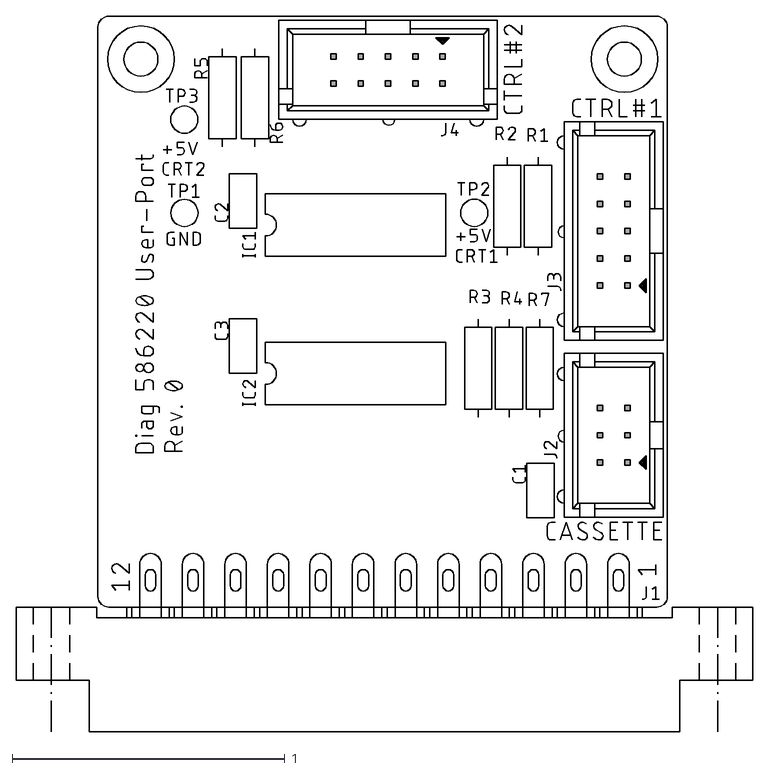
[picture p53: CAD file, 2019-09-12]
Diag586220_Harness/Case_3D_Data/User Port/Rev. 0/dxf/C64_Userport_Test.dxf
2.70 x 2.62

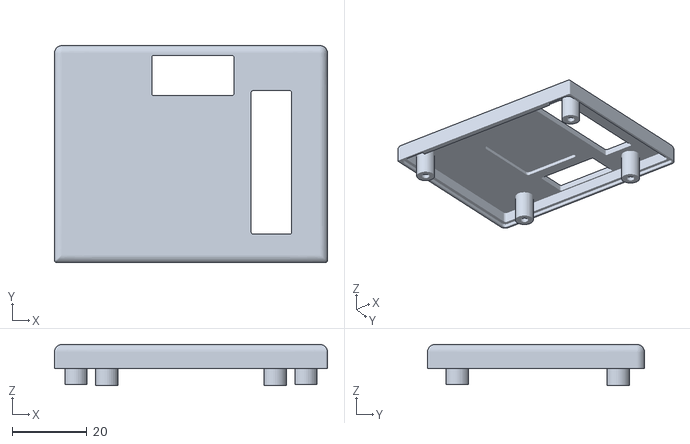
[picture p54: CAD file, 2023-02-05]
Diag586220_Harness/Case_3D_Data/User Port/Rev. 0/stl/top shell UP.stl
73.0 x 58.0 x 11.0

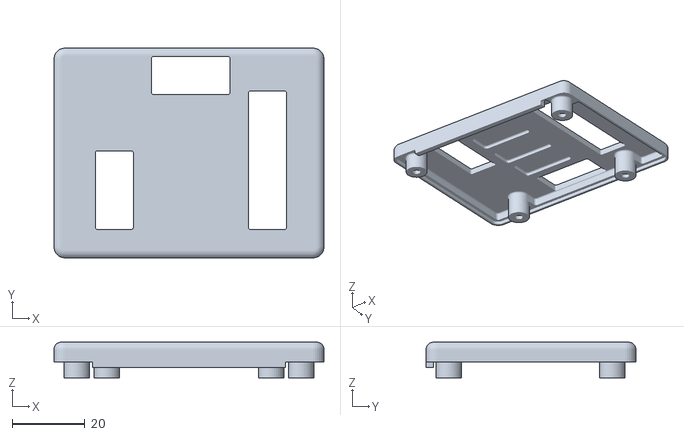
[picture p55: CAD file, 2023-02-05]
Diag586220_Harness/Case_3D_Data/User Port/Rev. 1/Rev. 1.0/STL/diag_up_top.stl
74.0 x 57.5 x 9.80

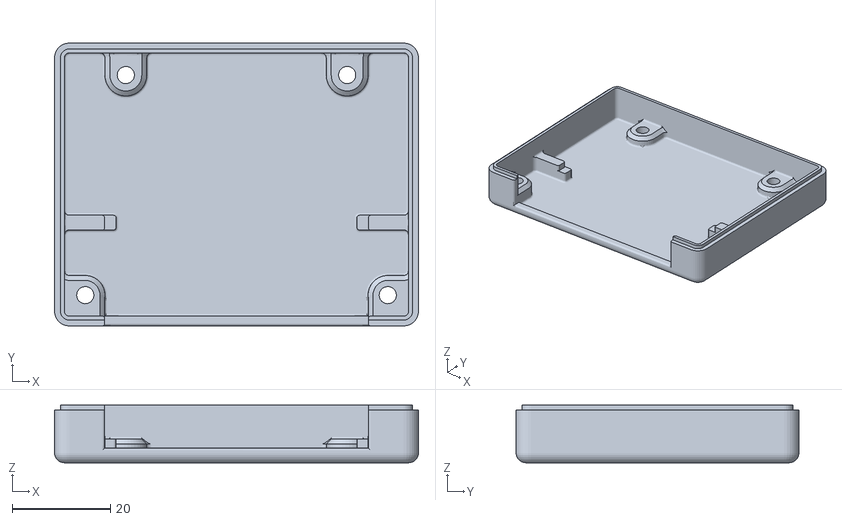
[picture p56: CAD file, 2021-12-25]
Diag586220_Harness/Case_3D_Data/User Port/Rev. 1/Rev. 1.1/stl/diag_up_bottom.stl
74.0 x 57.5 x 11.7

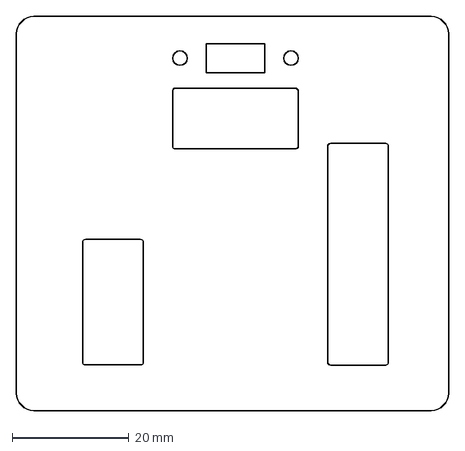
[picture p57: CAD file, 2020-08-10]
Diag586220_Harness/Case_3D_Data/User Port/Rev. 2 (SX-64)/User Port SX64/dxf/top_UP_SX64.dxf
74.0 x 67.5 mm

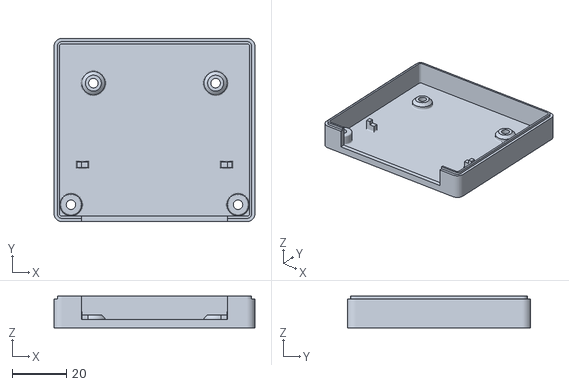
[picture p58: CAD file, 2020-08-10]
Diag586220_Harness/Case_3D_Data/User Port/Rev. 2 (SX-64)/User Port SX64/stl/diag_up_bottom_SX-64.stl
74.0 x 67.5 x 11.7

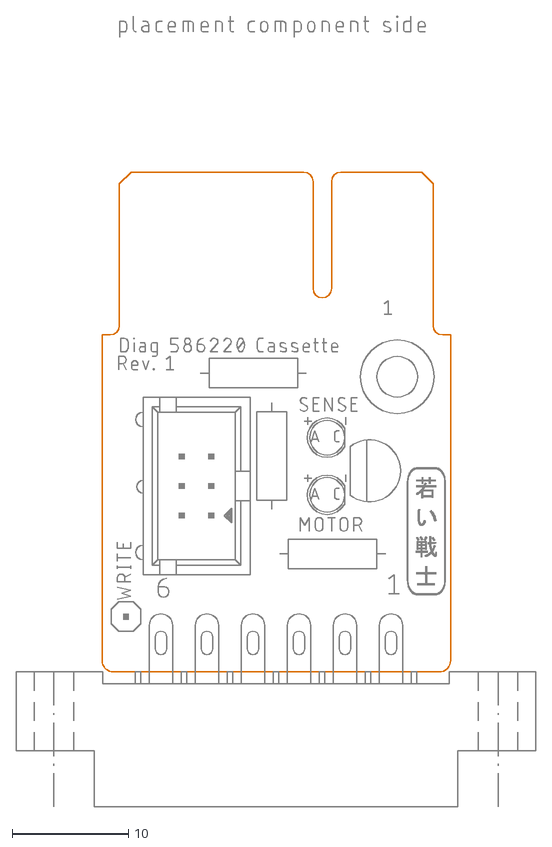
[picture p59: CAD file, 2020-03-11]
Diag586220_Harness/Diag586220_Cassette_Port/Rev.1/dxf/Diag_586220_Cassette.dxf
44.7 x 68.0

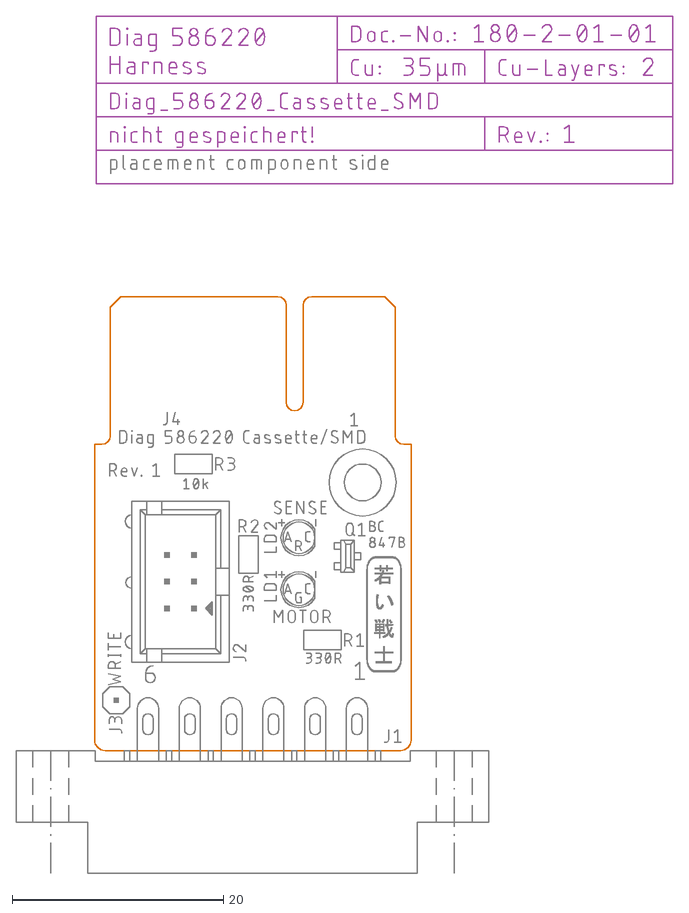
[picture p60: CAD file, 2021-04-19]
Diag586220_Harness/Diag586220_Cassette_Port/SMD_Rev.1/dxf/Diag_586220_Cassette_SMD.dxf
62.2 x 81.2

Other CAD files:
Diag586220_Harness/Case_3D_Data/User Port/Rev. 3/STL/diag_up_top_noVM_SX.stl
Diag586220_Harness/Diag586220_Keyboard_ext/Rev. 0/dxf/C64_Keyb-Test-ext.dxf
Diag586220_Harness/Diag586220_Keyboard_ext/Rev. 1/dxf/C64_Keyb-Test-ext.dxf
Diag586220_Harness/Diag586220_User_Port/Rev.3/AutoSketch/UP-KEYB.DWG
Diag586220_Harness/Case_3D_Data/Cassette Port/Rev. 0/Fusion 360/Diag_CP v4.f3d
Diag586220_Harness/Case_3D_Data/Cassette Port/Rev. 0/Fusion 360/Diag_CP v7.f3d
Diag586220_Harness/Case_3D_Data/Cassette Port/Rev. 0/Fusion 360/Diag_UP v10.f3d
Diag586220_Harness/Case_3D_Data/Cassette Port/Rev. 0/STL/bottom shell CP.stl
Diag586220_Harness/Case_3D_Data/Cassette Port/Rev. 0/dxf/top shell CP.dxf
Diag586220_Harness/Case_3D_Data/Cassette Port/Rev. 1.0/Fusion 360/Diag_CP_PCB_v1 v16.f3d
Diag586220_Harness/Case_3D_Data/Cassette Port/Rev. 1.0/STL/diag cp bottom shell.stl
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

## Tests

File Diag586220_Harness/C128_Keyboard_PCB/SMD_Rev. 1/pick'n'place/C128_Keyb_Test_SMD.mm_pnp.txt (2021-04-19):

Pick'n'place coordinates exported from C128_Keyb_Test_SMD.brd on 19.04.2021 17:19

Value	Name	Footprint	x(mm)	y(mm)	theta	Side
100n	C1	0805	8.096	3.334	90	top
4066D	IC1	SO14	13.811	1.399	0	top
DB25M/EDGE	J1	DB25M-EDGE	0.000	21.000	270	top
DB25F/EDGE	J2	DB25F-EDGE	28.000	21.000	90	top
	J3	2X05WV	12.730	20.414	270	top
	LD1	3MM	6.585	44.226	180	top
330R	R1	0805	10.713	40.164	270	top
10k	R2	0805	14.005	40.083	270	top
JTP-1130	SW1	JTP-1130	20.148	42.119	0	top
	U$8	2LAYER	2.223	-3.810	90	top
	U$9	PCB-TITLE/	0.000	53.181	0	top
	U$10	SVEN_TAG	21.749	2.540	0	top
OPEN_SOURCE_HW	U$20	OPENHW	22.384	7.461	0	bot
	U$21	SMD_REF_R1MM	4.128	-2.540	0	top
	U$22	SMD_REF_R1MM	23.495	42.386	0	top

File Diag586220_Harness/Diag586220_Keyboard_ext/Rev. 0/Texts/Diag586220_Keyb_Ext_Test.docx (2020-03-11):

Diagnostic 586220 Harness - Keyboard Dongle Extended Rev. 0

Testing

The Rev. 0 prototype was not functional and required a modification to work properly.

R2 had to be changed from 10k to 1k and an additional resistor (R4) had to be inserted between the pull up and the base of Q1.

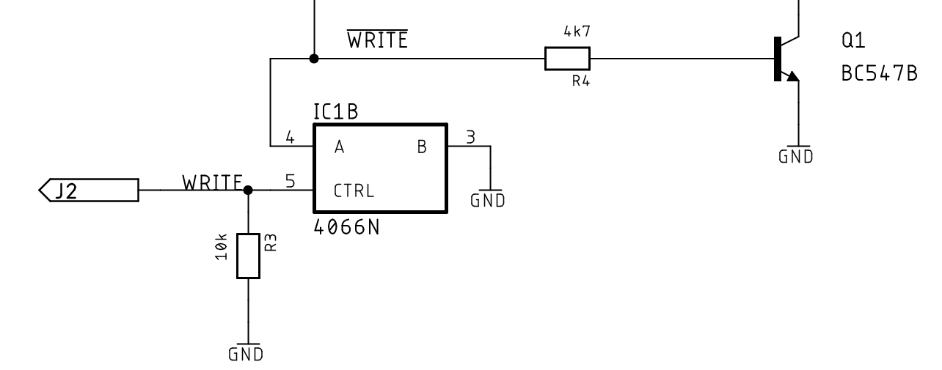
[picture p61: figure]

Figure 1: Required modification

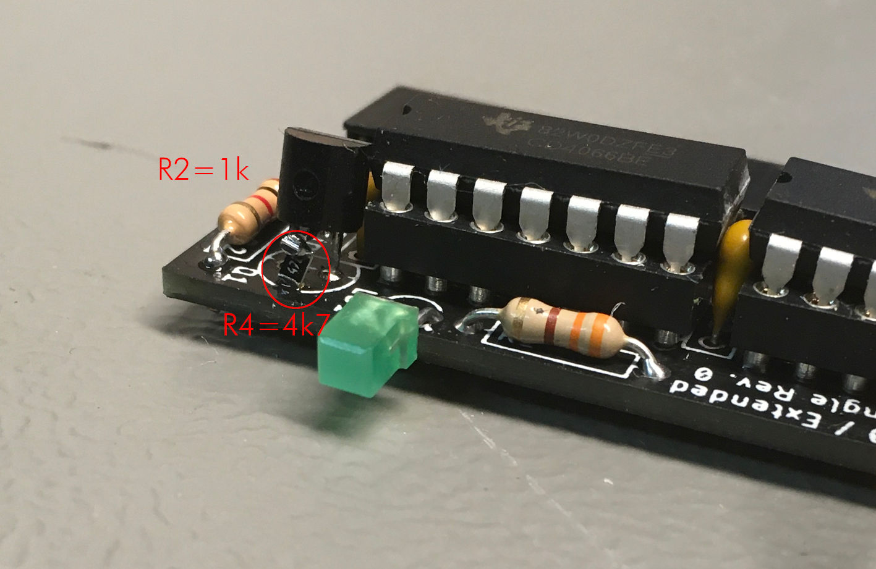
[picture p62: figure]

Figure 2: Modified Board Rev. 0

The modified Extended Keyboard Dongle was connected to a C64 (ASSY250469) instead of a Keyboard Dongle Rev. 0. The rest of the Diagnostic Harness was also connected to the C64. J2 (for the WRITE signal) was left open. The diagnostic Rev. 586220 test was running as usual, the keyboard and the control port were reported “OK”.

The WRITE signal was connected to J2. The test was repeated, both, the Control Ports and the Keyboard were reported “OK”.

IC2 was extracted from the socket (= four missing keyboard feedbacks). The test was repeated and the keyboard was reported “BAD”. IC2 was re-installed.

IC1 on the User Port Dongle was extracted from the socket (= four missing control port feedbacks). The test was repeated and the control ports were reported “BAD”.

WRITE was disconnected from the Extended Keyboard Dongle. The test was repeated and the Control Ports were reported “OK” (which is a false OK, because the feedbacks are missing). IC1 was reinstalled on the User Port Dongle. WRITE was connected to J2.

Finally, a 3 hours test run was performed, no problems were reported.

The modified Extended Keyboard Dongle is fully functional. A PCB revision is required.

Diag586220_Keyb_Ext_Test.docx 10.03.2020 20:27 Drafted by Sven Petersen Page 2 of 2 Doc.-No.: 143-6-02-00

Diag586220_Keyb_Ext_Test.docx 10.03.2020 20:27 Drafted by Sven Petersen Page 1 of 1 Doc.-No.: 143-6-02-00

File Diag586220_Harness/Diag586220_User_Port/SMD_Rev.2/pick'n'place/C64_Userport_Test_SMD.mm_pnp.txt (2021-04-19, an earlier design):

Pick'n'place coordinates exported from C64_Userport_Test_SMD.brd on 19.04.2021 12:35

Value	Name	Footprint	x(mm)	y(mm)	theta	Side
100n	C1	0805	41.201	10.840	270	top
100n	C2	0805	18.574	39.846	90	top
100n	C3	0805	18.574	29.369	90	top
100n	C4	0805	18.733	17.304	90	top
	DRL1	BOHR3,2	4.000	51.000	0	top
	DRL2	BOHR3,2	49.000	51.000	0	top
4066D	IC1	SO14	24.289	37.782	0	top
4066D	IC2	SO14	24.289	27.146	0	top
4066D	IC3	SO14	24.289	15.240	0	top
C64-USERPORT	J1	USERPORT	26.670	0.000	180	top
	J2	2X03WV	48.000	16.000	90	top
	J3	2X05WV	48.000	35.000	90	top
	J4	2X05WV	27.000	50.000	180	top
	J5	2X05WV	6.033	18.574	90	top
	J6	1X03	41.593	49.054	180	top
	JP1	CP_CL	42.069	46.196	0	top
110k	R1	0805	40.958	37.306	270	top
110k	R2	0805	38.100	37.306	270	top
316R	R3	0805	35.401	22.225	270	top
150R	R4	0805	38.259	22.225	270	top
110k	R5	0805	11.748	49.483	270	top
110k	R6	0805	14.605	49.483	270	top
0R	R7	0805	41.116	22.225	270	top
10k	R8	0805	18.574	25.400	90	top
L1,2_R	TP1	1,2MM_R	9.476	37.488	0	top
	U$15	SVEN_TAG	4.763	35.878	0	top
	U$17	2LAYER	9.207	49.213	90	top
	U$18	PCB-TITLE/	0.000	64.000	0	top
OPEN_SOURCE_HW	U$20	OPENHW	9.525	47.149	270	bot
	U$21	SMD_REF_R1MM	3.175	46.990	0	top
	U$22	SMD_REF_R1MM	51.276	4.921	0	top

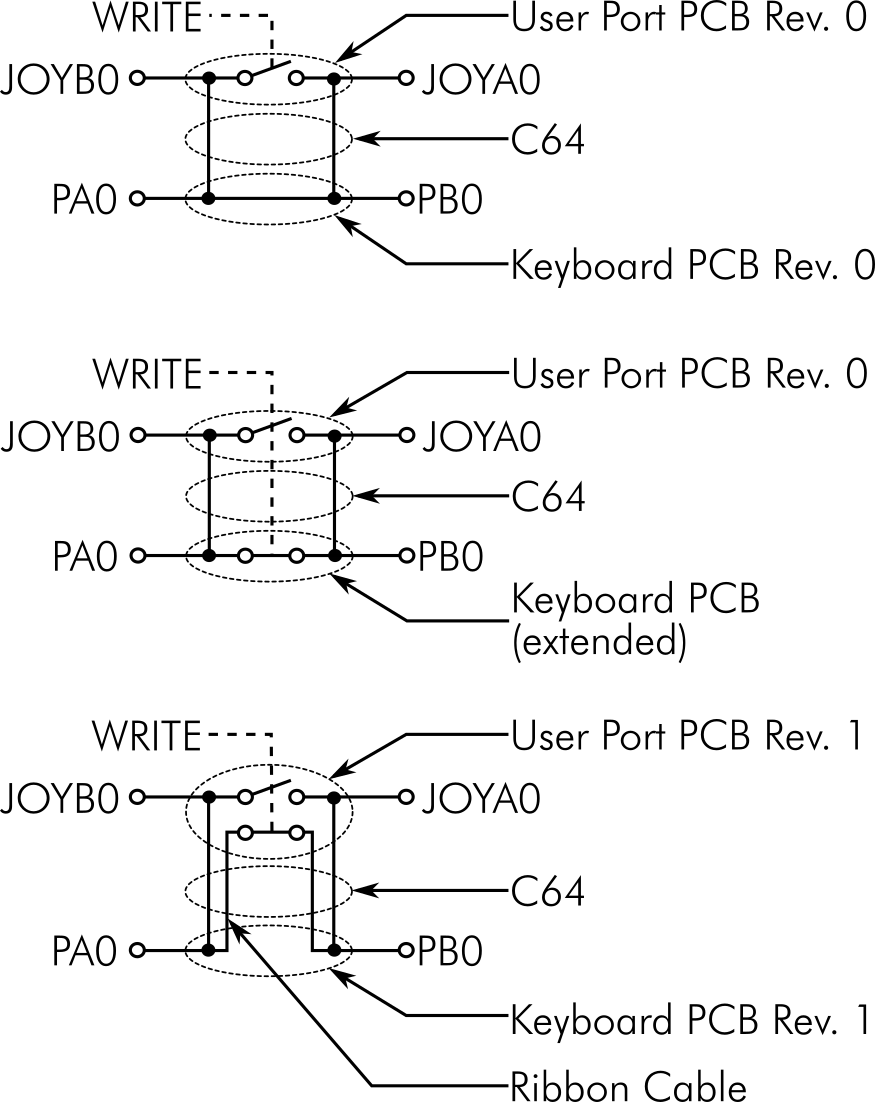
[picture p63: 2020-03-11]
Diag586220_Harness/Diag586220_Keyboard_ext/Rev. 0/pictures/Test_situation.png

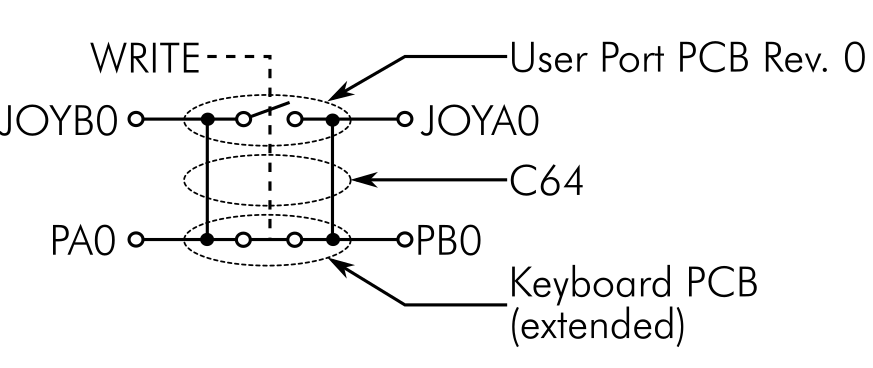
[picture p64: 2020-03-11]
Diag586220_Harness/Diag586220_Keyboard_ext/Rev. 1/pictures/Test_situation_ext.png

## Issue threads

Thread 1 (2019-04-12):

Resistor values for R1 / R2 / R5 / R6 and R3?

modeler, 2019-04-12:
Firstly, thank you Sven for sharing this. I'm looking to build one of these myself but when verifying the resistor values I think I found something odd. The documentation says R3 is a 320 ohm resistor, however in the photo it looks like something different (the others check out).

Looking at [Jerzy Sobola's schematic on Zimmers.net](http://www.zimmers.net/anonftp/pub/cbm/schematics/cartridges/c64/diag/diag-c64-8k.gif) R3 is a 300 ohm resistor rather than 320 ohm, he also uses 100k resistors for R1, R2, R5 and R6 rather than 120k.

I'd be very grateful if you or anyone else could help me understand why these are different, thanks in advance.

svenpetersen1965, 2019-04-12:
Hi,
I have used a 316 Ohm resistor instead of 320. I guess, 330R works as well. Sorry, I should update the part list. The 120k resistors are used to determin the value, the sid returns for potx and poty for both ports. I would not change it. It works fine, here.

Mit freundlichen Grüßen/Kind regards
Sven Petersen

Enzianweg 16
83052 Bruckmühl
Germany

Fon: +49 8062 728125
Email: sven@guitarsite.de
Web: http://www.guitarsite.de

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

modeler, 2019-04-12:
Legend, thanks for explaining and for getting back to me so quickly.

Closed 2019-04-12.

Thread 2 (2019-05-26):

DigiKey BOM for North American Part Numbers

ChrisToast89, 2019-05-26:
Sourcing assistance part numbers from N. American vendor(s).

[Diag Harness BOM (N.American DIGIKEY PNs).xlsx](https://github.com/svenpetersen1965/C64-Diagnostic-Rev.-586220-Harness/files/3221005/Diag.Harness.BOM.N.American.DIGIKEY.PNs.xlsx)

ChrisToast89, 2019-05-26:
Note for Sven: I ended up sourcing SMT LED and caps out of preference since the pad layouts allowed me the option. However, traditional through-hole resistors were used.

svenpetersen1965, 2019-11-07:
I will add your file to the repository.

Closed 2019-11-07.

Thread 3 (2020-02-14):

Paddle test indicates false failure on some boards

dgoswick, 2020-02-14:
I ran into a board that kept failing the paddle test and insisted that either the SID or U28 (4066) was bad.  The SID was known good, and tested fine in another board.  I replaced U28, but the problem persisted.  Reading through the original diagnostic cartridge manual, I noticed that Commodore used 110k resistors to pull the 4 POT lines up to +5v.  The diagnostic harness here uses 120k resistors (R1,R2,R5,R6) on the user port to achieve the same.  On a hunch, I changed these resistors on the user port of the harness to 110k.  The diagnostic test is now passing every time without fail for this board.

Thank you Sven for all of your contributions to the retro community!
Dan Goswick

svenpetersen1965, 2020-02-14:
Thanks for the hint. I will take care of that soon.

svenpetersen1965, 2020-02-14:
Done.

Closed 2020-02-14.

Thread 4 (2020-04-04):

Modified case files

Jeff-Birt, 2020-04-04:
[Diagnostic_Harness_Case_Mods.zip](https://github.com/svenpetersen1965/C64-Diagnostic-Rev.-586220-Harness/files/4431816/Diagnostic_Harness_Case_Mods.zip)

Attached are modified case designs for the cassette and user port. The two screw posts are moved back and holes added for screws from card edge connector. This should work for both 3mm and #4-40 screws with nuts on the inside.

Also a 'sleeve' to protect the pass through edge connector for cassette port was added. It has keying bumps inside which just add enough friction to keep it in place.

Closed 2020-05-26.

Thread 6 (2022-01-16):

LED is always on on Extended Keyboard Dongle

nharrer, 2022-01-16:
First off. This is a wonderful project. Thank you so much! I had so much fun building it and testing my growing fleet of C64s and 128s.
I also tried the extended Keyboard version with the single wire connection to the cassette board.

Here I noticed that the LED is always on, even when J2 is disconnected. I have placed R5 and removed R3. So it should be off if the jumper is disconnected.

It seems that R1 is too low. Even with the control line (IC1B Pin 4) pulled to low, there is enough current to turn on Q1. I have tried different values for R2 and R4. And I found that it works well if the resistances are raised by a magnitude. R2 = 10k and R4 = 47k. This gives the same well defined ctrl voltage for the high state (about 4,1V) but not enough current to turn on Q1 on the low state.

Here is a list of values that I've tried for R2 / R4 (also attached):
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
_U<sub>J2</sub> is the voltage on Pin 5 of IC1B (the signal from J2)
U<sub>A</sub> is the voltage in Pin 4 of IC1B
U<sub>Q</sub> is the voltage on the base if Q1_

You mentioned in your docs that you started out with R2 = 10k and it didn’t work. I noticed the same thing when R4 = 0. But it works well, if R4 is high enough (at the same ration of R2 / R4 as the current version).

I hope this makes sense. Disclaimer: Electronics is just a hobby of mine. I could be completely on the wrong track.
Regards,
Norbert

[Ext_Keyboard_LED_fault.ods](https://github.com/svenpetersen1965/C64-Diagnostic-Rev.-586220-Harness/files/7877303/Ext_Keyboard_LED_fault.ods)

svenpetersen1965, 2022-01-17:
IC1B is used as an inverter. A High in one Ctrl-Input will switch the "output" Pin 4 to GND on Pin 5. If the on-Resistance of the 4066 is too high, the voltage on Pin4 will not get low enough to switch off the feedbacks and the LED.  My mistake in Rev. 0 was connecting the ctrl input directly to the base of the transistor. The voltage could not get higher tan about 0.7V, which is still low. the ctrl needs to be 3.5V for a valid high signal.

The on resistance is typically 125 Ohm (I just read, that is for 15V supply voltage is can be 470ohms). And the valid LOW level is  1V. Hmm... so my dongle works, but the values are a bit delicate. Which IC brand did you install?

I have played a bit with the values. R2 should be good with 3k3 and R4 with 10k. Are you able to check these values? I cannot find my prototype right now.

nharrer, 2022-01-18:
Thanks for the explanation. I didn't realize that R<sub>on</sub> of the 4066 is quite high.

I have no idea what brand I have. Probably bought on Aliexpress:
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

I measured I<sub>A</sub> and V<sub>A</sub> at Pin 4 when IC1B is on. Which is 1.32mA and 0.7V. That results in about 260Ω. Which is quite higher than 125.

And I tried the values R2=3k3 and R4=10k. That works! That ctrl signal high state is 3.8V in that case.
I stuck it onto three different C64s and it looks good so far.

svenpetersen1965, 2022-02-21:
Good, that it works, now. Issue closed.

Closed 2022-02-21.

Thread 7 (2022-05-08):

Control port shows bad on Rev2 harness

Obiwantje, 2022-05-08:
Sven, got several of your test Harness builds (in all versions) - but this latest non-SMD version keeps on giving me  bad control port on all C64 boards (I have many) - I have replaced the 316Ohm resistor with a pot so I could dial in exactly 316, but to no avail - I have no clue as to why I can't seem to get this version of the harness to not show this (consistent) issue on all boards.....any ideas of what i could try out?

svenpetersen1965, 2022-05-08:
That could have several reasons.
1. the ribbon cable(s) might be bad. I have experienced problems with one (rainbow) ribbon cable. It was not in the 1.27mm pitch. Adrian Black had this issue, too.
2. The 110k resistors are not 110k. They are used to simulate the pots and if the result is not within a certain  range, the control port is reported bad.
I don’t believe, that it is an issue with the 316 ohm resistor. The value is not critical. I have picked it, because it was closest to the 320 ohms from the original harness schematics. 330 ohms have proved to work well.
Greetings,
Sven

svenpetersen1965, 2022-05-08:
I don’t believe, it is matter of the harness circuit, itself. I have built dozens and they all worked. retrorewind.ca is mass-producing them. Without any issue.

Obiwantje, 2022-05-09:
Sven - MANY thanks for your constructive pointers and guidance, I can confirm that, just like Adrian, I had a pitch issue!

Confirmed working and fixed - Case closed!

Thanks again for your great work!

Closed 2022-05-09.

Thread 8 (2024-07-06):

Harness Rev.3 THT R3 Value

venice1200, 2024-07-06:
Hi,
das hier ist kein Issue, mehr ein Hinweis zu R3 in der Rev. 3.0 THT Variante.

Ich baue mir gerade Dein Harness in der o.g. Rev. auf und habe bemerkt
das in der Rev. 3.0 Doku und auf dem PCB verschiedene Werte angegeben sind.

Gefunden habe ich:
- Auf dem PCB Rev. 3.0 steht 316R
- In der Projekt Doku werden an mehreren Stellen 330R angegeben (Motor Signal, Bestückung)
- Im "Bill of Material Rev. 3.0" sind wider  316R gelistet

Ich denke der Unterschied zwischen 316 und 330 Ohm ist vernachlässigbar,
vielleicht kannst Du das aber noch in die Doku mit aufnehmen.

Danke das Du das hier alles frei zur Verfügung stellst.

Viele Grüße
Lars

P.S. Das "Issue" kannst Du gerne gleich wieder schliessen.

svenpetersen1965, 2024-07-06:
Original war da 316Ω drin. Aber 330Ω funktionieren genau so. Da ich einen 330Ω als Vorwiderstand für die LED habe, und das einfacher zu bekommen ist, habe ich es auf 330Ω umgestellt. Aber du kannst beide Werte an beiden Stellen verwenden. Ich muss mir die Doku noch einmal ansehen. Danke für den Hinweis.
Sven

svenpetersen1965, 2024-07-18:
I have found an obsolete BOM in the pdf. The Excel BOM v3.0 was up to date. The top silk screen also contained the old value. This is now fixed.

Closed 2024-07-18.

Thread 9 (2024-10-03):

Dead link

Obiwantje, 2024-10-03:
"Now, a 3D printed case for the user port and the cassette donge is designed and the stl files etc. are available here.

Diagnostic Harness with cases"

Link in readme to: [https://github.com/svenpetersen1965/C64-Diagnostic-Rev.-586220-Harness/blob/master/Diag586220_Harness/Case%20(3D%20print)/Rev.%200/Picture/2649_Harness_with_case.JPG]
is dead

svenpetersen1965, 2024-10-03:
Thanks for the hint, I have fixed it.

Closed 2024-10-03.

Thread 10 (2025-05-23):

ribbon cable lengths

mightyohm, 2025-05-23:
Are the ribbon cable lengths in the cable drawings intended to be the finished length of the cable or the length of the ribbon cable itself before adding the connectors? For example, for the cassette port ribbon cable, should I cut the ribbon cable to 70mm before adding the IDC connectors, or should I increase the length of the cable by 20-30mm so that the finished cable length is 70mm?

svenpetersen1965, 2025-05-23:
The cable lengths are given rather generously. If you follow the lengths specified in the cable diagrams, you’ll be on the safe side.

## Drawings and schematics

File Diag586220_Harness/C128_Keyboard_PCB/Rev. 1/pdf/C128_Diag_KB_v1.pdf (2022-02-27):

# Project Documentation

## C128 Diagnostic – Keyboard PCB

## Project number: 145

## Revision: 1

## Date: 15.05.2020


C128_Diag_KB_ModD.docx | | 27.02.2022 12:15
Drafted by Sven Petersen | Page 1 of 3 | Doc.-No.: 145-6-01-01

### C128 Diagnostic – Keyboard PCB Rev. 1

### Module Description

## Introduction

This is the keyboard Dongle (PCB) for the Commodore C128 Diagnostic Rev. 588121. The required harness is identical to the C64 Diagnostic Rev. 586220 harness, except the keyboard PCB. The C64 harness can be found here:

https://github.com/svenpetersen1965/C64-Diagnostic-Rev.-586220-Harness

The C128DCR does not provide +5V at the keyboard connector. Thus, this C128 keyboard dongle does not work, since the IC requires supply voltage.
A part of the keyboard scan signals are shared with the control ports. To prevent a false “OK”
while testing these, the feedbacks can be opened. The required analog switches are implemented on the user port PCB (Rev. 1) of the said C64 harness. The connection to the user port PCB is provided by a ribbon cable, which can be connected to the box pin header J3.

In case this feature is not desired or the user port PCB is of an earlier revision, the adjacent pins of J3 can be jumpered with standard jumpers (1-2, 3-4, 5-6, 7-8 and 9-10).

Figure 1: Dimensions of the C128 Diagnostic Keyboard PCB

The footprint of the keyboard connector on the C128 mainboard is for a 90° female DSub-25 connector (for the C128D). A special pin header is populated on the mainboard. It fits a female DSub-25 connector (J2). The pin numbering is in the opposite direction of a normal male DSub-25, though. This results in a discrepancy of the pin numbering of J2, which is correct.
The regular feedbacks are COL0 to ROW0, COL1 to ROW1, … COL7 to ROW7.

C128_Diag_KB_ModD.docx | | 27.02.2022 12:15
Drafted by Sven Petersen | Page 2 of 3 | Doc.-No.: 145-6-01-01

The feedback COL7 to ROW7 mimics a RUN/STOP while power up. This causes the C128 to boot into the monitor program, which is not desired. This can be circumvented by pressing the disable button on this PCB. This causes the analog switch (IC1) to open, which is responsible for this feedback.

## Connectors

Signal | J1 (C128D) | J2 (C128)
GND | 1 | 13
(no pin) | 2 | 12
RESTORE | 3 | 11
+5V | 4 | 10
ROW3 | 5 | 9
ROW6 | 6 | 8
ROW5 | 7 | 7
ROW4 | 8 | 6
ROW7 | 9 | 5
ROW2 | 10 | 4
ROW1 | 11 | 3
ROW0 | 12 | 2
COL0 | 13 | 1
COL6 | 14 | 25
COL5 | 15 | 24
COL4 | 16 | 23
COL3 | 17 | 22
COL2 | 18 | 21
COL1 | 19 | 20
COL7 | 20 | 19
K0 | 21 | 18
K1 | 22 | 17
K2 | 23 | 16
40/80 | 24 | 15
CAPS LOCK | 25 | 14

J3 – box pin header 2x5 circuits

Signal Pin | Pin Signal
COL4 | 1 | 2 | ROW4
COL3 | 3 | 4 | ROW3
COL2 | 5 | 6 | ROW2
COL1 | 7 | 8 | ROW1
COL0 | 9 | 10 | ROW0

C128_Diag_KB_ModD.docx | | 27.02.2022 12:15
Drafted by Sven Petersen | Page 3 of 3 | Doc.-No.: 145-6-01-01

## Links

This PCB is designed based on the following information:

- http://blog.worldofjani.com/?p=164
- http://personalpages.tds.net/~rcarlsen/cbm/c128/SCHEMATICS/
- https://commons.wikimedia.org/wiki/File:C128mobo.jpg?uselang=de

## Revision History

### Rev. 0

- Prototype

### Rev. 1

- PCB Revision: board is now 28mm wide

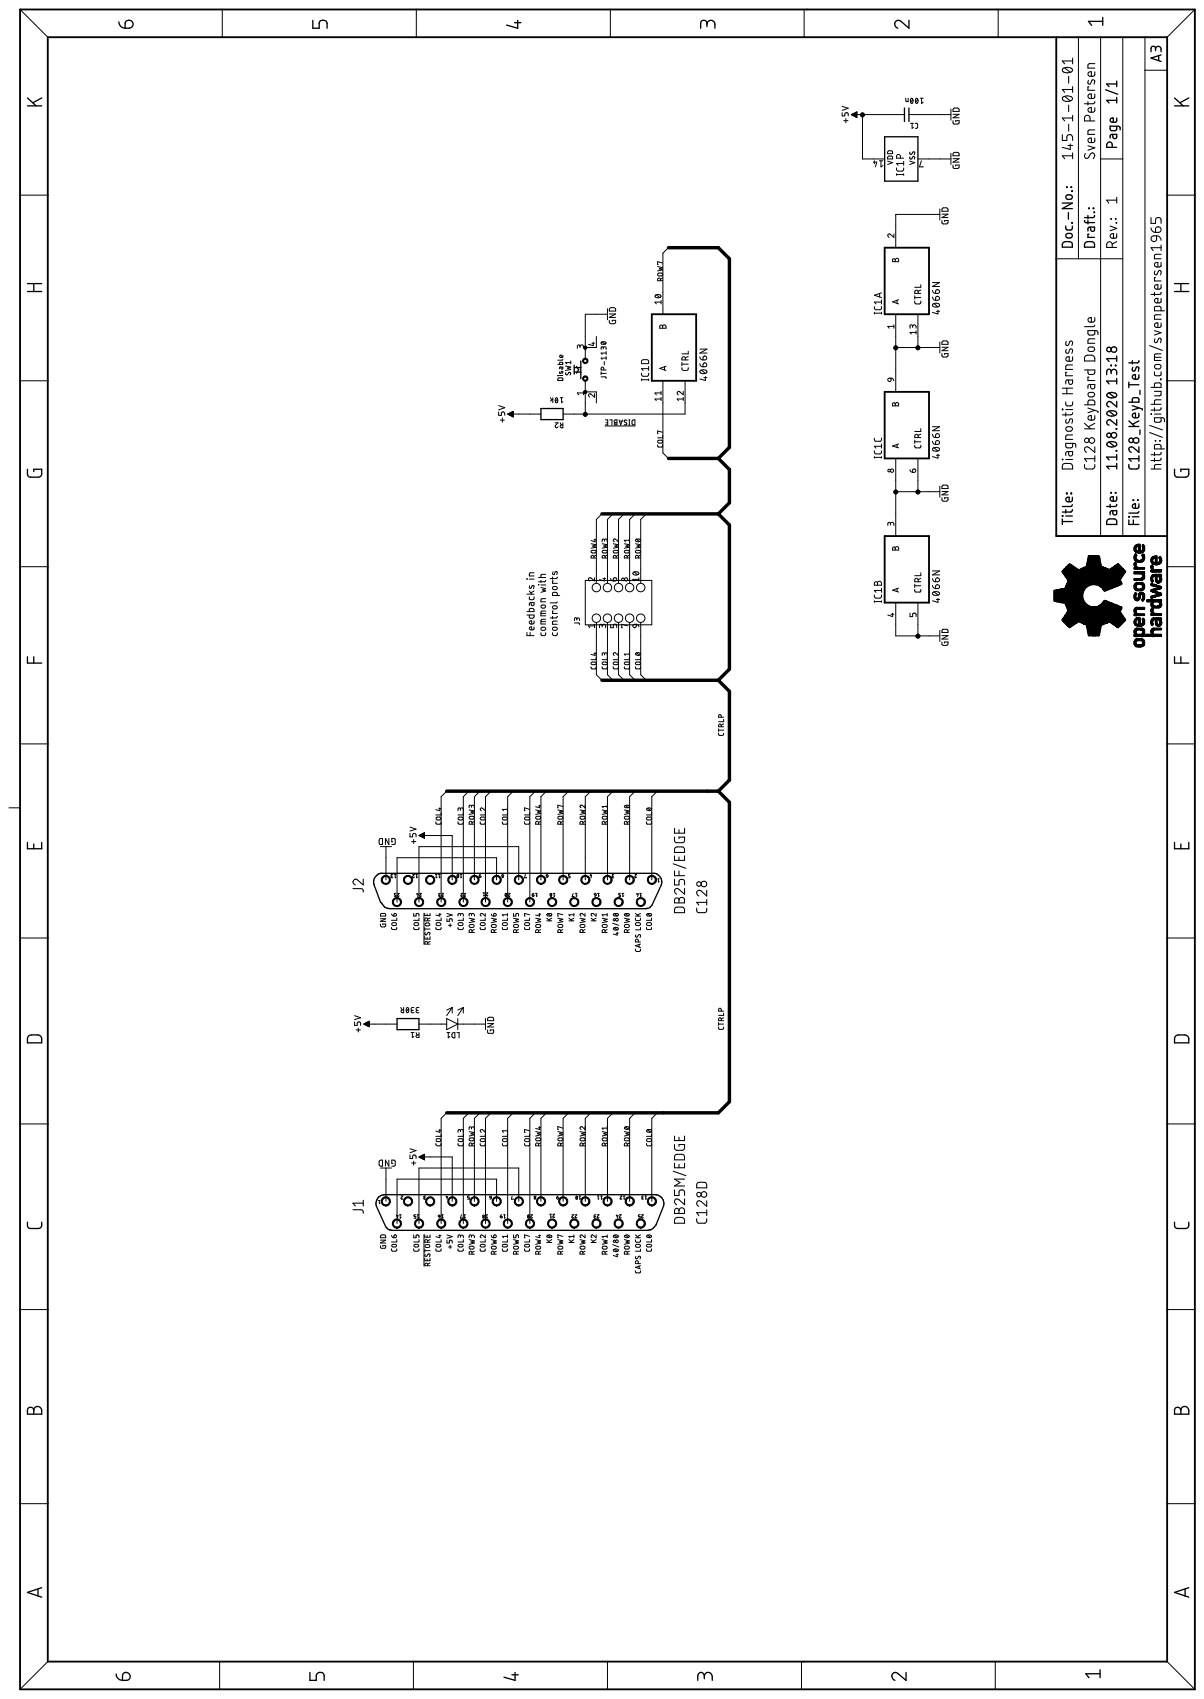
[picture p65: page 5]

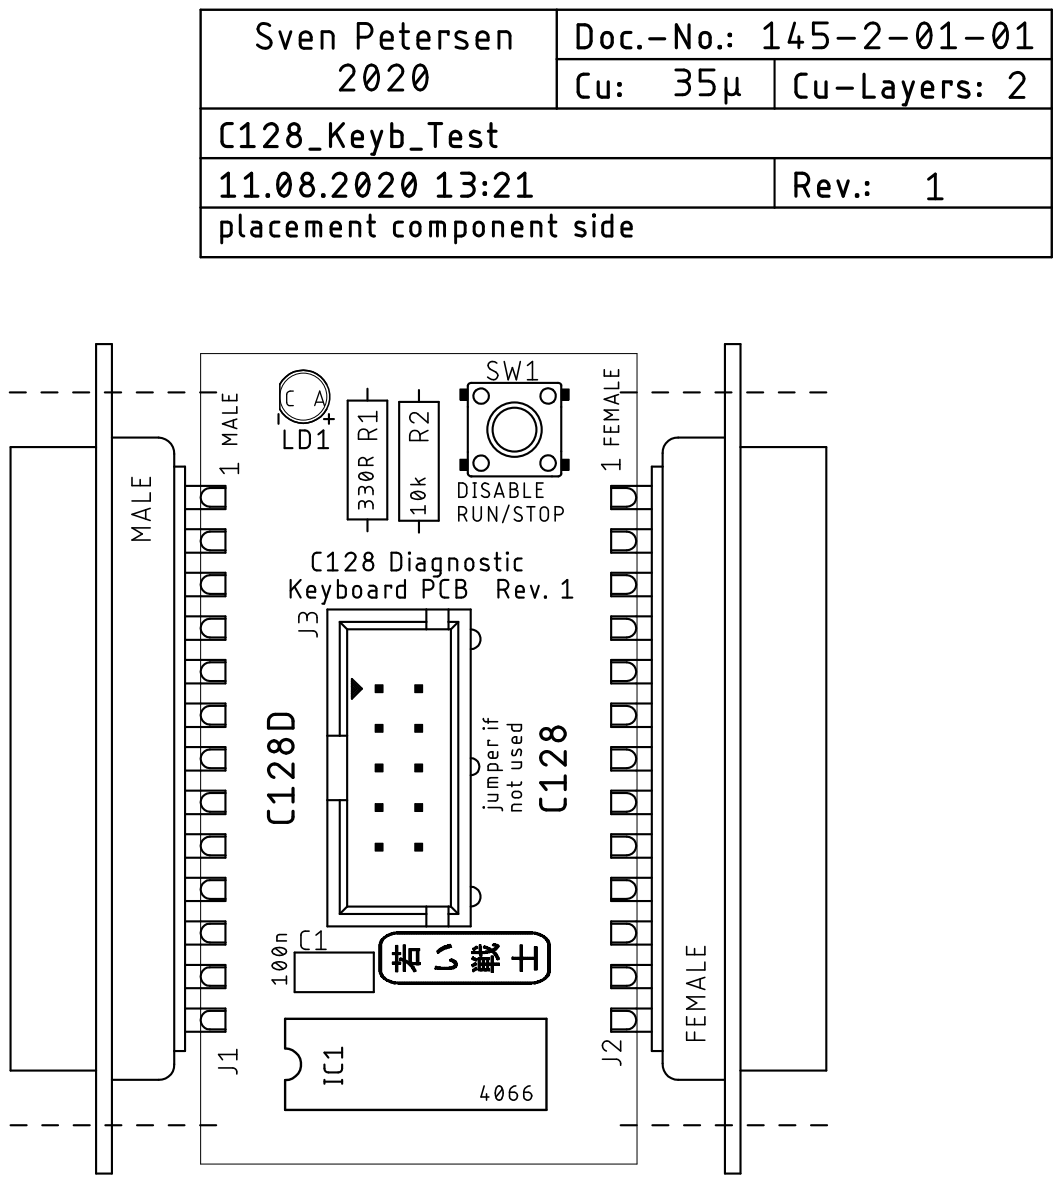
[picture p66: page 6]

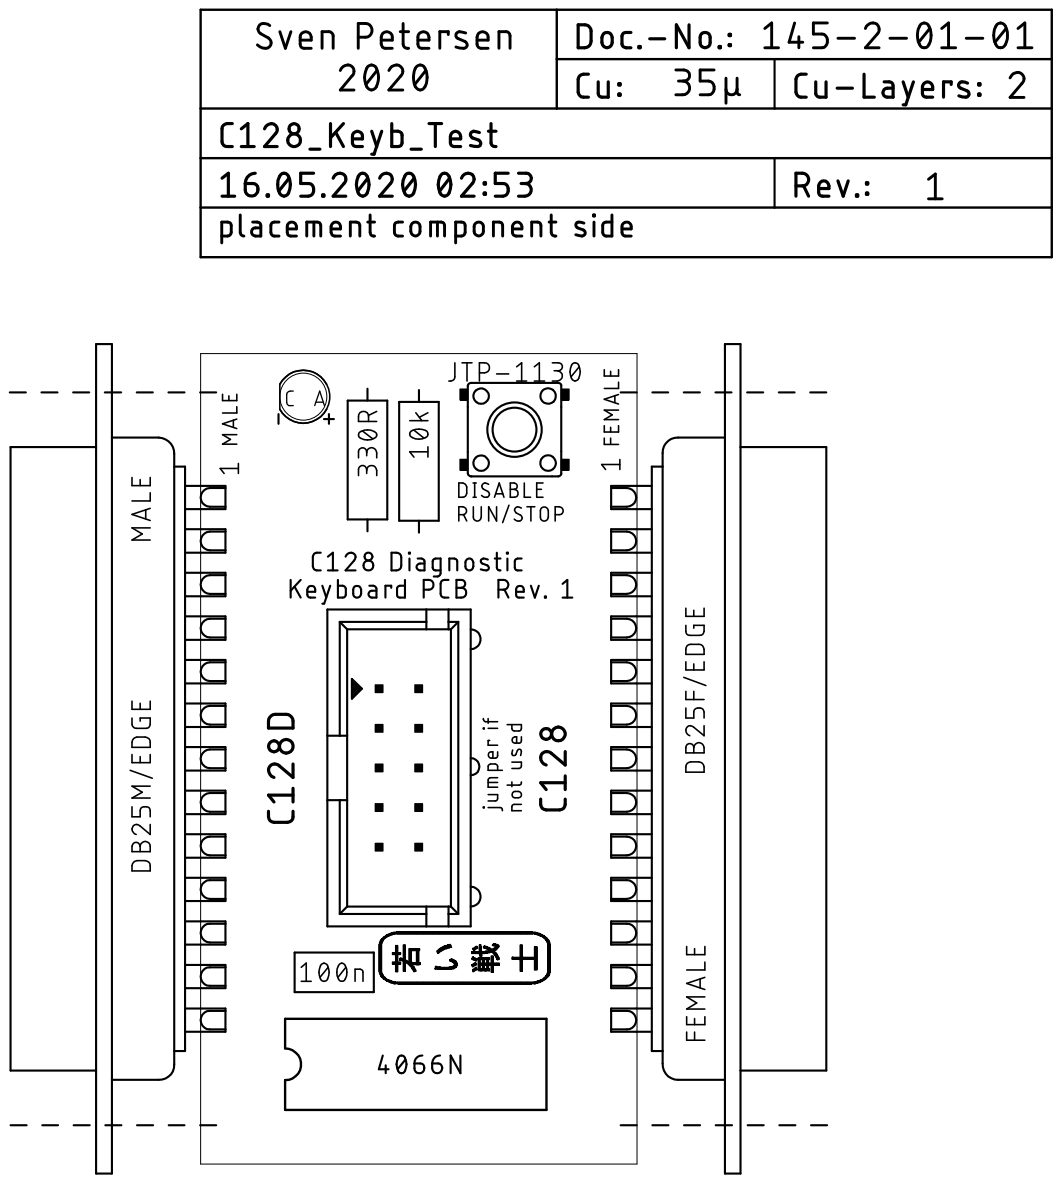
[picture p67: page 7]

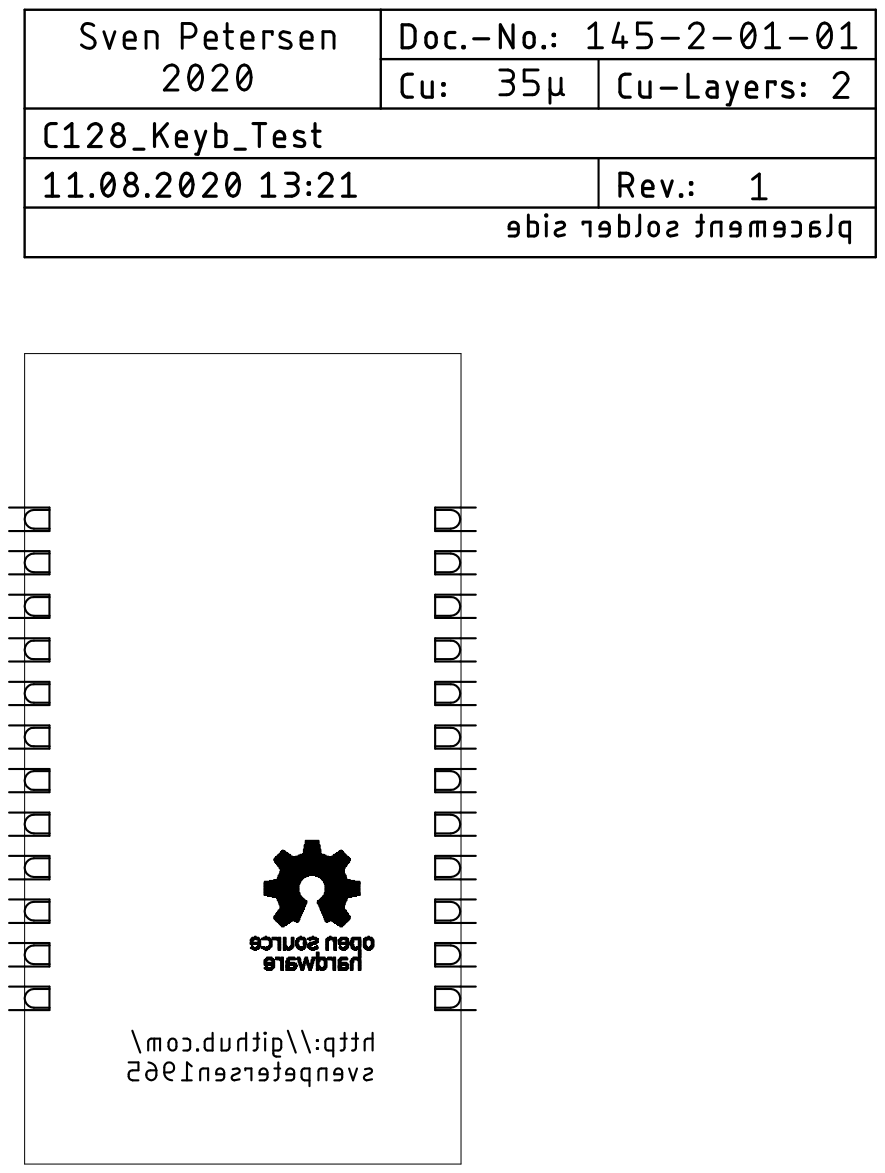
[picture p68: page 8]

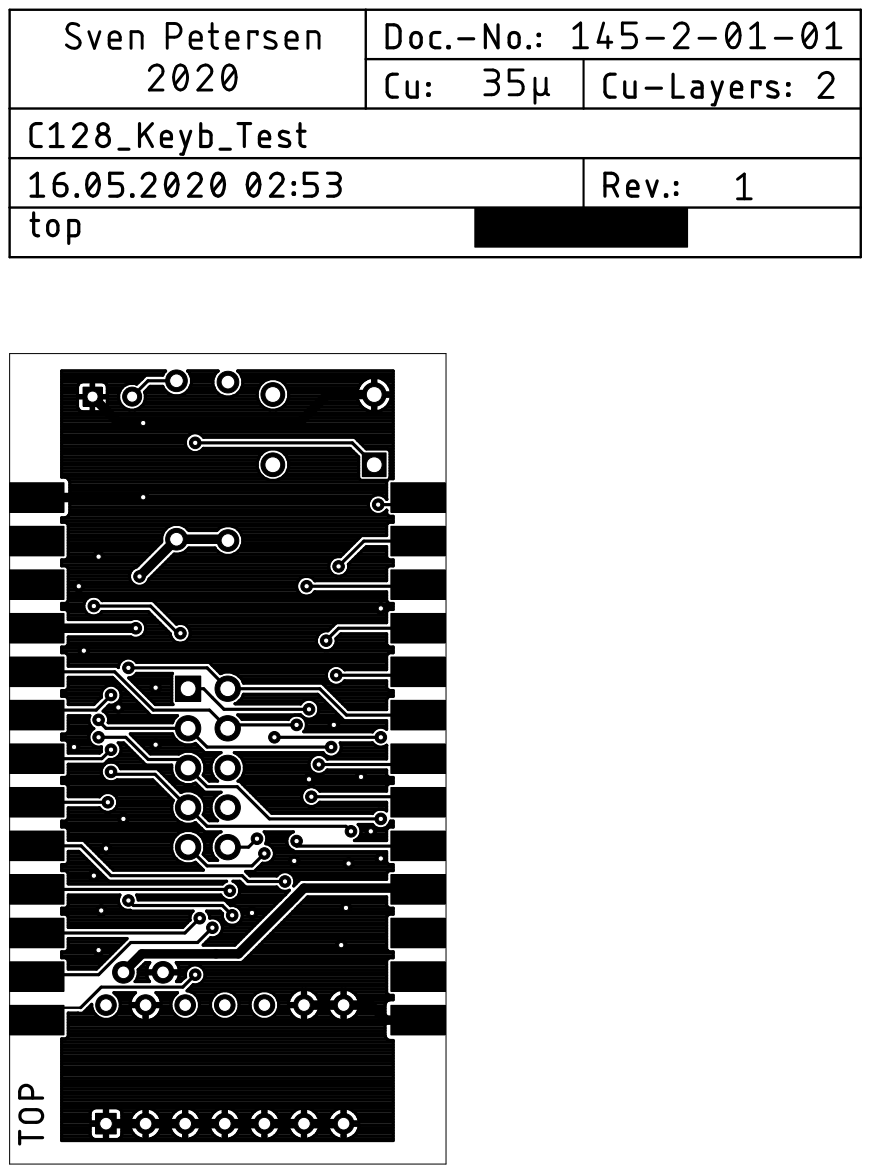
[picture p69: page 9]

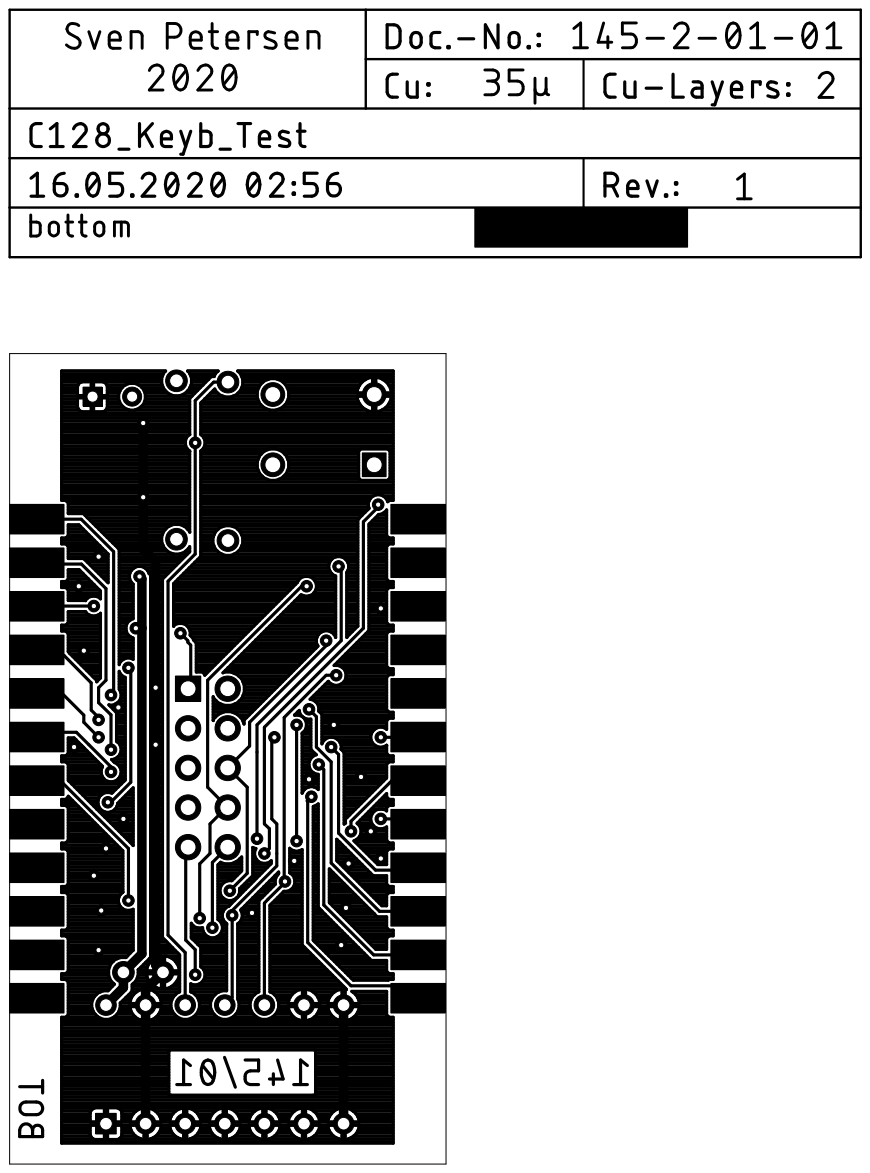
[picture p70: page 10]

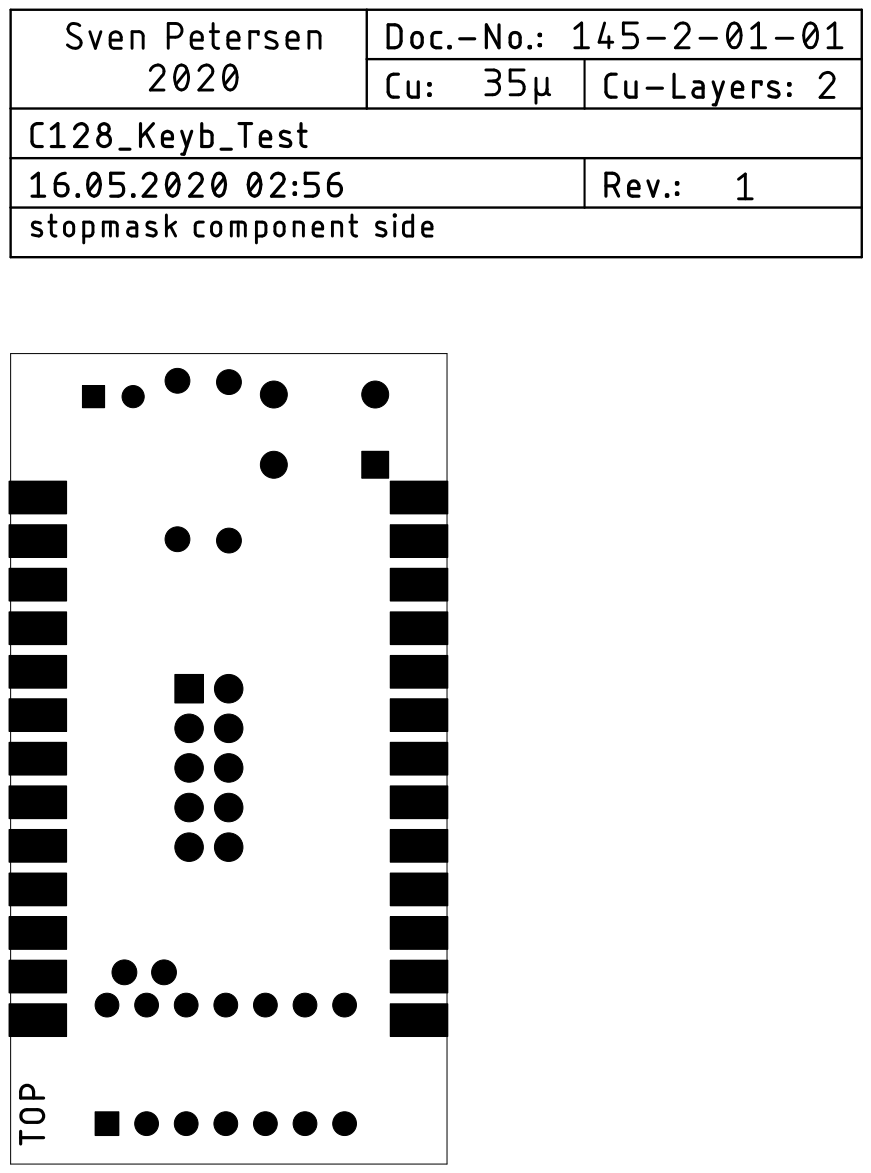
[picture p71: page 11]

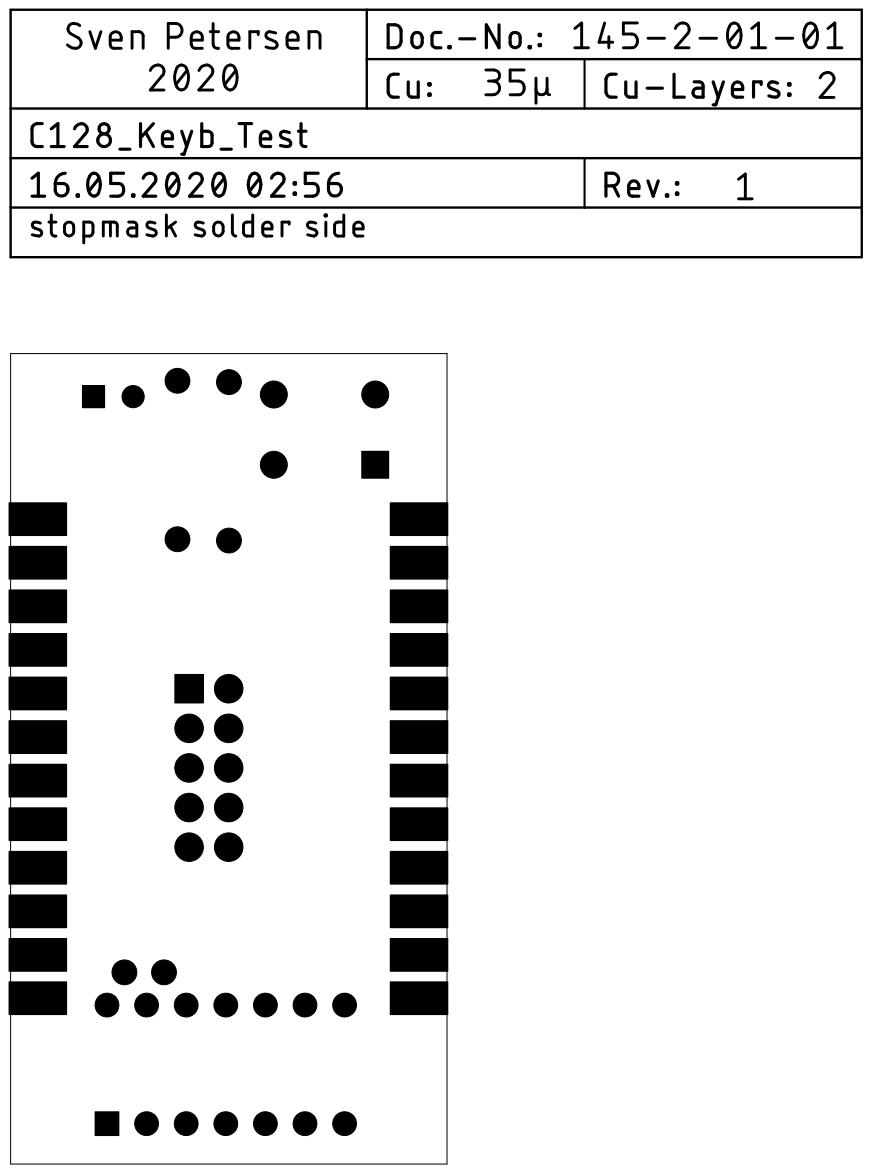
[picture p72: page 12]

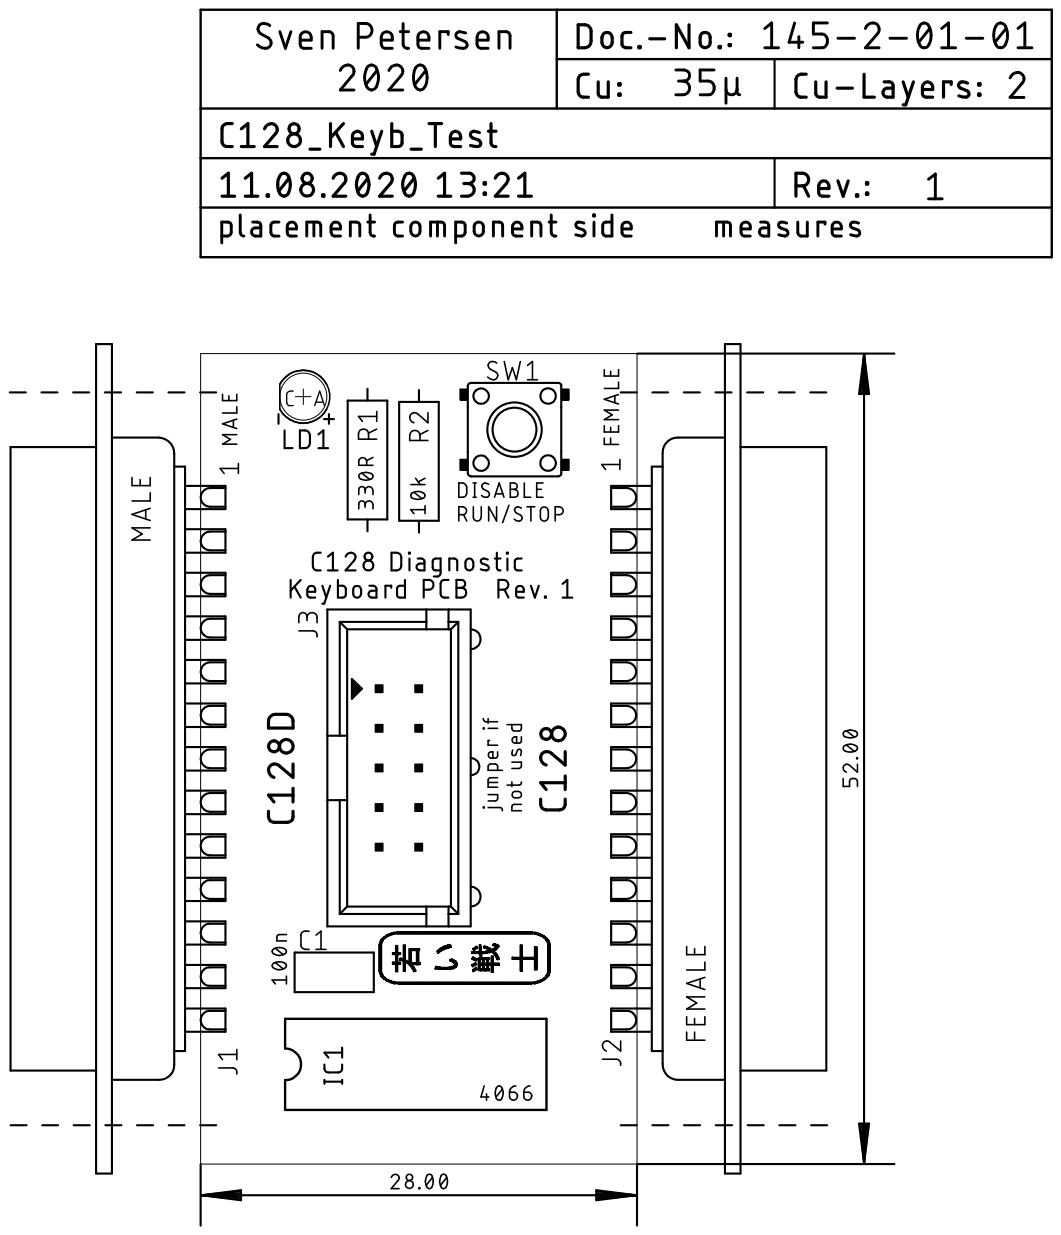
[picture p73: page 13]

Pos. Qty Value Footprint Ref.-No. Comment

1 1 145-2-01-01 2 Layer PCB Rev. 1 2 layer, Cu 35µ, HASL, 28.0 x 48.0mm, 1.6mm FR4

2 1 2x5pin box header,

2.54mm pitch

2X05WV J3 e.g. Reichelt.de: WSL 10G.

3 1 LED 3mm, green 3MM LD1 LED, standard

4 1 330R R-10 R1 Resistor, 0.25W, 5% or better

5 1 DB25F/EDGE DB25F-EDGE J2 DSub 25, female, solder cups, e.g. Reichelt.de: D-SUB BU

25

6 1 DB25M/EDGE DB25M-EDGE J1 DSub 25, male, solder cups, e.g. Reichelt.de: D-SUB ST 25

7 1 10k R-10 R1 Resistor, 0.25W, 5% or better

8 1 JTP-1130 JTP-1130 SW2 Standard 6x6mm tact switch, e.g. Namae JTP-1130 or any

other

9 1 HCF4066B DIL14 IC1 ST Micro or equivalent (4066)

10 1 DIL 14 DIL14 (IC1) DIL IC sockets

11 1 100n/50V C-2,5 C1 cer. cap, 2.5mm pitch

Rev. History

### Rev. 0.0 → 1.0

Pos. 1 PCB Revision

## C128 Diagnostic Keyboard PCB Rev. 1
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

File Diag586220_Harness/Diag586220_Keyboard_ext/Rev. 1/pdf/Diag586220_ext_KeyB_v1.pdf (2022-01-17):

# Project Documentation

## Diagnostic Rev. 586220 – Extended Keyboard Dongle

## Project number: 143

## Revision: 1

## Date: 11.03.2020

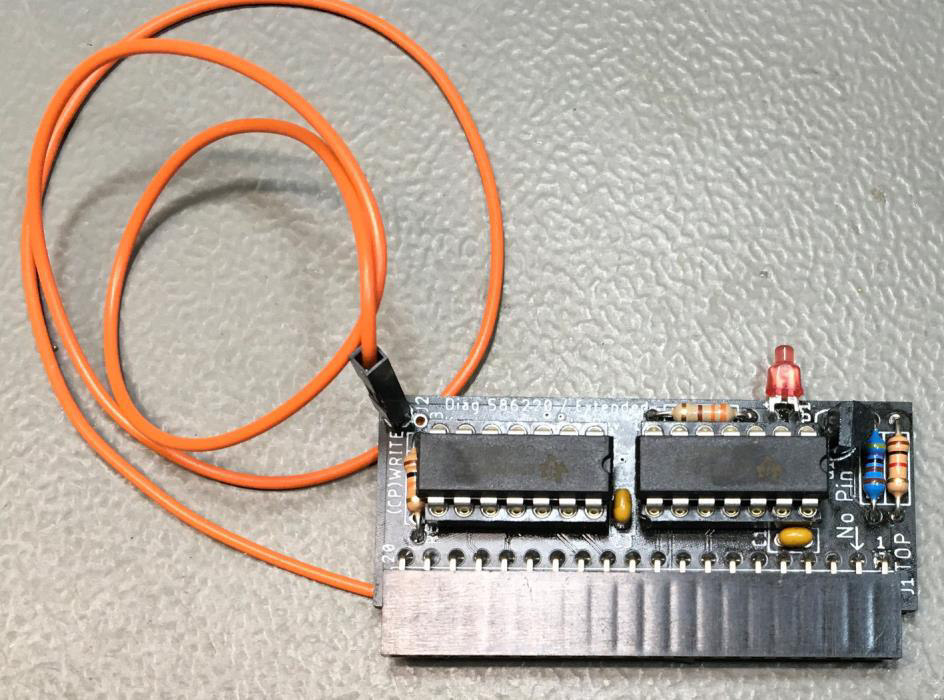
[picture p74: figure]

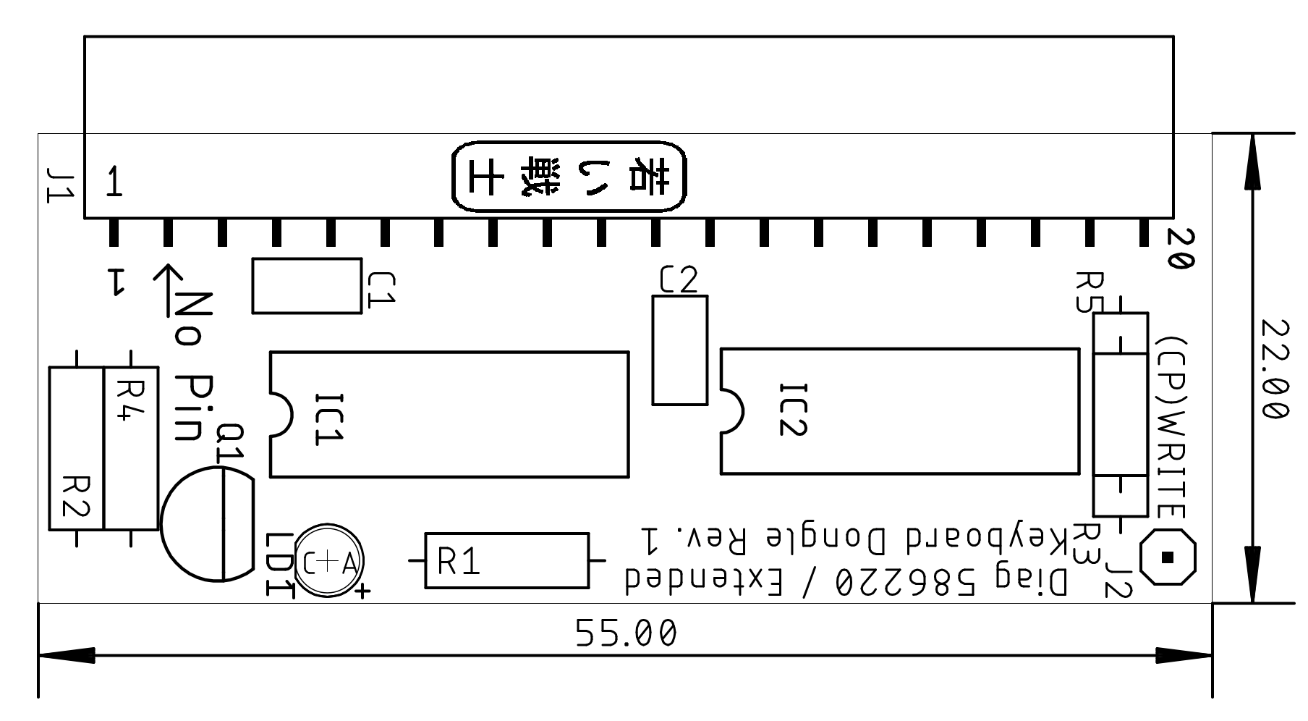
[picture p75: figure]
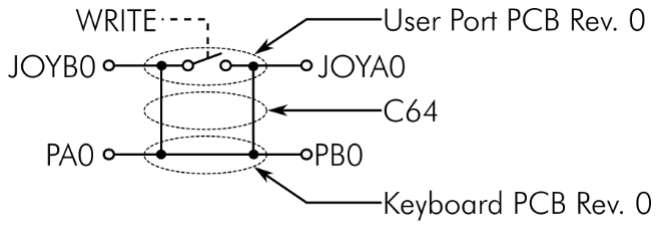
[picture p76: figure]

Diag586220_Keyb_Ext_ModD.docx | | 11.03.2020 09:59
Drafted by Sven Petersen | Page 1 of 3 | Doc.-No.: 143-6-01-01

### Diagnostic 586220 Harness - Keyboard Dongle Extended Rev. 1

### Module Description

## Introduction

The extended Keyboard Dongle is meant to be an extension to existing Diagnostic Harnesses. It prevents the false OK when testing the control ports, while the keyboard PCB is inserted. This is accomplished by analog switches for the feedbacks, that are in common with the joystick signals on the control ports.

Figure 1: Dimensions of the PCB

The extended Keyboard Dongle for Diagnostic 586220 provides the required feedback
connections for testing the C64’s CIA U1, which the keyboard is connected to. An LED serves
as an alternative power and operation indicator. It is normally on and switches off while testing the Control Ports.

The Restore key is connected to a dedicated line and is not tested.

What does Extended Keyboard PCB do better than the normal keyboard PCB?

As long as the old keyboard dongle is connected to the keyboard header, the feedbacks bridge the analog switches for testing the control ports. These analog switches are found on the User Port PCB. They are inside the two 4066 ICs there.

Figure 2: Test situation with the original diagnostic harness


Diag586220_Keyb_Ext_ModD.docx | | 11.03.2020 09:59
Drafted by Sven Petersen | Page 2 of 3 | Doc.-No.: 143-6-01-01

For properly testing the control ports, the old keyboard dongle has to be removed. This way, the test actually requires two passes. Otherwise, the control ports are tested improperly. A broken trace to the control port or a defective port connector would not be detected.

The extended Keyboard Dongle provides switched feedbacks for the signals, that are shared with the joysticks.

Figure 3: Test situation with the extended Keyboard Dongle
These are PB0«PA0, PB1«PA1, PB2«PA2, PB3«PA3 and PB4«PA4. The switches are opened by a (cassette port) WRITE signal going high, which also closes the connection on the user port dongle at the same time. The reason is, that

This WRITE signal is generated via a voltage divider on the user Port Dongle, which is also fed back to the Cassette Port Dongle. It can be found on Pin 5 of the cassette edge connector (on every kind of test harness). An existing harness can be easily modified by soldering a 40cm Dupont cable to the indicated Pin (refer to Figure 4), which is then connected to J2 (one pin) of the extended Keyboard Dongle.

Figure 4: Locating the Write signal

In case this cable is not connected, the extended Keyboard Dongle shows a behavior, that depends on which resistor R3 or R5 is placed. In case R3 is placed, it works like a normal keyboard dongle. The analog switches are closed.

In case R5 is placed, the keyboard feedbacks are open in case J2 is not connected. The test would report keyboard “BAD” (not open, since 3 feedbacks are still present). This might be the preferred behavior, since it indicates that the test did not work properly due to a lack of WRITE signal on this dongle. The LED is switched off, too.

The open state of the switches is indicated by the LED, which is off while testing the control ports (this needs to be observed).


Diag586220_Keyb_Ext_ModD.docx | | 11.03.2020 09:59
Drafted by Sven Petersen | Page 3 of 3 | Doc.-No.: 143-6-01-01

The extended Keyboard Dongle works with all versions of the standard Diagnostic 586220 software. A modification of the software is not required.

Figure 5: The Extended Keyboard Dongle on an ASSY 250469

## Connections

J1: 20p receptacle (pitch 2.54mm)

Pin | Signal | Signal Pin
5 | PB3 | « | PA3 | 17
6 | PB6 | « | PA6 | 14
7 | PB5 | « | PA5 | 15
8 | PB4 | « | PA4 | 16
9 | PB7 | « | PA7 | 20
10 | PB2 | « | PA2 | 18
11 | PB1 | « | PA1 | 19
12 | PB0 | « | PA0 | 13

J2: Single pin (DuPont). Input for the WRITE signal from the Cassette Port (Dongle).

## Revision History

### Rev. 0

Prototype. It requires a modification for working properly (see document 143-6-02-00).
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

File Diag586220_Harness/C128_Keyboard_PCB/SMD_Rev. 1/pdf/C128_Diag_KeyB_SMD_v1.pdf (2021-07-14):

# Project Documentation

## C128 Diagnostic – Keyboard PCB/SMD

## Project number: 181

## Revision: 1

## Date: 19.04.2021


C128_Diag_KB_ModD.docx | | 19.04.2021 17:24
Drafted by Sven Petersen | Page 1 of 3 | Doc.-No.: 181-6-01-01

### C128 Diagnostic – Keyboard PCB Rev. 1/SMD

### Module Description

## Introduction

This is the keyboard Dongle (PCB) for the Commodore C128 Diagnostic Rev. 588121. The required harness is identical to the C64 Diagnostic Rev. 586220 harness, except the keyboard PCB. The C64 harness can be found here:

https://github.com/svenpetersen1965/C64-Diagnostic-Rev.-586220-Harness
A part of the keyboard scan lines are shared with the control ports. To prevent a false “OK”
while testing these, the feedbacks can be opened. The required analog switches are implemented on the user port PCB (Rev. 1) of the said C64 harness. The connection to the user port PCB is provided by a ribbon cable, which can be connected to the box pin header J3.

In case this feature is not desired or the user port PCB is of an earlier revision, the adjacent pins of J3 can be jumpered with standard jumpers (1-2, 3-4, 5-6, 7-8 and 9-10).

Figure 1: Dimensions of the C128 Diagnostic Keyboard PCB

The footprint of the keyboard connector on the C128 mainboard is for a 90° female DSub-25 connector (for the C128D). A special pin header is populated on the mainboard. It fits a female DSub-25 connector (J2). The pin numbering is in the opposite direction of a normal male DSub-25, though. This results in a discrepancy of the pin numbering of J2, which is correct.
The regular feedbacks are COL0 to ROW0, COL1 to ROW1, … COL7 to ROW7.

The feedback COL7 to ROW7 mimics a RUN/STOP while power up. This causes the C128 to boot into the monitor program, which is not desired. This can be circumvented by pressing the

C128_Diag_KB_ModD.docx | | 19.04.2021 17:24
Drafted by Sven Petersen | Page 2 of 3 | Doc.-No.: 181-6-01-01

disable button on this PCB. This causes the analog switch (IC1) to open, which is responsible for this feedback.

## Connectors

Signal | J1 (C128D) | J2 (C128)
GND | 1 | 13
(no pin) | 2 | 12
RESTORE | 3 | 11
+5V | 4 | 10
ROW3 | 5 | 9
ROW6 | 6 | 8
ROW5 | 7 | 7
ROW4 | 8 | 6
ROW7 | 9 | 5
ROW2 | 10 | 4
ROW1 | 11 | 3
ROW0 | 12 | 2
COL0 | 13 | 1
COL6 | 14 | 25
COL5 | 15 | 24
COL4 | 16 | 23
COL3 | 17 | 22
COL2 | 18 | 21
COL1 | 19 | 20
COL7 | 20 | 19
K0 | 21 | 18
K1 | 22 | 17
K2 | 23 | 16
40/80 | 24 | 15
CAPS LOCK | 25 | 14

J3 – box pin header 2x5 circuits

Signal Pin | Pin Signal
COL4 | 1 | 2 | ROW4
COL3 | 3 | 4 | ROW3
COL2 | 5 | 6 | ROW2
COL1 | 7 | 8 | ROW1
COL0 | 9 | 10 | ROW0

C128_Diag_KB_ModD.docx | | 19.04.2021 17:24
Drafted by Sven Petersen | Page 3 of 3 | Doc.-No.: 181-6-01-01

## Links

This PCB is designed based on the following information:

- http://blog.worldofjani.com/?p=164
- http://personalpages.tds.net/~rcarlsen/cbm/c128/SCHEMATICS/
- https://commons.wikimedia.org/wiki/File:C128mobo.jpg?uselang=de

## Revision History

### Rev. 0

- Prototype

### Rev. 1

- PCB Revision: board is now 28mm wide

### Rev. 1/SMD

- Board revision
- R, C, IC SMD footprints for easier manufacturing










Pos. Qty Value Footprint Ref.-No. Comment

1 1 181-2-01-01 2 Layer PCB Rev. 1 2 layer, Cu 35µ, HASL, 28.0 x 48.0mm, 1.6mm FR4

2 1 2x5pin box header,

2.54mm pitch

2X05WV J3 e.g. Reichelt.de: WSL 10G.

3 1 LED 3mm, green 3MM LD1 LED, standard

4 1 330R 0805 R1 Resistor, 0.25W, 5% or better

5 1 DB25F/EDGE DB25F-EDGE J2 DSub 25, female, solder cups, e.g. Reichelt.de: D-SUB BU

25

6 1 DB25M/EDGE DB25M-EDGE J1 DSub 25, male, solder cups, e.g. Reichelt.de: D-SUB ST 25

7 1 10k 0805 R1 Resistor, 0.25W, 5% or better

8 1 JTP-1130 JTP-1130 SW2 Standard 6x6mm tact switch, e.g. Namae JTP-1130 or any

other

9 1 HCF4066B SO14 IC1 ST Micro or equivalent (4066)

10 1 100n/50V 0805 C1 cer. Cap

Rev. History

### Rev. 0.0 → 1.0

Pos. 1 PCB Revision

### Rev. 1.0 → 1.0/SMD

Pos. 1 PCB Revision

### 4 SMD

### 7 SMD

### 9 SMD 10 SMD

## C128 Diagnostic Keyboard PCB/SMD Rev. 1
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

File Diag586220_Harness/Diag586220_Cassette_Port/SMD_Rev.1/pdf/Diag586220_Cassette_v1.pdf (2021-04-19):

# Project Documentation

## Diagnostic Rev. 586220 Harness - Cassette Port/SMD

## Project number: 180

## Revision: 1

## Date: 19.04.2021


Diag586220_Cassette_ModD_v1.docx | | 19.04.2021 15:49
Drafted by Sven Petersen | Page 1 of 2 | Doc.-No.: 180-6-01-01

### Diagnostic Rev. 586220 Harness - Cassette Port/SMD Rev. 1

### Module Description

This PCB is a part of the harness for the Diagnostic Rev. 586220 test software for the Commodore C64.

The cassette port PCB connects to the cassette port of the C64 and provides the signal on a 2x3 pin header, which is connected to the central component of the Diagnostic Rev. 586220 harness, the user port PCB.

J3 provides the WRITE signals, which serves for switching off the analog switches on the extended Keyboard Dongle (Project No. 143).

This version of the Cassette Port Dongle can be used with version 0 of the user port dongle and the previous keyboard dongle (Project No. 116) or the extended keyboard dongle. The WRITE signal only connects to the latter.

There are two LEDs on this PCB. One showing the status of the Motor Signal and the other showing the status of the SENSE signal. To keep the load low on the sense signal, a transistor amplifies the SENSE to provide enough current for the latter LED.

Figure 1: The CASSETTE Port PCB

The male Cassette Port edge connector was added to make this a real break out board, which fits between the C64 and the Datassette.

## Pin outs

### Cassette Port

J1 – 2 x 6p edge connector (pitch 3.96mm)

Pin Signal | Pin Signal
1 | GND | A | GND
2 | +5V | B | +5V
3 | MOTOR | C | MOTOR
4 | READ | D | READ
5 | WRITE | E | WRITE
6 | SENSE | F | SENSE

Diag586220_Cassette_ModD_v1.docx | | 19.04.2021 15:49
Drafted by Sven Petersen | Page 2 of 2 | Doc.-No.: 180-6-01-01

### Harness Connector

J2 – 2x3p Pin Header (pitch 2.54mm)

Pin Signal | Pin Signal
1 | GND | 2 | +5V
3 | MOTOR | 4 | READ
5 | WRITE | 6 | SENSE

### WRITE Pin

J3 – 1x1p Pin Header

Pin Signal

### 1 WRITE

## Test

The test was passed successfully. It is described in the document of the User Port Dongle.

## Revision History

### Rev. 0 → Rev. 1

- J3 is new. It provides the WRITE Signal for the Extended Keyboard Dongle.
- The Sense LED was added.
- The male edge connector was added to make this PCB a cassette breakout board

### Rev. 1 → Rev. 1/SMD

- Resistors and transistor in an SMD case.









Pos. Qty Value Footprint Ref.-No. Comment

1 1 180-2-01-01 2 Layer PCB Rev. 1 2 layer, Cu 35µ, HASL, 30.0mm x 43.0mm, 1.6mm FR4

2 1 2x6, 3.96mm pitch C64-TAPEPORT J1 edge connector, C64 cassette port

3 1 2x3 box connector 2X03WV J2 e.g. Reichelt WSL 6G
4 1 3mm/green 3MM LD1 LED, 3mm, green
5 2 330R 0805 R1, R2 1/4 Watt, 5%

6 1 BC846B SOT23 Q1 Transistor, universal NPN (or BC847 etc.)

7 1 10K 0805 R3 1/4 Watt, 5%

8 1 3mm/red 3MM LD2 LED, 3mm, red

9 1 pin header 1p 1x01 J3 Pin header for DuPont contact/do not place

10 1 C64 Tapeport M C64-TAPEPORTM J4 do not place. Structure in copper/PCB

## Diagnostic Rev. 586220 Harness - Cassette Port SMD Rev. 1

## Bill of Material Rev. 1.0

Diag586220_Cassette_SMD_BOM_v1_0.xlsx

Drafted by Sven Petersen Page 1 of 1

19.04.2021 15:59
Doc.No.: 180-5-01-01.0

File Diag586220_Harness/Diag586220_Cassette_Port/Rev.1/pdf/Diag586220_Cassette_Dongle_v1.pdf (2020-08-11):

# Project Documentation

## Diagnostic Rev. 586220 Harness - Cassette Port

## Project number: 114

## Revision: 1

## Date: 16.02.2020


Diag586220_Cassette_ModD_v1.docx | | 11.03.2020 10:59
Drafted by Sven Petersen | Page 1 of 2 | Doc.-No.: 114-6-01-01

### Diagnostic Rev. 586220 Harness - Cassette Port Rev. 1

### Module Description

This PCB is a part of the harness for the Diagnostic Rev. 586220 test software for the Commodore C64.

The cassette port PCB connects to the cassette port of the C64 and provides the signal on a 2x3 pin header, which is connected to the central component of the Diagnostic Rev. 586220 harness, the user port PCB.

J3 provides the WRITE signals, which serves for switching off the analog switches on the extended Keyboard Dongle (Project No. 143).

This version of the Cassette Port Dongle can be used with version 0 of the user port dongle and the previous keyboard dongle (Project No. 116) or the extended keyboard dongle. The WRITE signal only connects to the latter.

There are two LEDs on this PCB. One showing the status of the Motor Signal and the other showing the status of the SENSE signal. To keep the load low on the sense signal, a transistor amplifies the SENSE to provide enough current for the latter LED.

Figure 1: The CASSETTE Port PCB

The male Cassette Port edge connector was added to make this a real break out board, which fits between the C64 and the Datasette.

## Pin outs

### Cassette Port

J1 – 2 x 6p edge connector (pitch 3.96mm)

Pin Signal | Pin Signal
1 | GND | A | GND
2 | +5V | B | +5V
3 | MOTOR | C | MOTOR
4 | READ | D | READ
5 | WRITE | E | WRITE
6 | SENSE | F | SENSE

Diag586220_Cassette_ModD_v1.docx | | 11.03.2020 10:59
Drafted by Sven Petersen | Page 2 of 2 | Doc.-No.: 114-6-01-01

### Harness Connector

J2 – 2x3p Pin Header (pitch 2.54mm)

Pin Signal | Pin Signal
1 | GND | 2 | +5V
3 | MOTOR | 4 | READ
5 | WRITE | 6 | SENSE

### WRITE Pin

J3 – 1x1p Pin Header

Pin Signal

### 1 WRITE

## Test

The test was passed successfully. It is described in the document of the User Port Dongle.

## Revision History

### Rev. 0 → Rev. 1

- J3 is new. It provides the WRITE Signal for the Extended Keyboard Dongle.
- The Sense LED was added.
- The male edge connector was added to make this PCB a cassette breakout board










Pos. Qty Value Footprint Ref.-No. Comment

1 1 114-2-01-01 2 Layer PCB Rev. 1 2 layer, Cu 35µ, HASL, 30.0mm x 43.0mm, 1.6mm FR4

2 1 2x6, 3.96mm pitch C64-TAPEPORT J1 edge connector, C64 cassette port

3 1 2x3 box connector 2X03WV J2 e.g. Reichelt WSL 6G
4 1 3mm/green 3MM LD1 LED, 3mm, green
5 2 330R RES04 R1, R2 1/4 Watt, 5%

6 1 BC547B TO-92 Q1 Transistor, universal NPN

7 1 10K RES04 R3 1/4 Watt, 5%

8 1 3mm/red 3MM LD2 LED, 3mm, red

9 1 pin header 1p 1x01 J3 Pin header for DuPont contact

10 1 C64 Tapeport M C64-TAPEPORTM J4 do not place. Structure in copper/PCB

## Diagnostic Rev. 586220 Harness - Cassette Port Rev. 1

## Bill of Material Rev. 1.0

Diag586220_Cassette_BOM_v1_0.xlsx

Drafted by Sven Petersen Page 1 of 1

11.03.2020 17:19
Doc.No.: 114-5-01-01.0

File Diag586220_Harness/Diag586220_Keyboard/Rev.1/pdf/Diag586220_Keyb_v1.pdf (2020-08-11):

# Project Documentation

## Diagnostic Rev. 586220 Harness - Keyboard Dongle

## Project number: 116

## Revision: 1

## Date: 01.03.2020

Diag586220_Keyb_ModB.docx | | 11.03.2020 11:02
Drafted by Sven Petersen | Page 1 of 1 | Doc.-No.: 116-6-01-01

### Diagnostic 586220 Harness - Keyboard Dongle Rev. 1

### Module Description

The Keyboard Dongle for Diagnostic 586220 provides the required feedback connections for

### testing the C64’s CIA U1, which the keyboard is connected to. A LED and current limiting

resistor is connected between the +5V and GND pin of the keyboard. The Restore key is connected to a dedicated line and is not tested.

The feedbacks shared with the joystick signals are connected to a pin header, which is then connected to analog switches on the User Port PCB via a ribbon cable. In case this feature is not desired, the adjacent pins (1-2, 3-4, …) can be jumpered.

## Connections

20p receptacle (pitch 2.54mm)

Pin | Signal | Signal Pin
5 | PB3 | «* | PA3 | 17
6 | PB6 | « | PA6 | 14
7 | PB5 | « | PA5 | 15
8 | PB4 | «* | PA4 | 16
9 | PB7 | « | PA7 | 20
10 | PB2 | «* | PA2 | 18
11 | PB1 | «* | PA1 | 19
12 | PB0 | «* | PA0 | 13
- Switched interconnects (via ribbon cable and User Port PCB.

## Connector to User Port PCB

2x5p boxed pin header, 2.54mm pitch

Signal Pin | Pin Signal
PB0 | 1 | 2 | PA0
PB4 | 3 | 4 | PA4
PB3 | 5 | 6 | PA3
PB2 | 7 | 8 | PA2
PB1 | 9 | 10 | PA1
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

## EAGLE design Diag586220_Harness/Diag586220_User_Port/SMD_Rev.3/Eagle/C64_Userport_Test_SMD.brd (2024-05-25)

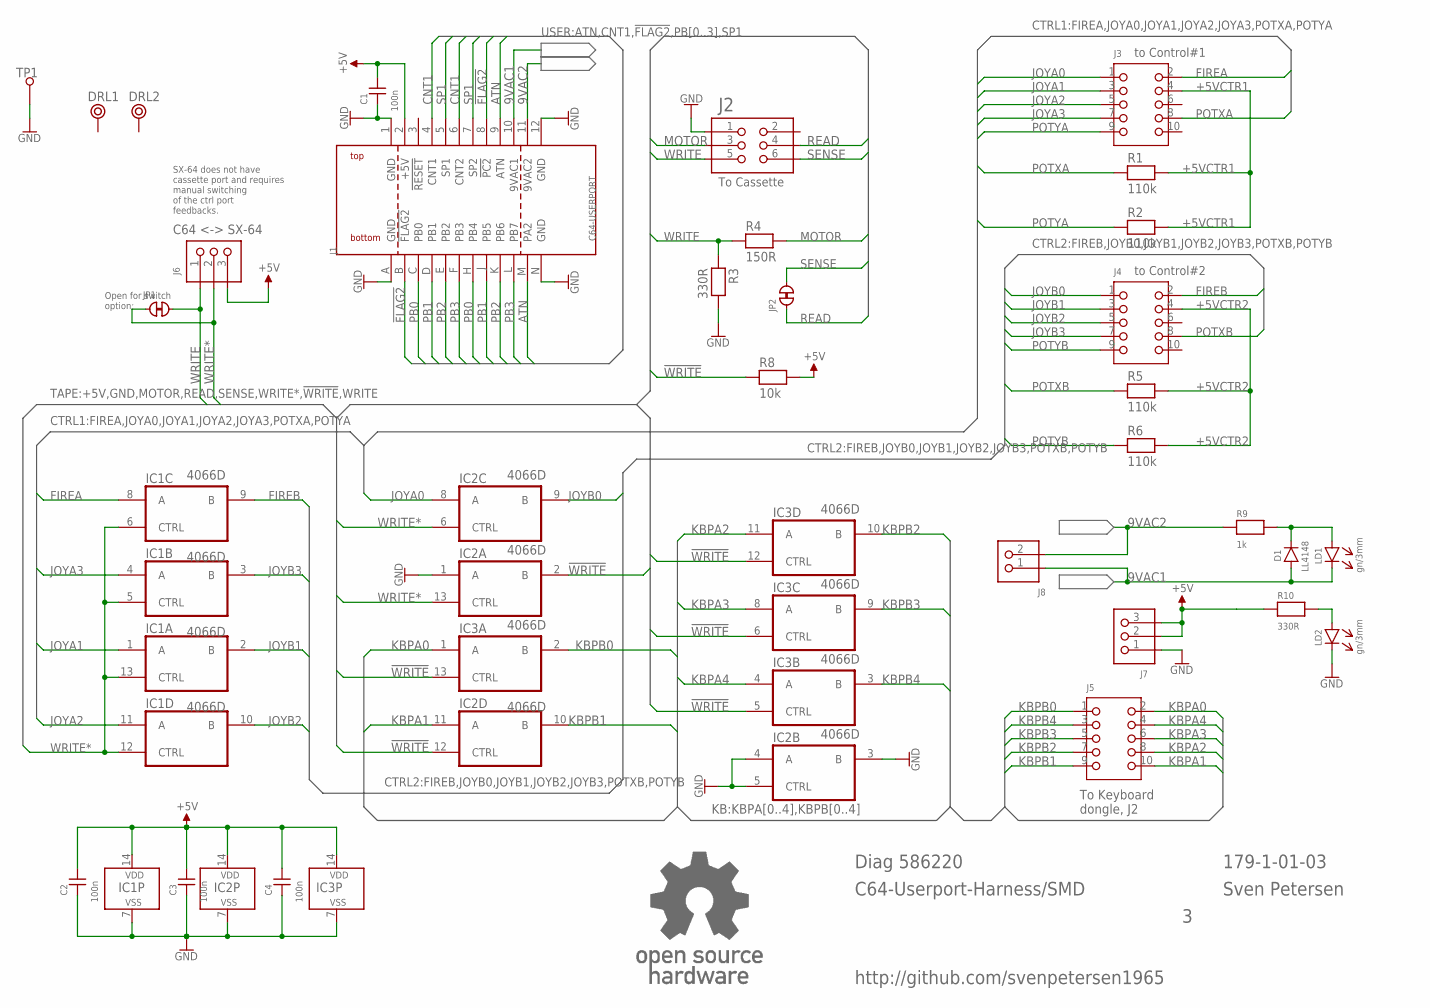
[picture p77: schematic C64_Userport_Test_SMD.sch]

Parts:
C1, C2, C3, C4: 100n; 0805
D1: LL4148; SOD80C
DRL1, DRL2: BOHR3,2
IC1, IC2, IC3: 4066D; SO14
J1: C64-USERPORT; USERPORT
J2: 2X03WV
J3, J4, J5: 2X05WV
J6, J7: PINHD-1X3; 1X03
J8: PINHD-1X2; 1X02
JP1, JP2: CLOSED; CP_CL
LD1, LD2: gn/3mm; 3MM
R1, R2, R5, R6: 110k; 0805
R3, R10: 330R; 0805
R4: 150R; 0805
R8: 10k; 0805
R9: 1k; 0805
TP1: L1,2_R; 1,2MM_R
U$20: OPEN_SOURCE_HW; OPENHW

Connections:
9VAC1: D1.A, J1.10 (9VAC1), J8.1, LD1.C (K)
9VAC2: J1.11 (9VAC2), J8.2, R9.1
!FLAG2: J1.8 (!PC2), J1.B (!FLAG2)
!WRITE: IC2.2 (B), IC2.12 (CTRL), IC3.5 (CTRL), IC3.6 (CTRL), IC3.12 (CTRL), IC3.13 (CTRL), R8.1
+5V: C1.2, C2.2, C3.2, C4.2, IC1.14 (VDD), IC2.14 (VDD), IC3.14 (VDD), J1.2 (+5V), J6.3, J7.2, J7.3, R8.2, R10.1
+5VCTR1: J3.4, R1.2, R2.2
+5VCTR2: J4.4, R5.2, R6.2
ATN: J1.9 (ATN), J1.M (PA2)
CNT1: J1.4 (CNT1), J1.6 (CNT2)
FIREA: IC1.8 (A), J3.2
FIREB: IC1.9 (B), J4.2
GND: C1.1, C2.1, C3.1, C4.1, IC1.7 (VSS), IC2.1 (A), IC2.3 (B), IC2.4 (A), IC2.5 (CTRL), IC2.7 (VSS), IC3.7 (VSS), J1.1 (GND), J1.12 (GND), J1.A (GND), J1.N (GND), J2.1, J7.1, LD2.C (K), R3.2, TP1.1
JOYA0: IC2.8 (A), J3.1
JOYA1: IC1.1 (A), J3.3
JOYA2: IC1.11 (A), J3.5
JOYA3: IC1.4 (A), J3.7
JOYB0: IC2.9 (B), J4.1
JOYB1: IC1.2 (B), J4.3
JOYB2: IC1.10 (B), J4.5
JOYB3: IC1.3 (B), J4.7
KBPA0: IC3.1 (A), J5.2
KBPA1: IC2.11 (A), J5.10
KBPA2: IC3.11 (A), J5.8
KBPA3: IC3.8 (A), J5.6
KBPA4: IC3.4 (A), J5.4
KBPB0: IC3.2 (B), J5.1
KBPB1: IC2.10 (B), J5.9
KBPB2: IC3.10 (B), J5.7
KBPB3: IC3.9 (B), J5.5
KBPB4: IC3.3 (B), J5.3
MOTOR: J2.3, R4.2
unnamed: D1.K, LD1.A, R9.2
unnamed: LD2.A, R10.2
PB0: J1.C (PB0), J1.H (PB4)
PB1: J1.D (PB1), J1.J (PB5)
PB2: J1.E (PB2), J1.K (PB6)
PB3: J1.F (PB3), J1.L (PB7)
POTXA: J3.8, R1.1
POTXB: J4.8, R5.1
POTYA: J3.9, R2.1
POTYB: J4.9, R6.1
READ: J2.4, JP2.1
SENSE: J2.6, JP2.2
SP1: J1.5 (SP1), J1.7 (SP2)
WRITE: J2.5, J6.1, JP1.2, R3.1, R4.1
WRITE*: IC1.5 (CTRL), IC1.6 (CTRL), IC1.12 (CTRL), IC1.13 (CTRL), IC2.6 (CTRL), IC2.13 (CTRL), J6.2, JP1.1

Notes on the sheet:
Diag 586220
C64-Userport-Harness/SMD
Sven Petersen
To Cassette
to Control#1
to Control#2
179-1-01-03
To Keyboard dongle, J2
C64 <-> SX-64
Open for switch option:
SX-64 does not have cassette port and requires manual switching of the ctrl port feedbacks.
http://github.com/svenpetersen1965

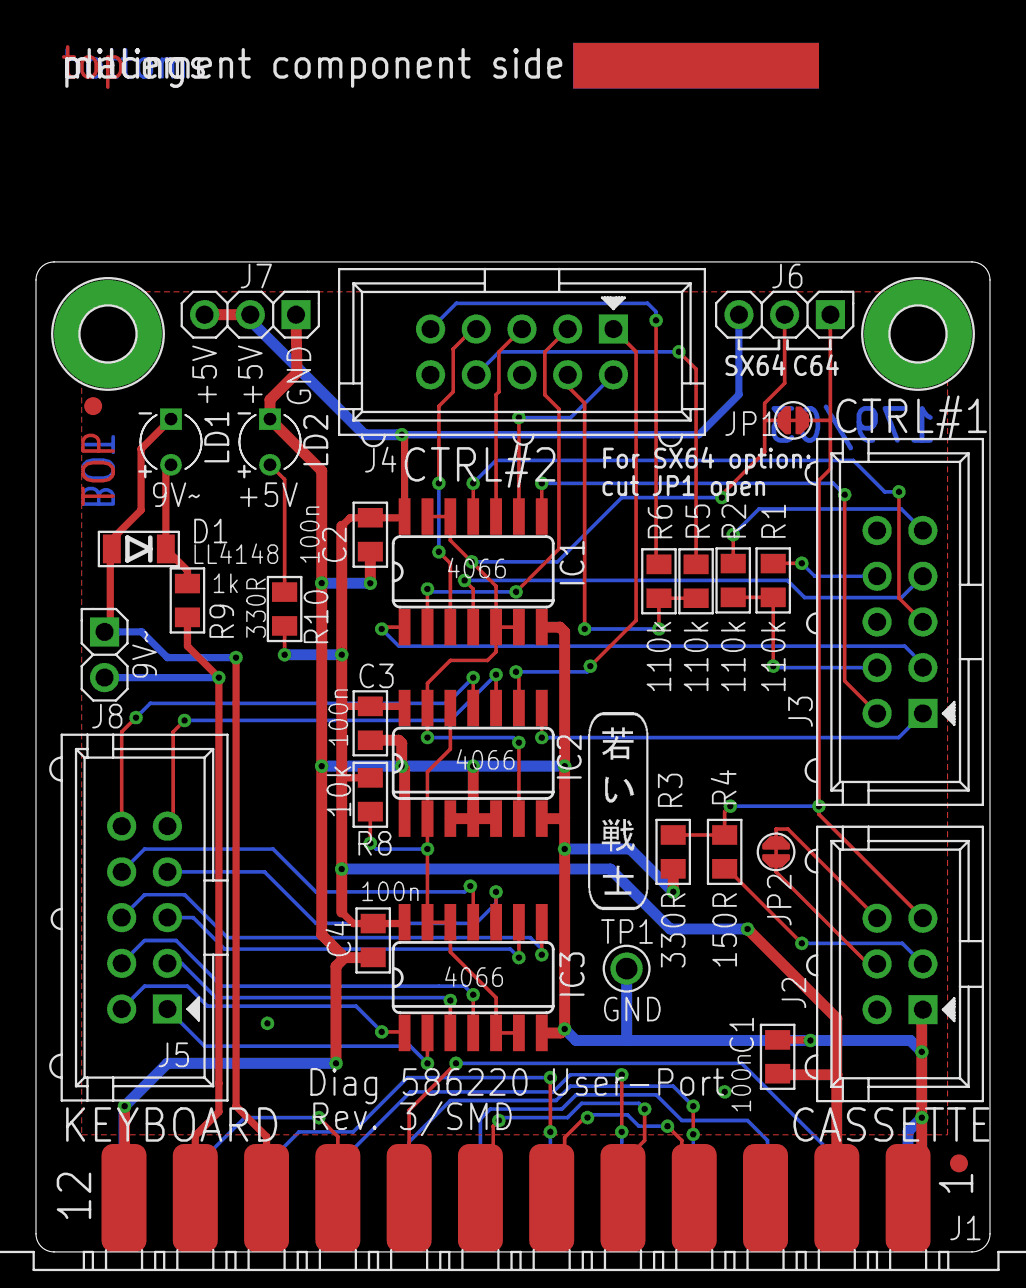
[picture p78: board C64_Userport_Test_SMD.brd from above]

Board: 2 copper layers, 53.0 x 55.0 mm, 38 parts (1 on the bottom side), 46 nets.

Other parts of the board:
U$15: SVEN_TAG
U$17: 2LAYER
U$18: PCB-TITLE/
U$21, U$22: SMD_REF_R1MM

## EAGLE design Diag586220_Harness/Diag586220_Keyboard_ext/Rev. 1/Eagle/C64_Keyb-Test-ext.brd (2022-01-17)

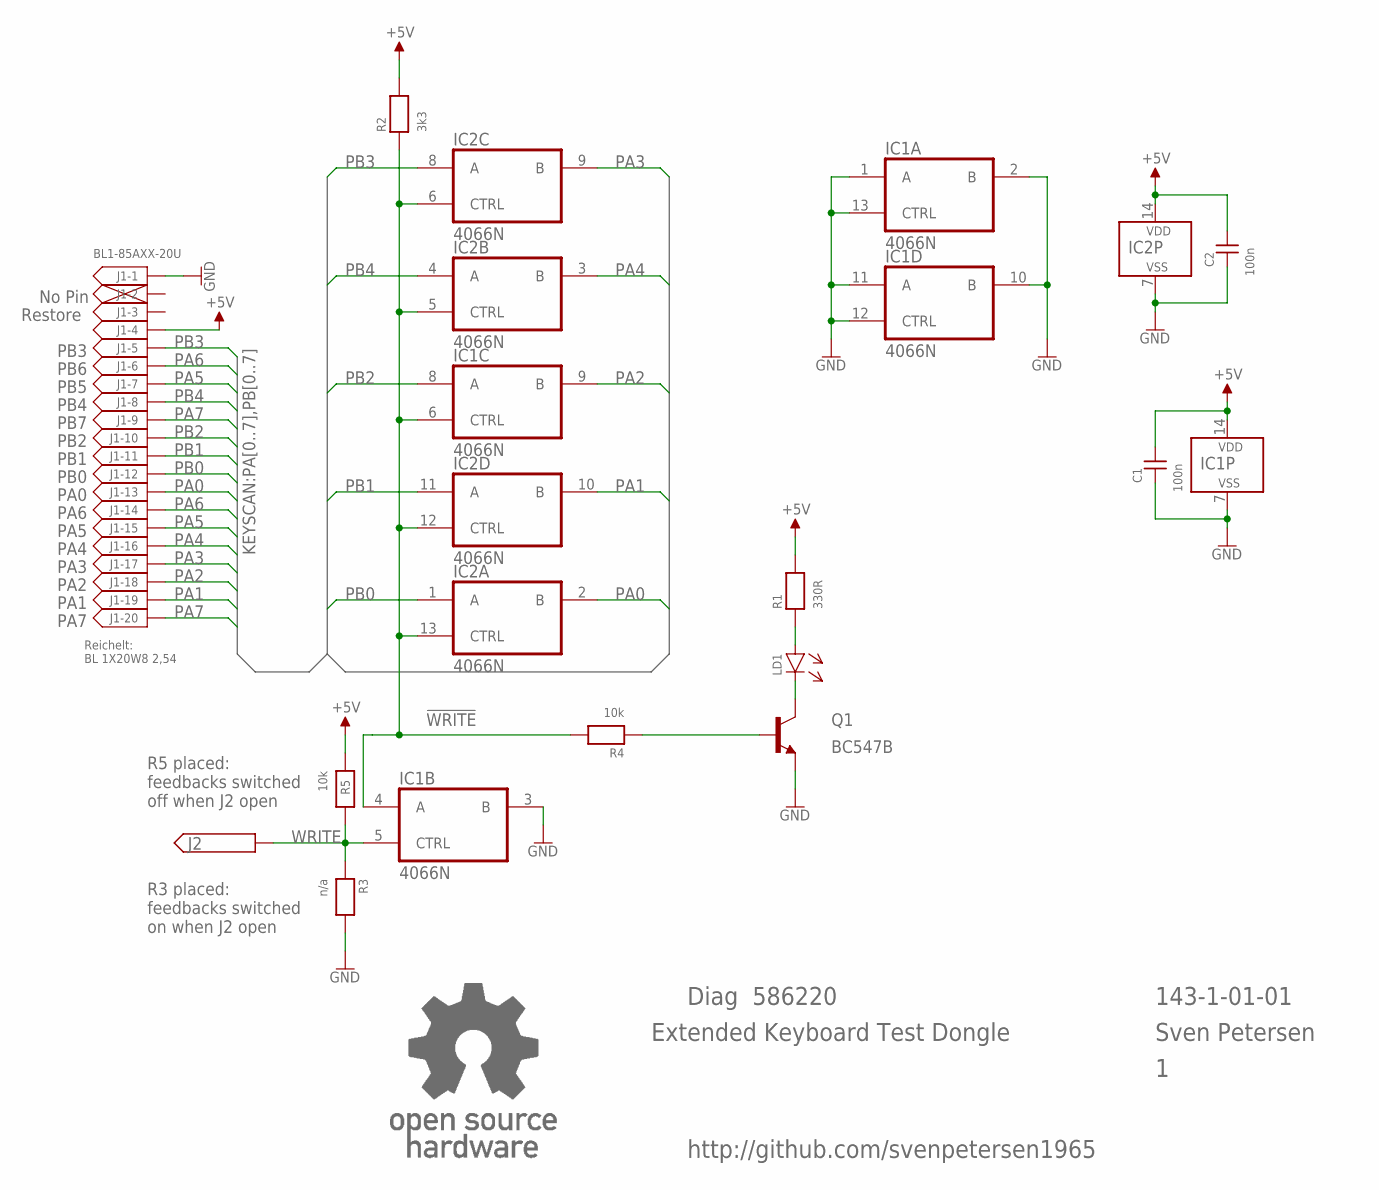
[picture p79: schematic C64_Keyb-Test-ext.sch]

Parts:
C1, C2: 100n; C-2,5
IC1, IC2: 4066N; DIL14
J1: BL1-85AXX-20U
J2: PINHD-1X1; 1X01
LD1: 3MM
Q1: BC547B; TO92
R1: 330R; R-10
R2: 3k3; R-10
R3: n/a; R-10
R4, R5: 10k; R-10
U$19: OPEN_SOURCE_HW; OPENHW

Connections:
!WRITE: IC1.4 (A), IC1.6 (CTRL), IC2.5 (CTRL), IC2.6 (CTRL), IC2.12 (CTRL), IC2.13 (CTRL), R2.1, R4.2
+5V: C1.2, C2.2, IC1.14 (VDD), IC2.14 (VDD), J1.4, R1.2, R2.2, R5.1
GND: C1.1, C2.1, IC1.1 (A), IC1.2 (B), IC1.3 (B), IC1.7 (VSS), IC1.10 (B), IC1.11 (A), IC1.12 (CTRL), IC1.13 (CTRL), IC2.7 (VSS), J1.1, Q1.1 (E), R3.2
unnamed: LD1.A, R1.1
unnamed: LD1.C (K), Q1.3 (C)
unnamed: Q1.2 (B), R4.1
PA0: IC2.2 (B), J1.13
PA1: IC2.10 (B), J1.19
PA2: IC1.9 (B), J1.18
PA3: IC2.9 (B), J1.17
PA4: IC2.3 (B), J1.16
PA5: J1.7, J1.15
PA6: J1.6, J1.14
PA7: J1.9, J1.20
PB0: IC2.1 (A), J1.12
PB1: IC2.11 (A), J1.11
PB2: IC1.8 (A), J1.10
PB3: IC2.8 (A), J1.5
PB4: IC2.4 (A), J1.8
WRITE: IC1.5 (CTRL), J2.1, R3.1, R5.2

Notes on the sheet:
PB3
PB6
PB5
PB4
PB7
PB2
PB1
PB0
PA0
PA6
PA5
PA4
PA3
PA2
PA1
PA7
No Pin
Restore
Diag 586220
Extended Keyboard Test Dongle
143-1-01-01
Sven Petersen
Reichelt: BL 1X20W8 2,54
R5 placed: feedbacks switched off when J2 open
R3 placed: feedbacks switched on when J2 open
http://github.com/svenpetersen1965

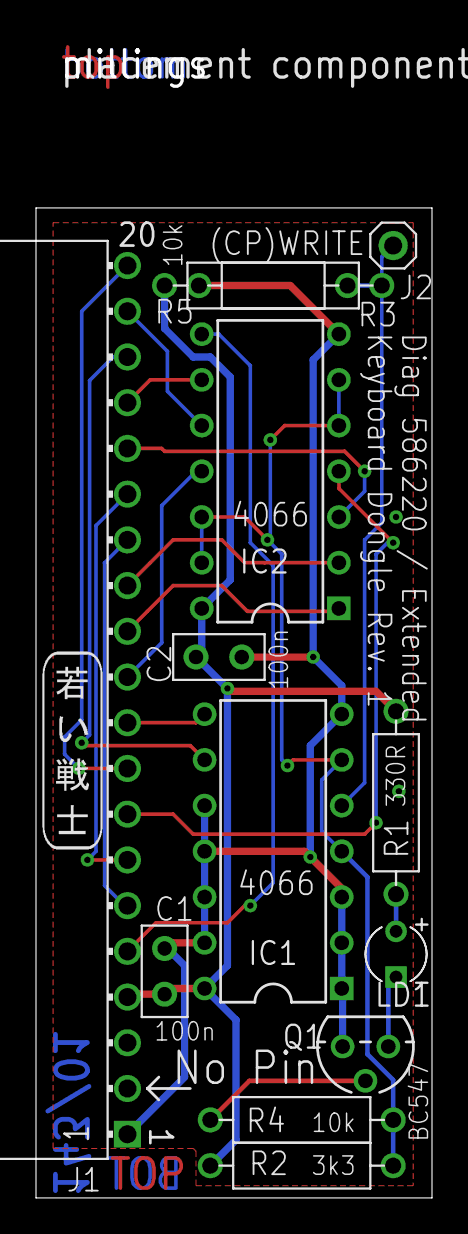
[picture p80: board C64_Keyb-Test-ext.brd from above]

Board: 2 copper layers, 22.0 x 55.0 mm, 17 parts (1 on the bottom side), 20 nets.

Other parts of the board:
U$6: 2LAYER
U$7: PCB-TITLE/
U$17: SVEN_TAG

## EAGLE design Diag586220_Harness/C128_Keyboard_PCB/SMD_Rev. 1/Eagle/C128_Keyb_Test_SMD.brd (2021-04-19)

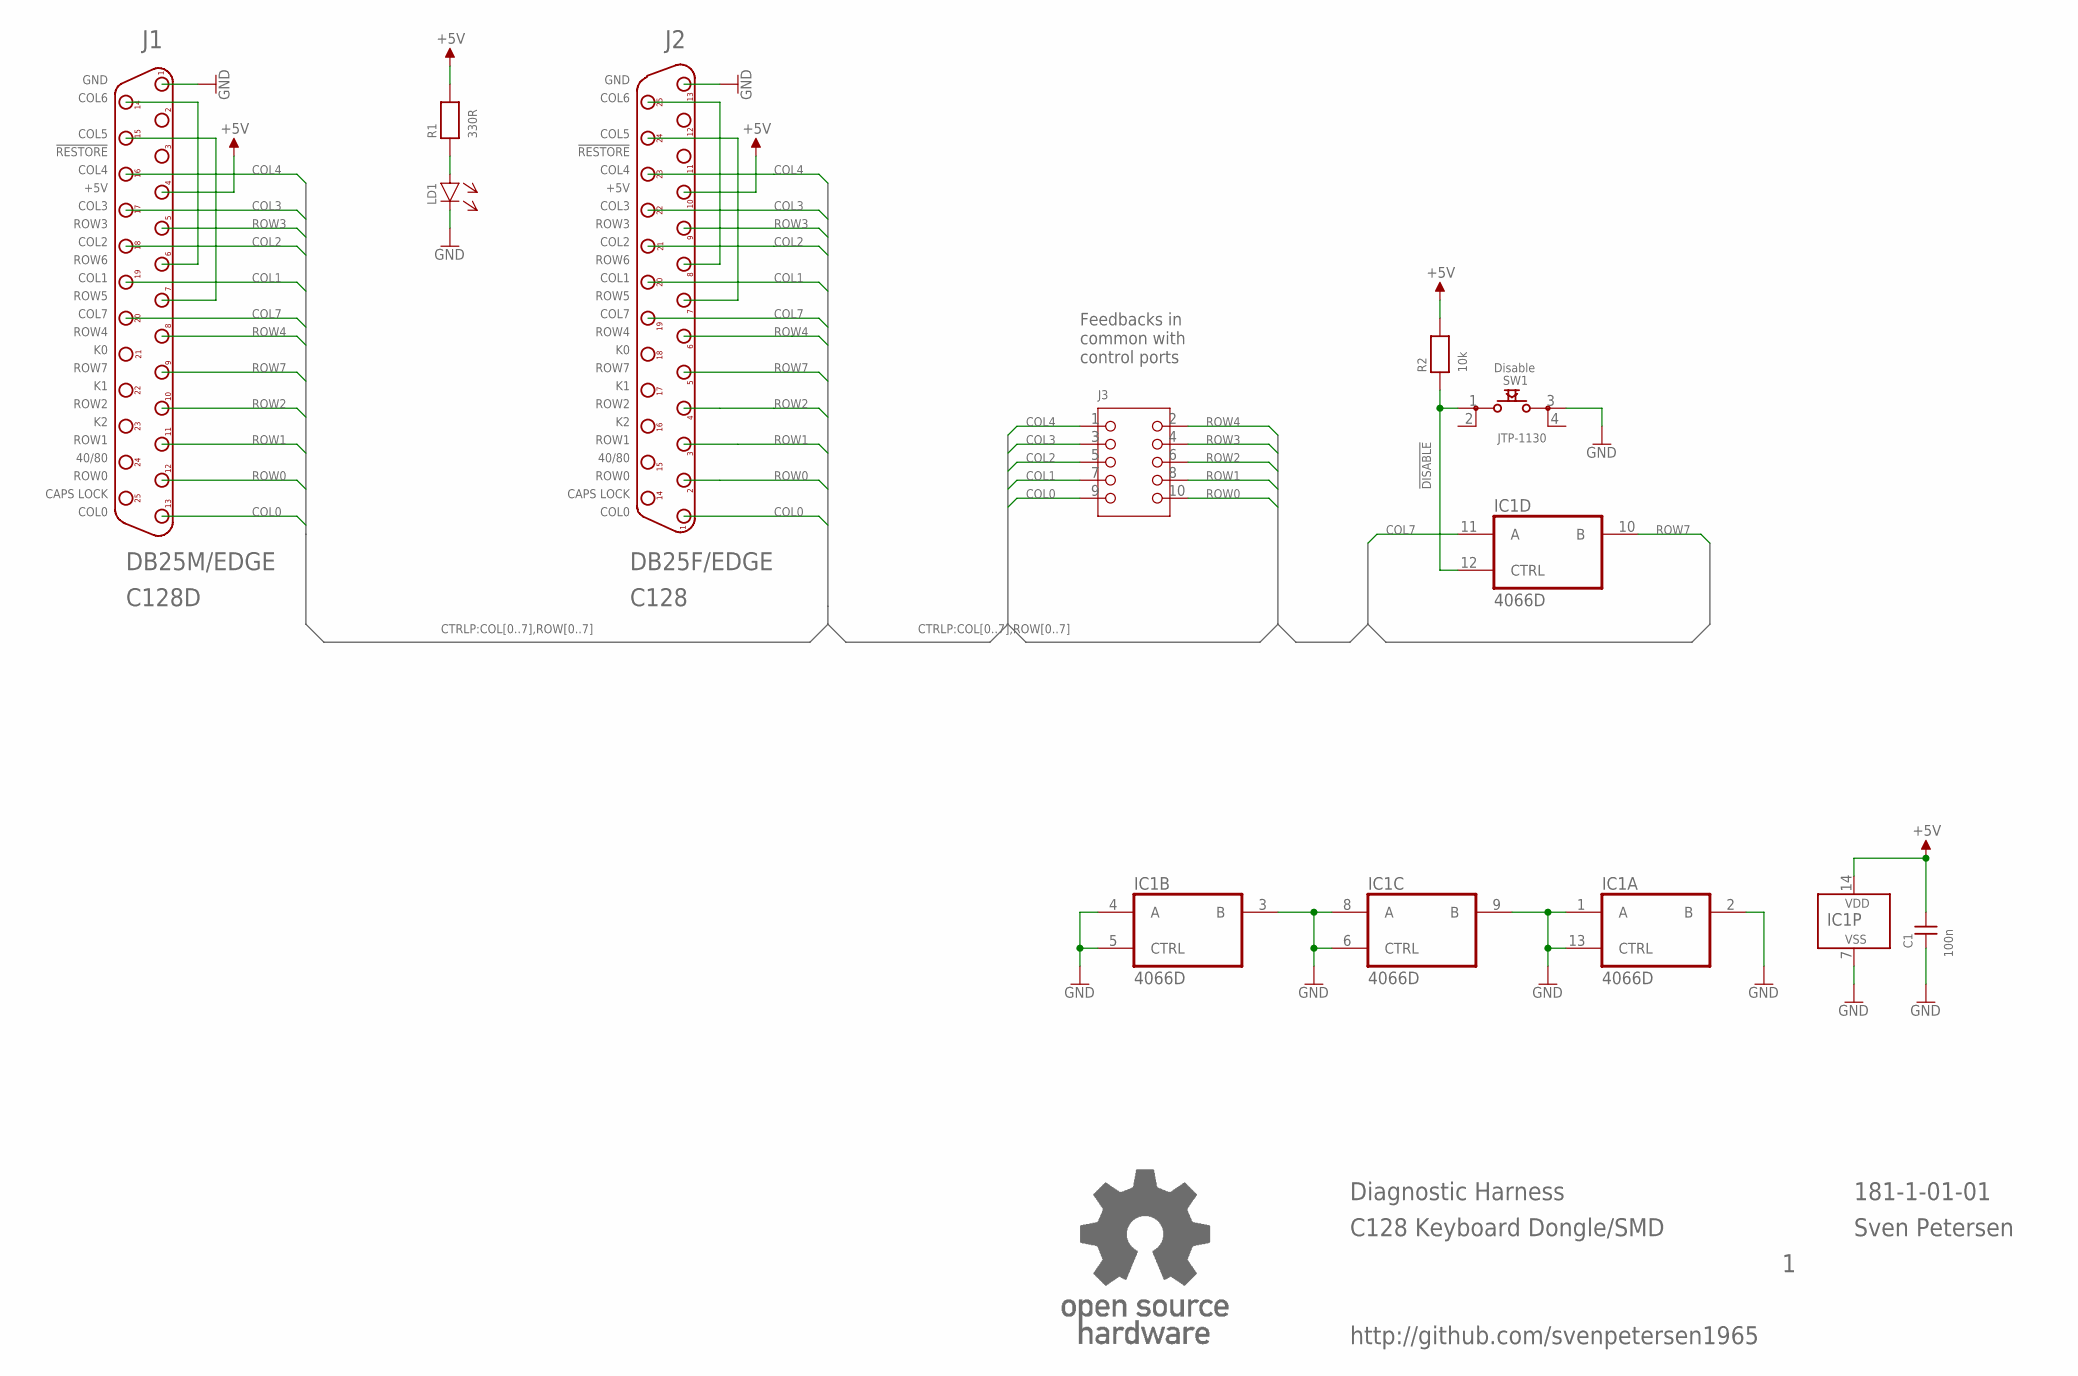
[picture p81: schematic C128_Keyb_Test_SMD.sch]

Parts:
C1: 100n; 0805
IC1: 4066D; SO14
J1: DB25M/EDGE; DB25M-EDGE
J2: DB25F/EDGE; DB25F-EDGE
J3: 2X05WV
LD1: 3MM
R1: 330R; 0805
R2: 10k; 0805
SW1: JTP-1130
U$20: OPEN_SOURCE_HW; OPENHW

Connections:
!DISABLE: IC1.12 (CTRL), R2.1, SW1.1
+5V: C1.2, IC1.14 (VDD), J1.4, J2.10, R1.2, R2.2
COL0: J1.13, J2.1, J3.9
COL1: J1.19, J2.20, J3.7
COL2: J1.18, J2.21, J3.5
COL3: J1.17, J2.22, J3.3
COL4: J1.16, J2.23, J3.1
COL7: IC1.11 (A), J1.20, J2.19
GND: C1.1, IC1.1 (A), IC1.2 (B), IC1.3 (B), IC1.4 (A), IC1.5 (CTRL), IC1.6 (CTRL), IC1.7 (VSS), IC1.8 (A), IC1.9 (B), IC1.13 (CTRL), J1.1, J2.13, LD1.C (K), SW1.3
unnamed: J1.6, J1.14
unnamed: J1.7, J1.15
unnamed: LD1.A, R1.1
unnamed: J2.7, J2.24
unnamed: J2.8, J2.25
ROW0: J1.12, J2.2, J3.10
ROW1: J1.11, J2.3, J3.8
ROW2: J1.10, J2.4, J3.6
ROW3: J1.5, J2.9, J3.4
ROW4: J1.8, J2.6, J3.2
ROW7: IC1.10 (B), J1.9, J2.5

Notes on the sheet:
Diagnostic Harness
C128 Keyboard Dongle/SMD
181-1-01-01
Sven Petersen
C128D
C128
ROW0
ROW1
ROW2
ROW3
ROW4
ROW5
ROW6
ROW7
COL0
COL1
COL2
COL3
COL4
COL5
COL6
COL7
!RESTORE
40/80
CAPS LOCK
GND
+5V
Feedbacks in common with control ports
Disable
http://github.com/svenpetersen1965

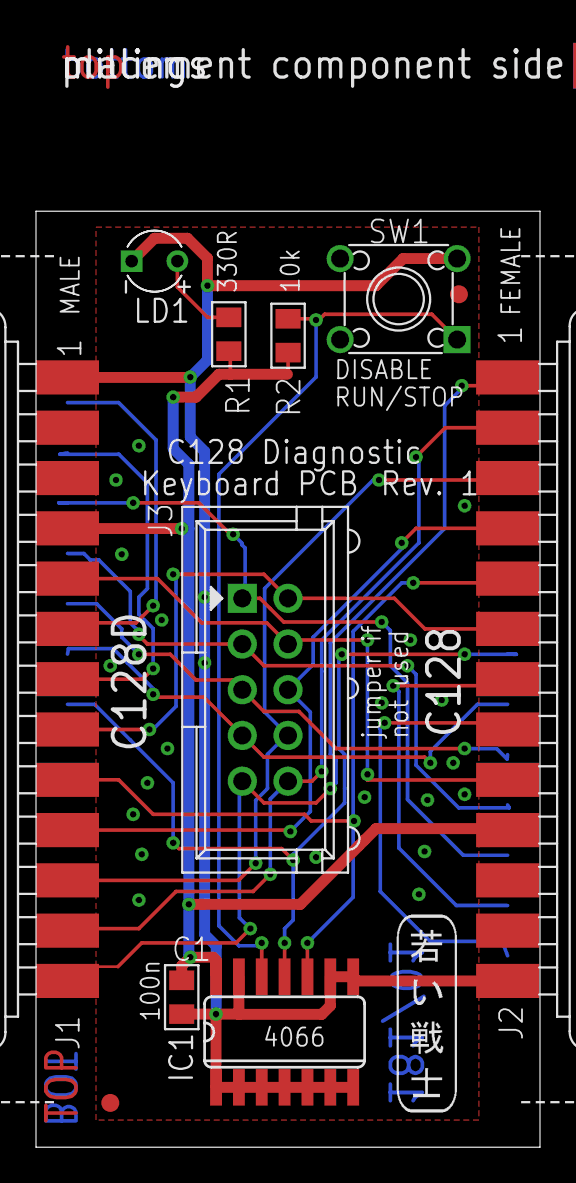
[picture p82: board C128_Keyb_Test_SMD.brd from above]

Board: 2 copper layers, 28.0 x 52.0 mm, 15 parts (1 on the bottom side), 20 nets.

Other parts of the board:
U$8: 2LAYER
U$9: PCB-TITLE/
U$10: SVEN_TAG
U$21, U$22: SMD_REF_R1MM

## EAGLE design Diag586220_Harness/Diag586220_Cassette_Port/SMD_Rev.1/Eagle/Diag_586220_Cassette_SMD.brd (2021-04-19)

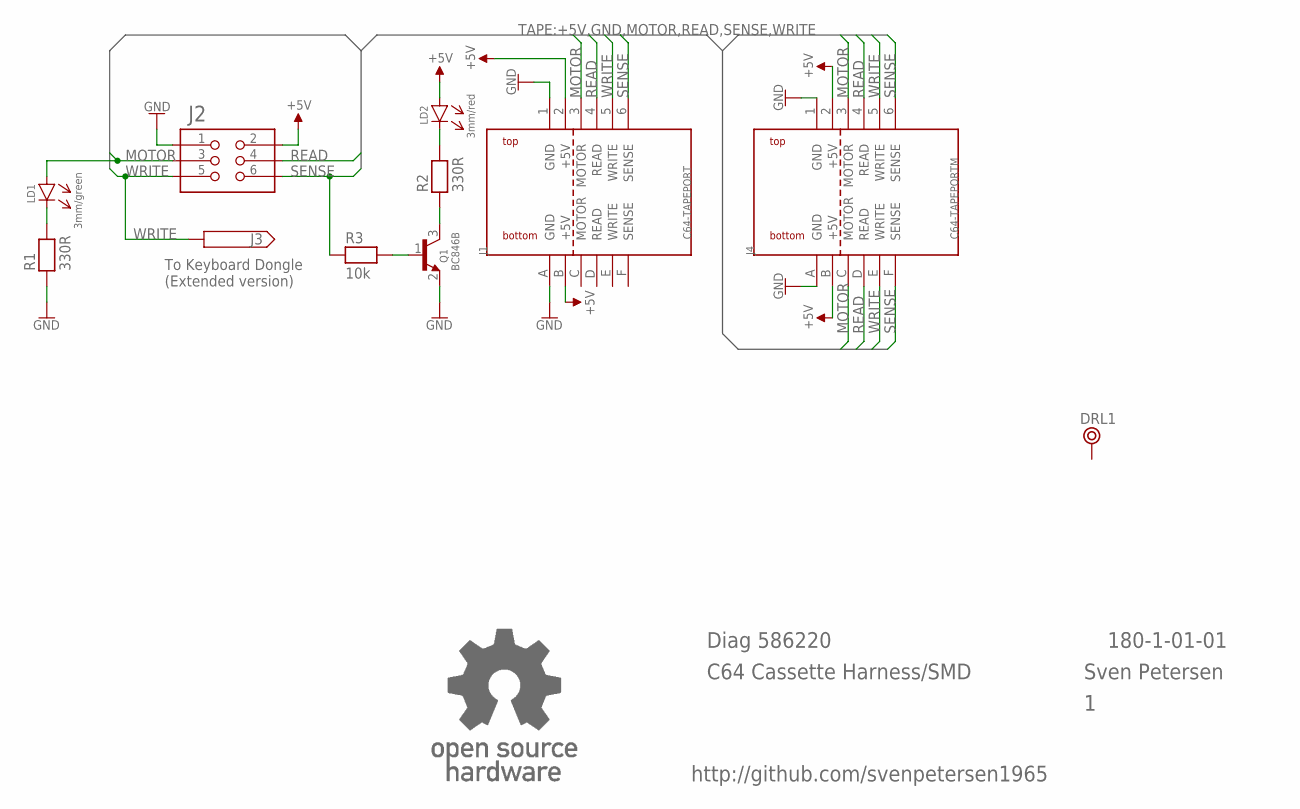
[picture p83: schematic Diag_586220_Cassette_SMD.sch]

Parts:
DRL1: BOHR3,5
J1: C64-TAPEPORT; TAPEPORT
J2: 2X03WV
J3: PINHD-1X1; 1X01
J4: C64-TAPEPORTM; TAPEPORT_M
LD1: 3mm/green; 3MM
LD2: 3mm/red; 3MM
Q1: BC846B; SOT23
R1, R2: 330R; 0805
R3: 10k; 0805
U$18: OPEN_SOURCE_HW; OPENHW

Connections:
+5V: J1.2 (+5V), J1.B (+5V), J2.2, J4.2 (+5V), J4.B (+5V), LD2.A
GND: J1.1 (GND), J1.A (GND), J2.1, J4.1 (GND), J4.A (GND), Q1.2 (E), R1.1
MOTOR: J1.3 (MOTOR), J2.3, J4.3 (MOTOR), J4.C (MOTOR), LD1.A
unnamed: LD1.C (K), R1.2
unnamed: Q1.1 (B), R3.2
unnamed: Q1.3 (C), R2.1
unnamed: LD2.C (K), R2.2
READ: J1.4 (READ), J2.4, J4.4 (READ), J4.D (READ)
SENSE: J1.6 (SENSE), J2.6, J4.6 (SENSE), J4.F (SENSE), R3.1
WRITE: J1.5 (WRITE), J2.5, J3.1, J4.5 (WRITE), J4.E (WRITE)

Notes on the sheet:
Diag 586220
C64 Cassette Harness/SMD
Sven Petersen
180-1-01-01
To Keyboard Dongle (Extended version)
http://github.com/svenpetersen1965

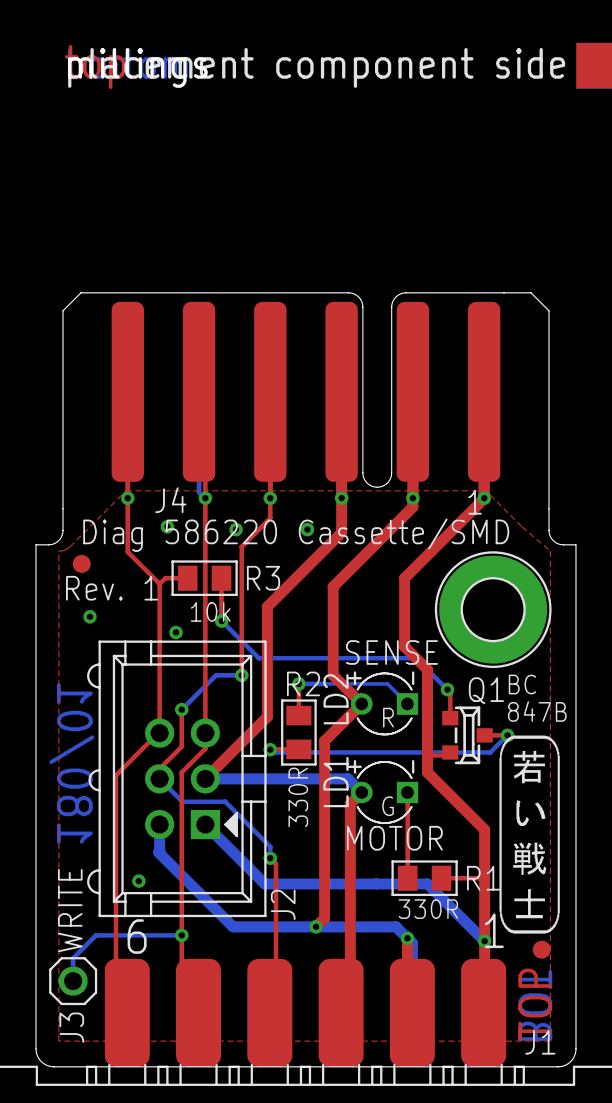
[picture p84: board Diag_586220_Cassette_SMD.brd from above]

Board: 2 copper layers, 30.0 x 43.0 mm, 17 parts (1 on the bottom side), 10 nets.

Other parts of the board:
U$5: PCB-TITLE/
U$6: 2LAYER
U$11: SVEN_TAG
U$19, U$20: SMD_REF_R1MM

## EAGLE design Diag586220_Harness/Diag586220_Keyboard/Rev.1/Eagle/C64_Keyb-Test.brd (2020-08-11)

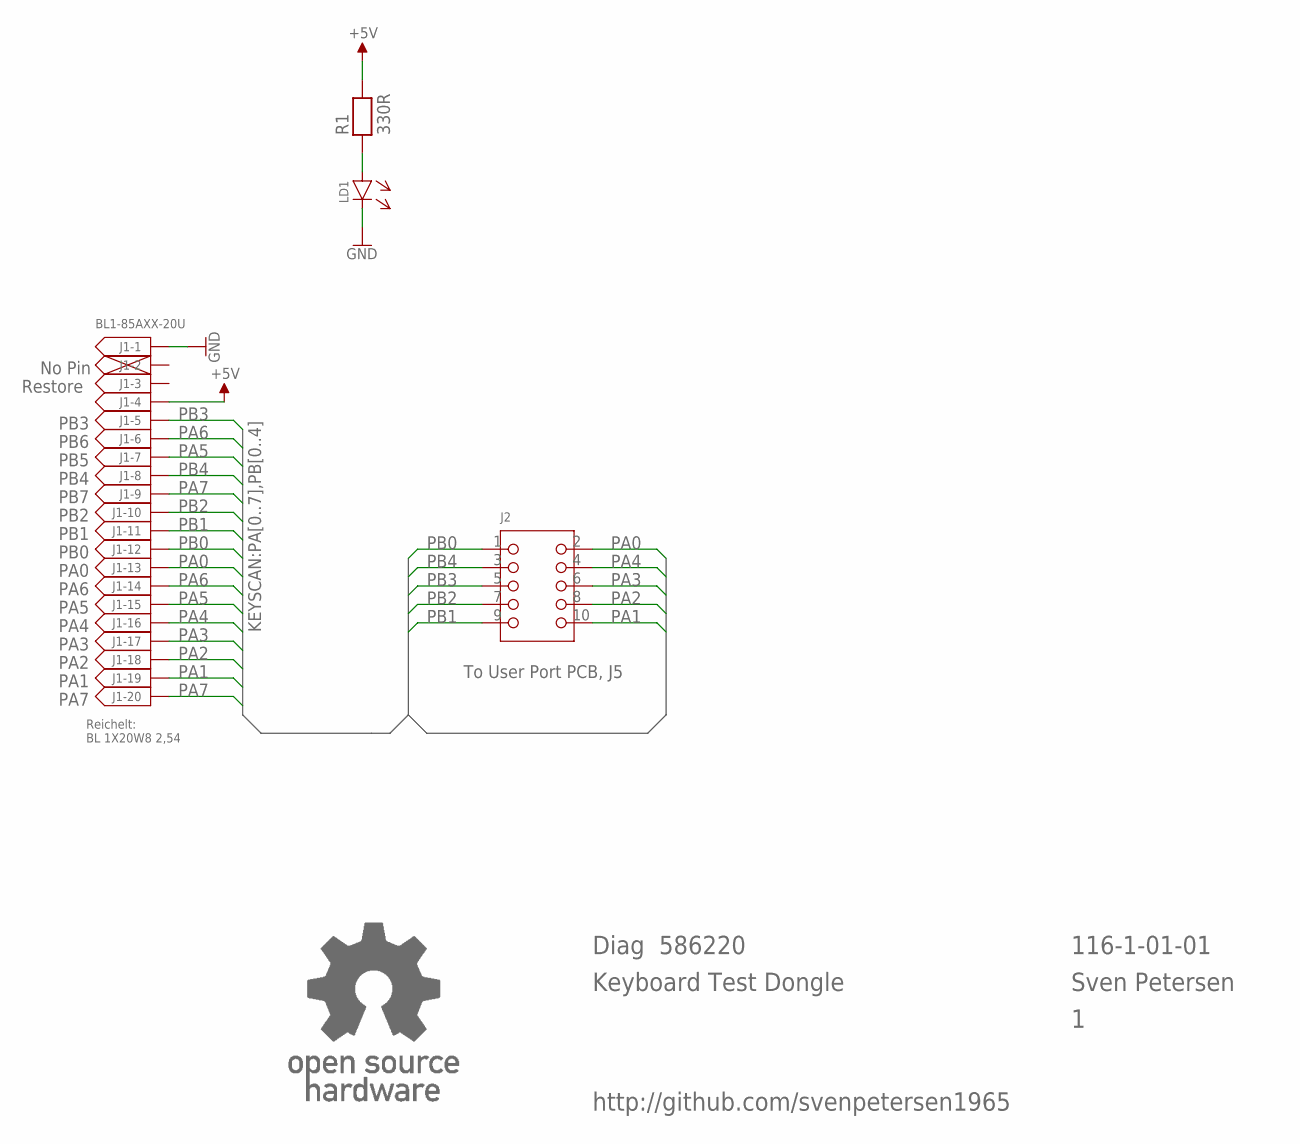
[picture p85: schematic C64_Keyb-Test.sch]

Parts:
J1: BL1-85AXX-20U
J2: 2X05WV
LD1: 3MM
R1: 330R; R-10
U$9: OPEN_SOURCE_HW; OPENHW

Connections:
+5V: J1.4, R1.2
GND: J1.1, LD1.C (K)
unnamed: LD1.A, R1.1
PA0: J1.13, J2.2
PA1: J1.19, J2.10
PA2: J1.18, J2.8
PA3: J1.17, J2.6
PA4: J1.16, J2.4
PA5: J1.7, J1.15
PA6: J1.6, J1.14
PA7: J1.9, J1.20
PB0: J1.12, J2.1
PB1: J1.11, J2.9
PB2: J1.10, J2.7
PB3: J1.5, J2.5
PB4: J1.8, J2.3

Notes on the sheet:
PB3
PB6
PB5
PB4
PB7
PB2
PB1
PB0
PA0
PA6
PA5
PA4
PA3
PA2
PA1
PA7
No Pin
Restore
Diag 586220
Keyboard Test Dongle
116-1-01-01
Sven Petersen
Reichelt: BL 1X20W8 2,54
To User Port PCB, J5
http://github.com/svenpetersen1965

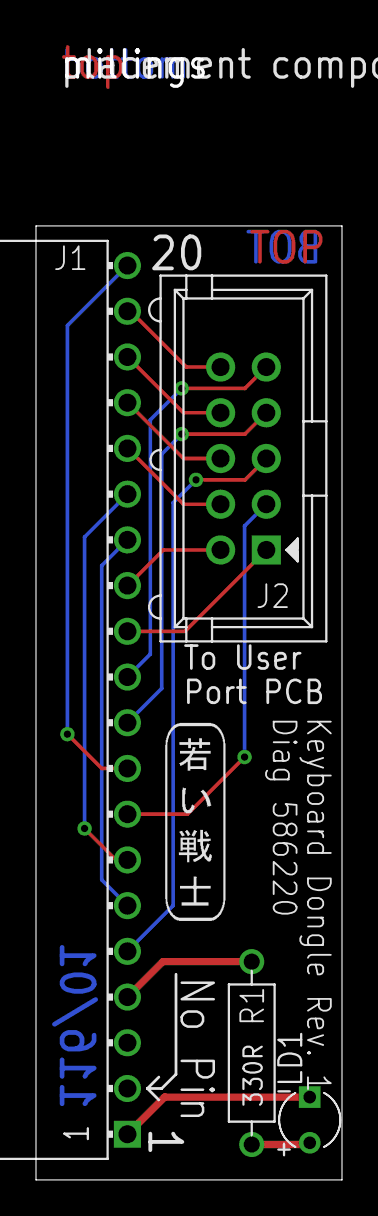
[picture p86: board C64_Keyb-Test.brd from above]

Board: 2 copper layers, 17.0 x 53.0 mm, 8 parts (1 on the bottom side), 16 nets.

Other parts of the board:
U$6: 2LAYER
U$7: PCB-TITLE/
U$8: SVEN_TAG

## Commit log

2019-03-14 Initial upload of Rev. 0
    Initial upload of Rev. 0
    [C64_Keyb-Test.brd, C64_Keyb-Test.sch, C64_Userport_Test.brd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]
2019-04-13 BOM v0.0 is obsolete
    BOM v0.1 is valid. Only a comment about a resistor is inserted, material is the same like v0.0
    [Diag586220_UserPort_BOM_v0_0.xlsx, Diag586220_UserPort_BOM_v0_1.xlsx]
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2019-11-07 Added the BOM created by ChrisToast89
    for Digikey N.America. This BOM was noch checked.
    [Diag_Harness_BOM_N.American_DIGIKEY_PN_by_ChrisToast89.xlsx]
2020-02-14 Add files via upload
    values from 120k to 110k and 320R to 316R
    [C64_Userport_Test.brd, C64_Userport_Test.sch]
2020-02-14 Add files via upload
    BOM v0.2
    [Diag586220_UserPort_BOM_v0_2.xlsx]
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2020-03-11 Add files via upload
    Rev. 1 released
    [Diag586220_Cassette_BOM_v1_0.xlsx, Diag_586220_Cassette.brd, Diag_586220_Cassette.dxf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]
2020-03-11 Rev. 1 released
    [C64_Keyb-Test.brd, C64_Keyb-Test.sch, Diag586220_KeyB_BOM_v1_0.xlsx]
2020-03-11 New release
    [C64_Keyb-Test-ext.brd, C64_Keyb-Test-ext.dxf, C64_Keyb-Test-ext.sch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]
2020-03-11 BOM v1.0
    [Diag586220_ext_KeyB_BOM_v1_0.xlsx]
2020-03-11 old BOM not required
    [Diag586220_ext_KeyB_BOM_v0_0.xlsx]
2020-03-11 New cases for Rev. 1 boards
    [Diag_CP_PCB_v1 v16.f3d, Diag_UP_PCB_v1 v9.f3d, diag cp bottom shell.stl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]
2020-03-11 Fixed the LD1 naming of LD2 in BOM
    [Diag586220_Cassette_BOM_v1_0.xlsx]
2020-03-11 Fixed LD2 in BOM
    [Diag586220_Cassette_BOM_v1_0.xlsx]
2020-03-15 Slightly new top shell allows higher sockets
    [diag_up_top.stl]
2020-03-15 Slightly modified top shell allows higher sockets
    [Diag_UP_PCB_v1 v10.f3d]
2020-03-15 re-arranged directories
    [C64_Userport_Test.dxf, Diag_CP v4.f3d, Diag_CP v7.f3d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]
2020-03-15 Slightly modified drawing
    The 10th wire of the ribbon cable is clearly shown as clipped now.
    [UP-CTRLP.DWG]
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2020-04-25 Added Information for C128 diagnostics
    The user port - cassette port cable and the user port - keyboard PCB cable need to be longer for C128. This information is now included.
    [UP-CASP.DWG, UP-KEYB.DWG]
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2020-05-03 Added a price calculation (estimation)
    The prices depend on the sources, you buy the parts from, so it is an estimation. It includes the cables, but not the 3D printed cases.
    [Diag586220_Cassette_BOM_v0_0.xlsx, Diag586220_KeyB_BOM_v0_0.xlsx, Diag586220_UserPort_BOM_v0_1.xlsx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]
2020-05-16 C128 Keyboard PCB released
    [C128_Diag_KeyB_BOM_v0_0.xlsx, C128_Diag_KeyB_BOM_v1_0.xlsx, C128_Keyb_Test.brd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]
2020-05-26 Added the price calculation for C128 Keyboard PCB
    [Diag_Harness_Rev1_complete_calc.xlsx]
2020-06-10 Gerbers Rev. 1a replace Rev. 1
    The silk screen was changed (C4)
2020-06-10 Silk screen modified (C4)
    [C64_Userport_Test.brd]
2020-06-10 Silk Screen modified
    Gerbers v1a replace v1
2020-06-10 Silk Screen modified
    [C64_Keyb-Test-ext.brd]
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2020-08-10 Rev. 2 released
    Revision 2 adds a switch option for SX-64. Default is still C64.
    [C64_Userport_Test.brd, C64_Userport_Test.dxf, C64_Userport_Test.sch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]
2020-08-10 Case for the SX-64 Switch option released
    This fits the User Port Case Rev. 1 and Rev. 2.
    [Diag_UP_SX64_PCB_v1 v6.f3z, diag_up_bottom_SX-64.stl, diag_up_top_SX-64.stl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]
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2021-04-19 SMD version of UP Rev. 2
    SMD Version for easier assembly, untested
    [C64_Userport_Test_SMD.brd, C64_Userport_Test_SMD.dxf, C64_Userport_Test_SMD.sch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]
2021-04-19 SMD Version of CP Rev. 1
    SMD version for easier assembly
    [Diag586220_Cassette_SMD_BOM_v1_0.xlsx, Diag_586220_Cassette_SMD.brd, Diag_586220_Cassette_SMD.dxf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]
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2021-12-25 Improved cases
    Rev. 1.1 is a slightly improved case for Rev. 1 boards and later
    [Diag_CP_PCB_v1 v21.f3d, Diag_UP_PCB_v1 v13.f3d, diag cp bottom shell.stl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]
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2022-01-03 Explained the Amphenol DB25S064TLF
    and added more sources and order numbers.
    [C128_Diag_KeyB_BOM_v1_1.xlsx]
2022-01-17 BOM Rev. 1.1
    R2 and R4 values have changed
    [Diag586220_ext_KeyB_BOM_v1_1.xlsx, Resiostor_calculation.xlsx]
2022-01-17 BOM v1.1
    R2 and R4 values are changed
    [C64_Keyb-Test-ext.brd, C64_Keyb-Test-ext.sch]
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2022-08-29 Case for Userport PCB Rev. 3
    There are two versions of this case:
    With voltmeter and without voltmeter.
    [diag_up_bottom.stl, diag_up_bottom_noVM.stl, diag_up_top.stl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]
2022-08-29 Case for Userport PCB Rev. 3
    [Diag_UP_PCB_v3 v24.f3z, Diag_UP_PCB_v3_noVM v12.f3d]
2023-02-05 Delete Diag586220_Harness/Case (3D print) directory
    Reorganizing the directory structure
    [C64_Userport_Test.dxf, Diag_CP v4.f3d, Diag_CP v7.f3d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]
2024-05-25 User Port Rev. 3 released
    [C64_Userport_Test.brd, C64_Userport_Test.dxf, C64_Userport_Test.sch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]
2024-05-25 UP SMD Rev. 3
    User Port SMD Rev. 3 released
    [C64_Userport_Test_SMD.brd, C64_Userport_Test_SMD.dxf, C64_Userport_Test_SMD.sch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]
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2024-07-18 Corrected Silkscreen (Value R3)
    R3 was still 316R and has to be 330R on the silk screen
2024-07-18 Fixed BOM
    The BOM v3.0 in pdf was obsolete before publishing, I have replaced the value of R3. It was correct in Eagle and the rest of the documentation.
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2024-11-06 New case with SX-64 option jumper
    Now, it is possible to print a case that provides access to the pin header and jumper for SX64/C64 configuration .
    [Diag_UP_PCB_v3_noVM_SX64 v9.f3d]
2024-11-06 Add files via upload
    Now, it is possible to print a case that provides access to the pin header and jumper for SX64/C64 configuration.
    [diag_up_bottom_noVM_SX.stl, diag_up_top_noVM_SX.stl]
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
